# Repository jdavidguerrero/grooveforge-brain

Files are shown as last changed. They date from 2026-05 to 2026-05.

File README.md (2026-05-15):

# GrooveForge Brain

> *"Una pieza de hardware. Cinco niveles de superpoderes. Tú decidís hasta dónde llegar."*

Boutique hybrid AI synthesizer — Teensy 4.1 + ESP32-S3 + discrete 2N3904 ladder filter.

**Retail: $599 USD · BOM: ~$110 · Margin: 82%**

---

## The 5 Levels (North Star)

```
NIVEL 0 — STANDALONE   → 6 synth engines + analog ladder filter + 12 signature FX
NIVEL 1 — + MIDI KB    → Scale Lock, Chord Recognition, Beat Follower (TinyML)
NIVEL 2 — + SLAVES     → E-Drum, Marimba, Air-Bamboo ecosystem (v1.x)
NIVEL 3 — + WIFI       → Patch search NL, progression suggester (cloud AI)
NIVEL 4 — + DAW        → GroovePilot VST3 mix-aware co-pilot
```

---

## Architecture

| Component | Chip | Role |
|---|---|---|
| Audio Brain | Teensy 4.1 (Cortex-M7 @ 600MHz) | Synth engines, FX, TinyML, MIDI |
| Network + UI | ESP32-S3 + GC9A01 1.28" display | WiFi, BLE, cloud sync, OTA |
| Audio Codec | SGTL5000 | 24-bit/48kHz ADC + DAC |
| Analog Filter | Discrete 2N3904 ladder (Moog 1970) | THE analog character |

Audio path: `Teensy → I2S → SGTL5000 → 2N3904 ladder → SGTL5000 ADC → USB Audio`

---

## Monorepo Structure

```
apps/
├── firmware-teensy/   C++ — Teensy 4.1 (PlatformIO)
├── firmware-esp32/    C++ — ESP32-S3 (PlatformIO)
├── bridge-protocol/   C headers — shared protocol
├── hardware/          KiCad PCB schematics
├── design/            Industrial design (3D + Figma)
├── training/          Python — TinyML model training
└── docs/              OpenSpec documentation (SSoT)
tools/
├── matching-jig/      Arduino — transistor Vbe matching jig
└── filter-cal/        Calibration scripts
```

---

## Quick Start

```bash
# Build Teensy firmware
cd apps/firmware-teensy && pio run -e teensy41 -t upload

# Build ESP32 firmware
cd apps/firmware-esp32 && pio run -e esp32s3 -t upload

# Run tests (native, no hardware needed)
pnpm test:native

# ML training
cd apps/training && uv sync && uv run pytest
```

---

## Documentation

All specs live in [`apps/docs/`](apps/docs/README.md):

| Doc | Content |
|---|---|
| [00-master-strategy.md](apps/docs/00-master-strategy.md) | Vision, pricing, North Star |
| [01-architecture.md](apps/docs/01-architecture.md) | Hardware + software spec |
| [02-bridge-protocol.md](apps/docs/02-bridge-protocol.md) | Teensy ↔ ESP32 ↔ VST3 protocol |
| [03-filter-design.md](apps/docs/03-filter-design.md) | Discrete 2N3904 ladder filter |
| [04-ai-architecture.md](apps/docs/04-ai-architecture.md) | 3-layer AI spec |
| [05-fx-architecture.md](apps/docs/05-fx-architecture.md) | 12 signature effects |
| [06-implementation-roadmap.md](apps/docs/06-implementation-roadmap.md) | Phase & sprint plan |

---

## Status

**Phase 0 — Foundation** · May 2026 · 🟡 In Progress

| Milestone | Status |
|---|---|
| Monorepo + CLAUDE.md + agents + skills | 🟢 Done |
| Sprint 1.1 — Hello Tone (440Hz via I2S) | 🔴 Pending |
| Sprint 1.2 — Multi-OSC + ADSR | 🔴 Pending |
| Sprint 1.3 — Transistor matching jig | 🔴 Pending |
| Sprint 1.4 — Filter protoboard | 🔴 Pending |

---

*GrooveForge Brain · Juan Guerrero (GPROG) · Bogotá, Colombia · 2026*

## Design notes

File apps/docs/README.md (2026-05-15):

# 📚 GrooveForge Brain — OpenSpec Documentation Pack

> Complete spec documentation for the GrooveForge Brain boutique synthesizer.
> **Owner:** Juan Guerrero (GPROG) · Bogotá, Colombia
> **Date:** May 15, 2026

---

## 📂 Document Index

Los documentos están organizados jerárquicamente. Leélos en orden para entender el producto completo:

| # | Document | Description |
|---|---|---|
| 00 | [GFD v3.0 — Master Strategy](./00-master-strategy.md) | **Single Source of Truth** — strategy, vision, decisions |
| 01 | [OpenSpec v0.3 — Technical Spec](./01-architecture.md) | Hardware + software technical specification |
| 02 | [Bridge Protocol v0.1](./02-bridge-protocol.md) | Communication protocol Teensy ↔ ESP32 ↔ VST3 |
| 03 | [Filter Design Spec v0.1](./03-filter-design.md) | Discrete 2N3904 ladder filter spec |
| 04 | [AI Architecture v0.1](./04-ai-architecture.md) | 3-layer AI architecture (TinyML + Cloud + DAW) |
| 05 | [FX Architecture v0.1](./05-fx-architecture.md) | 12 signature effects specification |
| 06 | [Implementation Roadmap v0.1](./06-implementation-roadmap.md) | 8-phase implementation plan |
| 07 | [Claude Code Bootstrap Prompt](./07-claude-code-bootstrap-prompt.md) | Initial prompt to setup the monorepo |

---

## 🎯 Quick Reference

### Product

- **Name:** GrooveForge Brain
- **Tagline:** *"Una pieza de hardware. Cinco niveles de superpoderes. Tú decidís hasta dónde llegar."*
- **Retail price:** $599 USD
- **BOM cost (qty 100):** ~$110 USD
- **Margin:** 82% @ qty 100

### Architecture

- **Audio brain:** Teensy 4.1 (Cortex-M7 @ 600MHz, bare-metal, Teensy Audio Library)
- **Network/UI co-processor:** ESP32-S3 with GC9A01 display integrated (Waveshare module)
- **Audio codec:** SGTL5000
- **Analog filter:** Discrete 2N3904 transistor ladder (Moog Minimoog 1970 design)
- **Toolchain:** PlatformIO

### The 5 Levels (North Star)

```
NIVEL 0 — STANDALONE (out of the box)
NIVEL 1 — + TECLADO MIDI (USB-A host)
NIVEL 2 — + SLAVES via pogo (futuro v1.x)
NIVEL 3 — + WIFI (ESP32-S3 cloud)
NIVEL 4 — + DAW (GroovePilot VST3)
```

### Roadmap (15 months)

| Phase | Period | Outcome |
|---|---|---|
| Phase 0 — Foundation | May 2026 | Monorepo + tooling |
| Phase 1 — Audio Core | Jun 2026 | First engine + analog filter |
| Phase 2 — Multi-engine + FX | Jul-Aug 2026 | 3 engines + 6-8 FX |
| Phase 3 — UI + Display | Sep-Oct 2026 | Full UI working |
| Phase 4 — MIDI + TinyML | Nov-Dec 2026 | Level 1 unlocked |
| Phase 5 — WiFi + Cloud | Jan 2027 | Level 3 unlocked |
| Phase 6 — DAW Bridge | Feb-Mar 2027 | Level 4 unlocked |
| Phase 7 — PCB + Manufacturing | Apr-May 2027 | Prototypes done |
| Phase 8 — Shipping | Jun 2027+ | Batch 1 shipped |

---

## 🚀 How to Use This Documentation

### For new contributors

1. Start with **00-master-strategy.md** to understand the product vision
2. Read **01-architecture.md** for the technical contract
3. Pick your area of interest:
   - Audio/DSP → 05-fx-architecture + 03-filter-design
   - AI/ML → 04-ai-architecture
   - Communication → 02-bridge-protocol
   - Implementation order → 06-implementation-roadmap

### For Claude Code setup

Use **07-claude-code-bootstrap-prompt.md** as the initial prompt when bootstrapping the monorepo. It will set up CLAUDE.md, agents, skills, and the full project structure.

### For sprint planning

Each sprint in **06-implementation-roadmap.md** has:
- Theory section to document
- Implementation tasks
- Demo evidence to capture

Follow the educational-first philosophy: theory doc → code → demo → learnings.

---

## 🛡️ Document Authority

If there's a conflict between documents:

1. **00 GFD** wins on strategy/business decisions
2. **01 OpenSpec** wins on technical contracts
3. **03 Filter / 02 Bridge / 05 FX / 04 AI** are authoritative on their respective subsystems
4. **06 Roadmap** is a living document — adjust as needed but don't violate constraints from 01

---

## 📝 Living Documents

All these documents are versioned. As decisions evolve, increment the version (v0.1 → v0.2) and update the change log inside the doc. Never silently modify — always note what changed.

---

## 🎵 The North Star

> Standalone, the GrooveForge Brain is a complete boutique synthesizer.
> Connect a MIDI keyboard → it becomes intelligent.
> Connect slaves → it becomes an ecosystem.
> Connect WiFi → it accesses cloud AI.
> Connect to your DAW → it becomes a co-pilot.
>
> One piece of hardware. Five levels of superpowers. You decide how far to go.

---

*GrooveForge Brain · OpenSpec Documentation · Juan Guerrero (GPROG) · 2026*

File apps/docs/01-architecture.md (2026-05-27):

# 📐 GrooveForge Brain — OpenSpec v0.3

> **Canonical technical specification** for GrooveForge Brain.
> **Methodology:** OpenSpec — spec-first, source of truth for all implementation.
> **Parent:** GFD v3.0 — Master Strategy & Spec (SSoT)
> **Status:** v0.3 final — May 15, 2026
> **Author:** Juan Guerrero (GPROG)

---

## 0. Document Purpose

Esta OpenSpec define **qué es el GrooveForge Brain** a nivel técnico, no comercial. Todo el firmware, hardware design, software architecture y testing se deriva de este documento. Si hay conflicto entre este doc y código/diseño, este doc gana.

El GFD v3.0 (parent) tiene la estrategia de producto. Este doc tiene el contrato técnico.

---

## 1. Product Overview

**Name:** GrooveForge Brain
**Tagline:** *"Una pieza de hardware. Cinco niveles de superpoderes. Tú decidís hasta dónde llegar."*

### 🌟 Arquitectura modular de superpoderes incrementales (NORTH STAR)

```
NIVEL 0 — STANDALONE (out of the box, $599)
  6 emuladores + ladder filter discreto + 12 FX = synth boutique completo

NIVEL 1 — + TECLADO MIDI (USB-A host)
  Scale Lock + Chord Recognition + Auto-Harmonization + Beat Follower (TinyML)

NIVEL 2 — + SLAVES via pogo (futuro v1.x)
  E-Drum + Marimba + Air-Bamboo = ecosistema modular inteligente

NIVEL 3 — + WIFI (cloud)
  Patch search NL + progression suggester + style transfer (cloud)

NIVEL 4 — + DAW (GroovePilot VST3)
  Mix-aware + frequency conflict + layer suggestions + smart macros
```

Cada nivel es opcional. El producto base ya es completo — las capas son expansión, no requisito.

### Pricing

- Standard retail: **$599 USD**
- Pre-order primeros 200: **$549 USD**
- PTDJA student price: **$549 USD**
- Bundle con GroovePilot Pro 12mo: **$649 USD**
- BOM total qty 100: ~$110 USD
- Margen unitario @ $599 / $110 = **82%**
- Margen qty 500-1000: BOM ~$87, margen sube a **85%**

### Toolchain: PlatformIO (no Arduino IDE)

- Mismo workflow para Teensy 4.1 + ESP32-S3
- Dependency management via platformio.ini
- CI/CD friendly + VS Code integration
- Repos separados: brain-teensy/ y brain-esp32/

### Differentiators

- Único synth boutique con AI integrado por capas (no add-on)
- Discrete transistor ladder real (Moog 1970 design) a precio asequible
- Seis arquitecturas clásicas en un instrumento
- 12 signature FX diseñados para live performance
- Arquitectura modular pogo pin extensible
- Estética boutique craft (guadua + aluminum)
- Audio latency <1ms (Teensy bare-metal, sin OS jitter)
- Toolchain unificado: PlatformIO

---

## 2. System Architecture v3.0

```
┌──────────────────────────────────────────────────────────────────┐
│                    GrooveForge Brain v3.0                         │
├──────────────────────────────────────────────────────────────────┤
│                                                                    │
│  ┌────────────────┐  AUDIO BRAIN                                  │
│  │   Teensy 4.1   │  - Cortex-M7 @ 600MHz + FPU + SIMD            │
│  │                │  - Teensy Audio Library (synth engines C++)    │
│  │                │  - I2S nativo al SGTL5000 (MCLK perfecto)      │
│  │                │  - USB-C composite: Audio + MIDI + CDC         │
│  │                │  - USB-A host: teclado MIDI externo            │
│  └────────┬───────┘                                                │
│           │ I2S                                                    │
│           ▼                                                        │
│  ┌────────────────┐  AUDIO CODEC                                  │
│  │   SGTL5000     │  - 24-bit/48kHz                                │
│  │                │  - ADC + DAC en un chip                        │
│  └────────┬───────┘                                                │
│           │ Analog signal                                          │
│           ▼                                                        │
│  ┌────────────────┐  ANALOG LADDER FILTER                         │
│  │  2N3904 Ladder │  - 4-pole discrete transistor ladder           │
│  │  + TL072 x2    │  - Moog Minimoog 1970 design                   │
│  │  + CD4066      │  - SW bypass via GUI (CD4066, pin 25)           │
│  │                │  - 8 matched 2N3904 pairs                      │
│  └────────┬───────┘                                                │
│           ▼                                                        │
│  ┌────────────────┐  AUDIO OUTPUTS                                │
│  │  TRS L/R 1/4"  │  Line out balanced                            │
│  │  + Headphones  │  3.5mm TRS                                    │
│  └────────────────┘                                                │
│                                                                    │
│  ┌────────────────┐                                                │
│  │ Encoders ALPS  │  GPIO directo al Teensy                       │
│  │ Kailh switches │  4 botones (B1-B4) + 3 encoders ALPS EC11      │
│  │ WS2812B LEDs   │  16 LEDs: 12 ring ENC NAV + 4 keycap underglow │
│  │ Volume pot     │  ADC analog                                   │
│  └────────────────┘                                                │
│                                                                    │
│             ↕ UART 921600 (Bridge Protocol)                       │
│                                                                    │
│  ┌────────────────┐  NETWORK + UI CO-PROCESSOR                    │
│  │ ESP32-S3 con   │  - Módulo Waveshare ESP32-S3-Touch-LCD-1.28   │
│  │ GC9A01 1.28"   │  - Display GC9A01 240×240 integrado            │
│  │ integrado      │  - WiFi 802.11 b/g/n                          │
│  │                │  - Bluetooth 5.0 LE                           │
│  │                │  - OTA updates                                │
│  │                │  - Cloud sync presets/profiles                │
│  │                │  - Web server local config                    │
│  └────────────────┘                                                │
│                                                                    │
│  ┌────────────────┐  MODULAR EXPANSION                            │
│  │ Pogo connector │  6-pin magnetic lateral                       │
│  │                │  GrooveForge Protocol v0.1 (I2C 400kHz)        │
│  │                │  Slaves: E-Drum, Marimba, Air-Bamboo (futuro) │
│  └────────────────┘                                                │
│                                                                    │
│  ┌────────────────┐  POWER                                        │
│  │  USB-C 5V in   │  - LiPo 3000mAh + IP5306                       │
│  │  + LiPo backup │  - LC filter audio rail (10µH + 100µF)         │
│  │                │  - Analog/digital ground star separation       │
│  └────────────────┘                                                │
└──────────────────────────────────────────────────────────────────┘
```

### 2.1 Audio Signal Path — Modo Synth vs Modo FX Processor

El GrooveForge Brain opera en **dos modos exclusivos**, alternados con doble-push
del encoder NAV (ver §3.4). Cada modo tiene un camino de señal distinto. El filtro
analógico 2N3904 vive en un **loop externo al SGTL5000**: el DAC alimenta la entrada
del filtro y el retorno del filtro entra al `LINE_IN`.

**Modo Synth** — el Teensy genera audio de síntesis; pasa por el filtro analógico:

```
Teensy engine ─I2S─▶ SGTL5000 DAC ─▶ LINE_OUT ─▶ [filtro 2N3904 ladder]
                                                         │
                          SGTL5000 LINE_IN ◀─ 74HC4053 ◀─┘
                                 │
                  ┌──────────────┴──────────────┐
                  ▼                             ▼
            ADC ─▶ Teensy                 jacks de salida
            (captura USB Audio,           (ruteo interno SGTL5000)
             análisis ML)
```

El filtro analógico está disponible para **todos los engines** (`03-filter-design.md §6.1`), cada uno con cutoff/resonance defaults calibrados para su carácter sonoro. En modo Synth, todos los engines pasan por el hardware de filtro; el CD4066 (GPIO 25) permite bypass por software. Los modelos ML (Beat Follower, Chord Recognizer, Key Detector) modulan el CV del filtro para comportamiento contextual (Sprint 5B.4).

**Modo FX Processor** (estilo Roland RMX-1000) — audio externo entra por el jack
`FX IN`; el Teensy aplica los 12 FX digitales; el filtro analógico queda fuera:

```
Jack FX IN 1/4" TRS ─▶ 74HC4053 ─▶ SGTL5000 LINE_IN ─▶ ADC ─▶ Teensy FX chain
                                                                     │
              jacks de salida ◀─ SGTL5000 ◀─ LINE_OUT ◀─ DAC ◀───────┘
```

**Switch de ruteo 74HC4053 (GPIO 27):** triple SPDT que selecciona la fuente del
`LINE_IN` del SGTL5000 — retorno del filtro (Synth) o jack `FX IN` (FX Processor).
Canal A = `LINE_IN_L`, canal B = `LINE_IN_R`, canal C spare. `GPIO 27` LOW = Synth,
HIGH = FX. Análisis completo: `apps/docs/theory/audio-routing-dual-mode.md`.

**Salida:** en ambos modos los jacks de salida se alimentan desde el SGTL5000 — el
ruteo interno por I2C selecciona la fuente según el modo. No requiere switch externo.

### Key architecture decisions

| Componente | v0.2 (anterior) | v0.3 (FINAL) | Razón |
|---|---|---|---|
| Audio brain | Pi Zero 2W (Linux) | **Teensy 4.1 (bare-metal)** | MCLK nativo, latencia <1ms, no Linux complexity |
| Display + WiFi | RP2040 + GC9A01 + ESP32 | **ESP32-S3 + GC9A01 integrado** | Un solo módulo, mejor integración |
| DSP framework | Pure Data Vanilla | **Teensy Audio Library C++** | Mejor performance, fit perfecto para 6 engines fijos |
| OS | Buildroot Linux | **Sin OS (bare-metal)** | Boot <2s, deterministic |
| AI inference | Local en Pi | **Vive en GroovePilot VST3** | AI no necesita estar en Brain |
| Filtro | 2N3904 ladder discreto | **2N3904 ladder discreto** | ✅ Mantiene authentic Moog sound |
| Codec | SGTL5000 | **SGTL5000** | ✅ Mismo, ahora con MCLK perfecto |

---

## 3. Hardware Specification

### 3.1 Bill of Materials (qty 100)

| Componente | Costo | Notas técnicas |
|---|---|---|
| **Teensy 4.1** | $32.00 | Cortex-M7 @ 600MHz, 1MB RAM, FPU, native I2S |
| **ESP32-S3 con GC9A01 1.28" integrado** | $22.00 | Waveshare ESP32-S3-Touch-LCD-1.28 o equivalente |
| SGTL5000 IC standalone | $4.00 | Chip bare en PCB producción + caps + clock |
| Oscilador 12.288 MHz DIP-4 3.3V | $2.00 | Opcional — Teensy provee MCLK nativo |
| ALPS EC11 encoders x3 | $6.30 | ENC L + ENC R + ENC NAV — todos con push integrado |
| Knobs aluminum CNC x2 + 1 central | $1.80 | ENC L/R: knobs estándar; ENC NAV: knob más prominente |
| Kailh Choc V2 Brown switches x4 | $1.20 | B1-B4 (dual set keycaps: negro instalado + transparente en sobre) |
| Keycaps PBT rectangular x4 negro | $1.20 | Instalados de fábrica — sin serigrafía (display da contexto) |
| Keycaps PBT rectangular x4 transparente | $0.80 | En sobre (dual set) |
| Keycap circular custom PETG/PBT x1 | $0.50 | ENC NAV — diseño Juan, icono ● grabado láser |
| WS2812B-2020 SMD x16 | $1.20 | 12 ring ENC NAV + 4 keycap underglow — cadena única, 1 pin Teensy |
| Volume pot 10kΩ log + knob | $1.00 | Panel mount + aluminum knob |
| USB-C + USB-A connectors | $0.80 | USB-C device, USB-A host |
| Audio jacks 1/4" TRS x2 (output L/R) | $3.60 | Switched ground |
| Audio jacks 1/4" TRS x2 (FX IN L/R) | $3.60 | Entrada Modo FX Processor — estéreo |
| Audio jack 3.5mm x1 (headphones) | $0.60 | Headphones |
| **74HC4053 triple SPDT analog switch** | **$0.35** | Ruteo audio Synth/FX — GPIO 27 |
| LiPo 3000mAh + IP5306 + LC filter | $9.00 | Battery operation + audio rail filter |
| **2N3904 NPN x12 (matched pairs)** | **$0.60** | 8 ladder + 4 spare/exp converter |
| **TL072 dual opamp x2** | **$0.80** | Input/output buffers + CV converter |
| **CD4066 quad analog switch** | **$0.30** | Software bypass control |
| ~~Toggle switch TPDT panel-mount~~ | ~~$0.50~~ | ~~Eliminado — bypass 100% software vía CD4066~~ |
| **Capacitors 1nF polystyrene x4 + passives** | **$1.30** | Filter timing caps + trimmers + resistors |
| ~~Resonance pot 10kΩ log~~ | ~~$0.80~~ | ~~Eliminado — resonance controlada por ENC R (digital)~~ |
| **Filter PCB sub-block 30x40mm** | **$0.50** | 2-layer |
| Pogo connector 6-pin magnetic | $1.50 | Würth o equivalente |
| PCB principal 4-layer 180x100mm | $6.00 | Audio + digital + power planes |
| Enclosure PETG print | $5.00 | Color-stable PETG |
| Aluminum top panel CNC | $6.00 | 2mm anodizado, Bogotá |
| Guadua panel finished | $2.50 | Local sourcing + sealing |
| Passives + cables + screws + misc | $4.50 | Resistores + caps + standoffs |
| **Subtotal componentes** | **~$113** | Incluye 74HC4053 + jack FX IN 1/4" (Modo FX Processor) |
| Ensamblaje + QC + filter cal | $10.00 | Filter cal 5-7 min/unidad |
| **TOTAL per unit (qty 100)** | **~$123** | |

> **Volumen 500-1000u:** BOM baja a ~$90
> **Volumen 1000+:** BOM baja a ~$78

### 3.2 Power Architecture

```
USB-C 5V input ──┬──▶ IP5306 (charge)
                 │       │
                 │       ▼
                 │   LiPo 3.7V 3000mAh
                 │       │
                 │       ▼
                 │   IP5306 (boost 5V)
                 │       │
                 ▼       ▼
              ┌──────────────┐
              │  Power Rail   │
              │     5V        │
              └──────┬───────┘
                     │
           ┌─────────┼─────────┬─────────┐
           ▼         ▼         ▼         ▼
        Teensy 4.1  ESP32-S3  LCD/LEDs  USB-A host
        (5V→3.3V    (5V→3.3V             (5V passthrough)
        internal)   internal)

        ┌──────────────────────┐
        │   LC Filter audio    │
        │   10µH + 100µF       │
        │   MANDATORY          │
        └──────────┬───────────┘
                   ▼
              ┌──────────┐
              │ SGTL5000 │
              │ + 2N3904 │ ladder filter
              │ + TL072  │
              └──────────┘

        Analog GND ━━━ star ground point ━━━ Digital GND
```

**Critical rules:**
- LC filter (10µH + 100µF) entre digital 5V y audio rail
- Star ground: analog GND y digital GND conectan en UN punto físico cerca del SGTL5000
- Teensy y ESP32-S3 corren de digital 5V (regulación interna a 3.3V)
- SGTL5000 + filter discreto corren de audio 5V filtered
- Battery debe soportar pico ~500mA (Teensy + ESP32 + LEDs + WiFi TX simultáneo)

### 3.3 Pin Mapping

**Teensy 4.1 GPIO usage:**

| Pin | Function | Conexión |
|---|---|---|
| 23 | MCLK out | SGTL5000 master clock (nativo desde Teensy I2S1_MCLK) |
| 7 | I2S1_TX_DATA0 (OUT1A) | SGTL5000 DAC input |
| 8 | I2S1_RX_DATA0 (IN1) | SGTL5000 ADC output |
| 20 | I2S1_LRCLK | SGTL5000 LRCLK |
| 21 | I2S1_BCLK | SGTL5000 BCLK |
| 18 | I2C1 SDA | SGTL5000 control |
| 19 | I2C1 SCL | SGTL5000 control |
| 0 | UART RX | ← ESP32-S3 TX |
| 1 | UART TX | → ESP32-S3 RX |
| 2-5 | GPIO | 4 Kailh Choc V2 switches B1-B4 (pulled-up) |
| 10-11 | GPIO | ENC L: A / B (rotary phases) |
| 12 | GPIO | ENC L: SW (push — filter bypass toggle) |
| 13 | GPIO | ENC R: A |
| 14 | GPIO | ENC R: B |
| 15 | GPIO | ENC R: SW (push — resonance reset a 0) |
| 16 | GPIO | ENC NAV: A |
| 17 | GPIO | ENC NAV: B |
| 26 | GPIO | ENC NAV: SW (push — confirm / AI·Action / double-push = mode switch) |
| 25 | GPIO | Filter bypass control (CD4066 enable — ENC L push via firmware) |
| 27 | GPIO | 74HC4053 mode select — ruteo audio Synth/FX (LOW=Synth, HIGH=FX) |
| 28 | WS2812B DIN | 16 LEDs cadena única: 12 ring ENC NAV + 4 keycap underglow |
| A0 (14) | ADC | Volume pot read |
| 36 | GPIO | Pogo INT in (slave interrupt) |
| 37/38 | I2C2 SDA/SCL | Pogo bus master (slaves) |
| 39 | GPIO | USB host mode select |

> **Nota I2S (Teensy 4.x):** los pines de datos I2S son 7 (`SAI1 OUT1A`, TX → DAC)
> y 8 (`SAI1 IN1`, RX ← ADC) — los del Audio Shield Rev D2. La Rev C / Teensy 3.x
> usaba 22/13; con este mapping los pines 13 y 22 quedan libres.

**ESP32-S3 (Waveshare ESP32-S3-Touch-LCD-1.28):**

| Pin | Function | Conexión |
|---|---|---|
| GPIO 17 | UART TX (Serial1) | → Teensy RX (pin 0) |
| GPIO 16 | UART RX (Serial1) | ← Teensy TX (pin 1) |
| GPIO 43 | UART0 TX (Serial debug) | USB-UART bridge interno — NO usar para bridge |
| GPIO 44 | UART0 RX (Serial debug) | USB-UART bridge interno — NO usar para bridge |
| GPIO 7/8/9/10/11/12 | SPI display | GC9A01 (internal connection) |
| GPIO 13 | Touch I2C SDA | Touch controller (si touch version) |
| GPIO 14 | Touch I2C SCL | Touch controller |
| GPIO 18 | Display backlight PWM | GC9A01 backlight |
| (Internal) | WiFi + BT | 802.11 b/g/n + BT 5.0 LE |

### 3.4 UI Controls Spec — Panel v5 Final

> **SSoT:** Notion "Hardware UI Spec — CERRADO (Panel v5 Final)" · Mayo 17, 2026

**Filosofía:** minimalista boutique — 3 encoders + 4 botones + 1 vol pot. Más cercano al OP-1 que al Elektron.

#### Inventario de controles

| ID | Tipo | Turn | Push |
|---|---|---|---|
| ENC L | ALPS EC11 | Synth: Cutoff / FX: Dry-Wet | Filter bypass toggle |
| ENC R | ALPS EC11 | Synth: Resonance / FX: Depth/param principal | Resonance reset a 0 |
| ENC NAV | ALPS EC11 | Navegar menú / páginas / FX | 1× confirm/AI·Action · 2× rápido = modo SYNTH↔FX |
| B1-B4 | Kailh Choc V2 Brown | — | Synth: OSC/ENV/LFO/PRESET · FX: INSERT/SEND/MASTER/slot |
| VOL | Pot 10kΩ log | Volumen salida (siempre, no cambia con modo) | — |

#### Modo SYNTH

```
ENC L    → Cutoff del filtro analógico discreto 2N3904
ENC R    → Resonance
ENC NAV  → Navegar páginas del synth (OSC / ENV / LFO/MOD / ENGINE / PRESET)
ENC L push  → Filter bypass CD4066 ON/OFF (pin 25)
ENC R push  → Resonance reset a 0
ENC NAV push → Confirm / AI·Action (escala al nivel activo: 0=menú, 1=Scale Lock, 3=cloud, 4=DAW)
B1=OSC · B2=ENV · B3=LFO/MOD · B4=PRESET/ENGINE
```

#### Modo FX (RMX-1000 inspired)

```
ENC L    → Dry/Wet del FX activo
ENC R    → Parámetro principal del FX activo (definido por cada FX)
ENC NAV  → Scroll entre los 12 FX disponibles
ENC NAV push → Activar/desactivar FX seleccionado
B1=INSERT · B2=SEND · B3=MASTER · B4=FX slot favorito
```

**Cambio de modo:** doble push ENC NAV (≤ 2 s)

#### LED ring ENC NAV (12× WS2812B-2020 SMD)

| Estado | Animación | Color |
|---|---|---|
| Synth mode | Pulso suave | Teal `#1D9E75` |
| FX mode | Pulso suave | Purple `#534AB7` |
| Cambio de modo | Sweep 360° | Teal → Purple |
| IA procesando | Giro rápido | Teal brillante |
| Sugerencia lista | 3 pulsos + fijo | Teal |
| DAW conectado | Fijo | Purple |
| Error / sin conexión | Pulso lento | Rojo |
| Scale Lock activo | Fijo | Verde |

#### ENC R mapping por FX (parámetro principal en FX mode)

| FX | ENC L (Dry/Wet) | ENC R (Depth/param) |
|---|---|---|
| Cymatic Resonator | Mix | Resonance (Q) |
| Granular Cloud | Mix | Size (grain duration) |
| Ghost Echo | Mix | Feedback |
| Spectral Smear | Mix | Smear time |
| **Tape Saturate** | **Mix** | **Drive** |
| Bit Sculpt | Mix | Bits |
| Modal Reverb | Mix | Decay |
| Phase Chorus | Mix | Depth |
| Pitch Mosaic | Mix | Interval 1 |
| Spring + Plate | Mix | Decay |
| Glitch Stutter | Mix | Pattern division |
| Sub Genesis | Mix | Sub level |

### 3.5 Discrete 2N3904 Ladder Filter Design

**Topology:** 4-pole low-pass transistor ladder (Moog Minimoog 1970 reference)

Ver doc separado: **🎚️ Filter Design Spec v0.1** para detalles completos.

**Specifications:**
- Cutoff range: 20Hz - 20kHz (5+ decades)
- Resonance: 0 (flat) to self-oscillation
- V/oct tracking: ±10 cents over 5 octaves (post-calibration)
- Bypass: CD4066 software bypass controlado por GUI (Bridge Protocol → Teensy pin 25)
- Input impedance: 100kΩ
- Output level: matched a SGTL5000 ADC input range (~1Vrms line level)
- THD @ 1kHz, 0dBu: <0.5% (low resonance), <2% (high resonance, intentional)
- Self-oscillation threshold: 80% resonance pot ±5%

**Engine routing per engine:**

| Engine | Filter default | Sound | User override |
|---|---|---|---|
| Moog Model D | ON | Auténtico Moog | Yes |
| Juno-106 | ON | Juno + Moog warmth | Yes |
| Prophet-5 | ON | Prophet + Moog warmth | Yes |
| OB-6 | ON | OB-6 + Moog warmth | Yes |
| DX7 | **OFF** | Clean FM | Yes (toggle ON for "warmed FM") |
| ARP 2600 | ON | ARP + Moog warmth | Yes |

### 3.6 Top Panel PCB Architecture

> **Decisión:** 2026-05-27. Documentado por primera vez aquí.

#### Problema

Los encoders (ENC1, ENC2, ENC NAV) y los botones (B1-B4) están montados sobre el top
panel de aluminio, que tiene **BODY_H_F=42mm de altura**. La PCB principal (Teensy) está
en el fondo del PETG body. Conectar componentes del top panel directamente a la main PCB
requeriría cables cortos en ángulo o una PCB rígida que no cabe en el espacio.

#### Decisión: 2-PCB approach

| PCB | Nombre | Dimensión estimada | Contenido | Conexión |
|-----|---|---|---|---|
| Main PCB | `groovebrain-main` | 168×88mm | Teensy 4.1, SGTL5000, power, jacks, USB | — |
| Top Panel PCB | `groovebrain-panel` | ~130×25mm | ENC1, ENC2, ENC NAV, B1-B4, WS2812B ring | JST ribbon → main PCB |

**Top Panel PCB** es una PCB delgada (~25mm de alto) que se monta bajo el aluminio:
- Footprints EC11 para los 3 encoders (ENC NAV tiene 4 pads extra para WS2812B data + 5V)
- Footprints Kailh Choc V2 para los 4 botones (retroiluminados — 2 pads extra por switch)
- Header JST-SH 1.0mm (o similar) de N pines hacia la main PCB
- 4 agujeros M2.5 para tornillos que fijan la PCB bajo el panel de aluminio

**ENC NAV vs ENC1/ENC2 en la misma PCB:**
- ENC NAV footprint: 3 pines encoder + 2 pines LED ring (data WS2812B + GND)
- ENC1/ENC2 footprint: solo 3 pines encoder — el pad de ring simplemente no se popula
- Una sola PCB sirve para las 3 posiciones de encoder

#### Layout del panel v0.5 (SSoT)

```
Y_panel (0=trasero, 100=frontal)
  100 ──────────────────────────────────────────────── frente del instrumento
        [VOL]                               (X=22, Y=14)
   22   ──────── [ENCNAV]  ────────────────            (X=90, Y=22)
        ───── LED ring ────                            (X=90, Y=22, Ø32mm)

   44   [ENC1]  [B2]       DISPLAY   [B4]  [ENC2]     Y=44: botones inferiores
        X=22    X=52        X=90      X=128  X=158
   55   [ENC1]                               [ENC2]    Y=55: encoders laterales
   60           DISPLAY                                Y=60: display center
   66   [ENC1]  [B1]       DISPLAY   [B3]  [ENC2]     Y=66: botones superiores

  ...
    0 ──────── panel trasero
```

**Asignación de botones:**

| ID | Posición | X_panel | Y_panel | Modo SYNTH | Modo FX |
|----|---|---|---|---|---|
| B1 | col izq, superior | 52mm | 66mm | OSC | INSERT |
| B2 | col izq, inferior | 52mm | 44mm | ENV | SEND |
| B3 | col der, superior | 128mm | 66mm | LFO/MOD | MASTER |
| B4 | col der, inferior | 128mm | 44mm | PRESET/ENGINE | FX slot fav |

#### Módulo display (Waveshare ESP32-S3-Touch-LCD-1.28) — dimensiones verificadas por datasheet

| Parámetro | Valor | Fuente |
|---|---|---|
| Vidrio OD (LENS OD) | Ø38.51mm | Waveshare datasheet |
| Viewing area activa | Ø35.67mm | Waveshare datasheet |
| PCB circular | Ø41mm | Waveshare datasheet |
| Stack TP+LCD height | 3.58mm | Waveshare datasheet |

**Concepto de instalación (corrección v0.5):** El módulo va **debajo** del panel de aluminio:
- El cutout Ø36mm en el aluminio es una **ventana** — ni el vidrio (38.51mm) ni el PCB (41mm) pasan por él
- El vidrio del módulo se presiona contra la **cara inferior** del aluminio, mirando hacia arriba
- El labio del vidrio (38.51mm OD) impide que el módulo caiga por el cutout (36mm < 38.51mm)
- Desde arriba: el usuario ve el display circular recesado 2mm (grosor del aluminio) — efecto estético limpio
- El **display bracket (Part 05)** retiene el módulo desde abajo, presionándolo contra el aluminio:
  - Cavity circular ≥ Ø41mm para el PCB
  - Altura = BRACKET_H = 15mm (desde PCB principal hasta cara inferior del top panel)

Los pines UART (GPIO43/44) del ESP32-S3 se cablan directamente a la main PCB (Teensy)
via cable que desciende por el interior del bracket y el PETG body.
El Top Panel PCB **no lleva** conector para la pantalla.

#### Prototipo v1 vs PCB v1.0

| Fase | Implementación |
|---|---|
| **Prototipo v1** (actual) | Cables directos de cada encoder/botón a la main PCB. Sin Top Panel PCB. Complejidad de cableado: ~18 señales. |
| **PCB v1.0** | Top Panel PCB fabricada. JST ribbon de 18-22 pines. Cableado limpio. |

---

## 4. Software Architecture

### 4.1 Teensy 4.1 (Audio Brain)

**Framework:** PlatformIO + Arduino framework + Teensyduino + Teensy Audio Library

**Synth engines (v1.0 ship con 3, expandible):**

| Engine | Status | Implementation |
|---|---|---|
| Moog Model D | Ship v1.0 | AudioSynthWaveform x3 + AudioMixer4 + AudioEffectEnvelope + filter routing |
| Juno-106 | Ship v1.0 | AudioSynthWaveform + sub osc + AudioEffectChorus + filter routing |
| Prophet-5 | Ship v1.0 | AudioSynthWaveform x2 + cross-mod + filter routing |
| OB-6 | v1.1 (Q1 2027) free update | AudioSynthWaveform x2 + AudioSynthWaveformDc + filter |
| DX7 | v1.2 (Q2 2027) free update | AudioSynthWaveformPWM x6 (FM operators) + filter bypass |
| ARP 2600 | v1.3 (Q3 2027) free update | AudioSynthWaveform + AudioEffectRingMod + filter |

**Polyphony targets:**
- Moog Model D: 6 voces simultáneas
- Juno-106: 8 voces simultáneas
- Prophet-5: 5 voces simultáneas
- CPU usage @ 6 voces simultáneas: ~30% Teensy 4.1
- Headroom para FX adicionales: ~70%

### 4.2 ESP32-S3 (Network + UI Co-processor)

**Framework:** PlatformIO + Arduino (ESP32 board package) + LVGL

**Tasks:**
- WiFi management (connect, reconnect, OTA check)
- Bluetooth LE (MIDI BLE optional, file transfer)
- HTTP client to grooveforge.com cloud API
- Local web server para configuration (port 80, mDNS as `groovebrain.local`)
- Display driver GC9A01 (rendering UI based on state from Teensy)
- UART communication con Teensy @ 921600 baud (Bridge Protocol)

### 4.3 Bridge Protocol v0.1

Protocolo binario sobre UART (Teensy ↔ ESP32) y USB-CDC (Teensy ↔ VST3 host).

```
[CMD][LEN][SEQ][PAYLOAD][CRC8]
```

Ver doc separado: **🔌 Bridge Protocol v0.1 — Spec**

**Communication paths:**

```
VST3 plugin ←─ USB-CDC ─→ Teensy 4.1 ←─ UART ─→ ESP32-S3 ←─ WiFi ─→ GroovePilot cloud
```

Teensy es el master del Bridge Protocol. ESP32 actúa como proxy network layer.

### 4.4 OTA Updates

- ESP32-S3 maneja WiFi connectivity
- Check de updates contra https://updates.grooveforge.com
- ESP32 descarga firmware delta + checksum
- ESP32 puede flashear Teensy via UART + reset GPIO (Teensy bootloader UART)
- ESP32 flashea su propio firmware (OTA partition)
- Rollback automático si boot falla 3 veces consecutivas

---

## 5. Acceptance Criteria

### 5.1 Hardware acceptance (per unit, prod line)

- [ ] Boot completo a synth selector en <2 segundos
- [ ] Audio out detectable en 1/4" L/R con test tone (-12dBFS sin distortion)
- [ ] USB-C reconocido como composite device (Audio + MIDI + CDC) en macOS/Win/Linux
- [ ] USB-A host detecta teclado MIDI clase-compliant
- [ ] WiFi conecta a network conocido en <5 segundos
- [ ] Battery dura ≥2.5h en modo standalone con volumen 75%
- [ ] LiPo charge time <3h desde 0% a 100%
- [ ] LC filter mide >40dB atenuación noise digital en audio rail @ 100MHz
- [ ] Display GC9A01 muestra splash en <500ms post-boot
- [ ] 6 Kailh switches responden con WS2812B feedback inmediato
- [ ] 2 encoders track ±1 detent precision
- [ ] Action button + LED ring funcional
- [ ] Pogo connector multimetro: continuidad 6 pines, no shorts
- [ ] **Filter: cutoff sweep audible 20Hz-20kHz**
- [ ] **Filter: self-oscillates con resonance al 80% pot**
- [ ] **Filter: software bypass CD4066 sin clicks audibles al switch (GUI → pin 25)**
- [ ] **Filter: V/oct tracking ±20 cents over 5 octaves (post-calibration)**

### 5.2 Software acceptance (per release)

- [ ] Boot time Teensy + ESP32 < 2 segundos
- [ ] Audio latency: USB MIDI input → audio out <5ms p95
- [ ] Engine polyphony: Moog 6 voces, Juno 8 voces, Prophet 5 voces sin xruns
- [ ] CPU usage Teensy ≤60% en uso normal
- [ ] Bridge Protocol latency: command → ack <50ms p95
- [ ] OTA update completo (download + flash + reboot) <5 min
- [ ] OTA rollback funciona si boot falla 3 veces
- [ ] Pogo slave hot-plug detected en <5 segundos
- [ ] WiFi reconnect automático tras disconnect

### 5.3 Audio quality acceptance

- [ ] THD+N audio path total <0.1% @ 1kHz, -12dBFS (filter bypass)
- [ ] SNR audio path >90dB A-weighted
- [ ] Frequency response: ±0.5dB de 20Hz-20kHz (filter bypass)
- [ ] Channel crosstalk L/R <-80dB @ 1kHz
- [ ] Noise floor con todo conectado silenciado: <-95dBFS
- [ ] Filter resonance peak: ≥+20dB sobre nominal at self-oscillation
- [ ] Filter V/oct tracking: ±20 cents over 5 octaves (post-calibration)

---

## 6. Build Instructions (Dev)

### 6.1 Bootstrap dev environment

```bash
# Instalar VS Code + PlatformIO extension
# https://platformio.org/install/ide?install=vscode

# Clone repos
git clone git@github.com:gprog/grooveforge-brain.git
cd grooveforge-brain
```

### 6.2 First audio test (Teensy + Audio Shield)

```cpp
#include <Audio.h>
#include <Wire.h>
#include <SPI.h>

AudioSynthWaveform    sine;
AudioOutputI2S        audioOut;
AudioControlSGTL5000  codec;

AudioConnection c1(sine, 0, audioOut, 0);
AudioConnection c2(sine, 0, audioOut, 1);

void setup() {
    AudioMemory(8);
    codec.enable();
    codec.volume(0.5);
    sine.begin(WAVEFORM_SINE);
    sine.frequency(440);
    sine.amplitude(0.8);
}

void loop() {}
```

`platformio.ini`:
```ini
[env:teensy41]
platform = teensy
board = teensy41
framework = arduino
lib_deps =
    PaulStoffregen/Audio
    PaulStoffregen/Encoder
    PaulStoffregen/Bounce2
monitor_speed = 115200
build_flags =
    -DUSB_MIDI_AUDIO_SERIAL
```

Flash al Teensy 4.1. Conectar headphones al jack del Audio Shield. Tono 440Hz inmediato.

### 6.3 ESP32-S3 display test

```cpp
#include <TFT_eSPI.h>
TFT_eSPI tft = TFT_eSPI();

void setup() {
    tft.init();
    tft.setRotation(0);
    tft.fillScreen(TFT_BLACK);
    tft.setTextColor(TFT_GREEN);
    tft.setTextSize(2);
    tft.setCursor(40, 100);
    tft.print("GROOVEFORGE");
    tft.setCursor(70, 130);
    tft.print("BRAIN v3.0");
}

void loop() {}
```

---

## 7. Roadmap & Milestones (overview)

Detalles en doc separado: **📖 Implementation Roadmap v0.1**

| Milestone | Target | Status |
|---|---|---|
| Teensy 4.1 + Audio Shield primer tono via Audio Library | Semana 1 | 🔴 Pending |
| Filter discreto 2N3904 protoboard + matching jig Arduino | Semana 2-3 | 🔴 Pending |
| Primer engine Moog Model D en Teensy Audio Library | Semana 4 | 🔴 Pending |
| A/B test: filter digital vs filter discreto analog | Semana 5 | 🔴 Pending |
| ESP32-S3 display + UART communication con Teensy | Semana 6 | 🔴 Pending |
| Engine #2 (Juno-106) + Engine #3 (Prophet-5) | Mes 3-4 | 🔴 Pending |
| PCB v0.1 schematic completo en KiCad | Mes 5 | 🔴 Pending |
| PCB v0.1 fabricated + prototype hand-soldered | Mes 6 | 🔴 Pending |
| End-to-end prototype completo | Mes 7 | 🔴 Pending |
| Pre-order page abierta | Mes 8 | 🔴 Pending |
| Alpha 10 units enviadas a beta testers | Mes 9 | 🔴 Pending |
| Manufactura batch 1 JLCPCB SMT | Mes 11 | 🔴 Pending |
| Shipping batch 1 | Mes 12 | 🔴 Pending |
| v1.1 OB-6 engine free update | Mes 14 | 🔴 Pending |

---

## 8. Risks & Mitigations

| Riesgo | Probabilidad | Impacto | Mitigación |
|---|---|---|---|
| Teensy 4.1 supply crisis | Baja | Alto | PJRC supply stable. Alternative: STM32H7 con custom audio framework. |
| ESP32-S3 supply crisis | Baja | Medio | Alternativa: RP2040 + display GC9A01 separado |
| Teensy Audio Library limitations | Baja | Medio | Alternativa: bare-metal con CMSIS-DSP. PJRC mantiene library activamente. |
| Filter discreto matching más complejo de lo esperado | Media | Bajo | Jig procedure documentado. 10-15% reject rate aceptable. |
| Audio quality SGTL5000 insuficiente | Baja | Medio | Upgrade path: AKM AK4493 + ADC separado en v2.0 |
| FCC/CE certification block exports | Alta | Medio | Sell desde Colombia con "educational use" disclaimer |
| Burnout Juan por scope | Media | Alto | Gates duros de pausa cada 30 días |

---

## 9. Document History

| Version | Date | Changes |
|---|---|---|
| v0.1 | Mayo 2026 | Initial draft — Pi Zero 2W + RP2040 + LM13700 dual-SKU |
| v0.2 | Mayo 2026 | Single SKU + discrete 2N3904 ladder filter (Pi Zero 2W kept) |
| **v0.3** | **Mayo 15, 2026** | **PIVOT FINAL: Teensy 4.1 + ESP32-S3 + discrete 2N3904 ladder. Pi Zero 2W eliminado. Teensy Audio Library para engines. Retail $599.** |

---

*End of GrooveForge Brain — OpenSpec v0.3 FINAL*
*Canonical technical spec · GrooveForge Brain v3.0*
*Juan Guerrero (GPROG) · Bogotá, Colombia*

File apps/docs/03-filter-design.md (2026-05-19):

# 🎚️ GrooveForge Brain — Filter Design Spec v0.1

> **Discrete 2N3904 transistor ladder filter specification.**
> **Parent:** GFD v3.0 — Master Strategy & Spec
> **Sibling:** OpenSpec v0.3
> **Status:** v0.1 — Mayo 15, 2026
> **Reference design:** Moog Minimoog 1970 (Bob Moog's original transistor ladder)

---

## 0. Filosofía del diseño

El filter analógico es **el corazón sonoro del GrooveForge Brain**. Es lo que justifica el posicionamiento "Moog quality por $599" — no es un emulación digital, es el mismo circuito que usó Bob Moog en 1970.

Cualquier productor que conoce el sonido Moog reconoce inmediatamente la diferencia entre un filter digital (incluso el mejor IIR/FIR) y un filter discreto con transistores reales. Ese reconocimiento es nuestro diferenciador.

---

## 1. Topology

### 1.1 Architecture overview

```
Audio in ──[buffer TL072]──▶ Stage 1 (Q1/Q2 differential pair)
                                    │
                                    ▼ + cap 1nF polystyrene
                              Stage 2 (Q3/Q4)
                                    │
                                    ▼ + cap 1nF polystyrene
                              Stage 3 (Q5/Q6)
                                    │
                                    ▼ + cap 1nF polystyrene
                              Stage 4 (Q7/Q8)
                                    │
                                    ▼
                            [Output buffer TL072]
                                    │
                                    ├──▶ Resonance feedback to Stage 1
                                    │
                                    ▼
                            [CD4066 software bypass]
                                    │
                                    ▼
                            [TPDT hardware bypass toggle]
                                    │
                                    ▼
                              Audio out (to SGTL5000 ADC)

  Cutoff CV ───▶ [TL072 exp converter] ───▶ Stage emitter currents (Q1-Q8)
  Resonance pot ────────────────────────▶ Feedback amount (output → input)
  V/oct trim ──────────────────────────▶ Exp converter scale
  Cutoff range trim ───────────────────▶ Exp converter offset
  Resonance trim ──────────────────────▶ Max feedback gain
  Bypass level trim ───────────────────▶ Bypass path unity-gain matching
  Teensy GPIO 25 ──▶ [CD4066 enable] ──▶ Software bypass control
```

### 1.2 Por qué transistor ladder?

- **4-pole low-pass (24dB/oct):** la steepness signature del Moog sound
- **Voltage-controlled:** permite modulation rápida via CV (LFO, envelope)
- **Self-oscillating resonance:** característica de Moog que digital filters emulan pobremente
- **Analog warmth:** distorsión harmonic suave bajo alta resonance
- **No aliasing:** no hay sample rate limitations

### 1.3 Por qué 2N3904 (no especializado)?

- **Disponibilidad:** 2N3904 es el transistor más común del mundo, supply infinito
- **Costo:** $0.05/unidad en cantidad
- **Matching:** procesando 100-150 transistores podemos obtener 8 pairs con ΔVbe<2mV
- **Performance:** suficiente noise/distortion specs para audio quality boutique
- **Reproducibility:** cualquier maker puede fabricar este filter sin componentes raros

Alternatives consideradas y descartadas:
- **CA3046 / CA3086 transistor array:** mejor matching de fábrica, pero EOL (discontinuado)
- **THAT300P:** matched pairs garantizados, pero $5/pair = no escala
- **MAT12 / SSM2210:** ideal pero $15+ y disponibilidad incierta

---

## 2. Specifications

### 2.1 Audio specifications

| Spec | Target | Notes |
|---|---|---|
| Cutoff range | 20Hz - 20kHz | 5+ decades |
| Resonance | 0 (flat) to self-oscillation | Self-osc threshold 80% pot |
| V/oct tracking | ±10 cents over 5 octaves | Post-calibration |
| Input impedance | 100kΩ | Standard line-level |
| Output level | ~1Vrms | Matched a SGTL5000 ADC input |
| THD @ 1kHz, 0dBu | <0.5% (low res), <2% (high res) | Intentional character |
| Roll-off | 24dB/oct | 4-pole architecture |

### 2.2 Bypass behavior

| Bypass type | Latency | Audio path |
|---|---|---|
| Software (CD4066) | <1ms | DAC → CD4066 → ADC (bypassing filter) |
| Hardware (TPDT) | 0ms (true bypass) | DAC → ADC directo (cable connection) |

Hardware TPDT siempre toma precedencia (master override).

---

## 3. Bill of Materials (per unit)

### 3.1 Active components

| Component | Qty | Purpose | Cost |
|---|---|---|---|
| 2N3904 NPN transistor (matched) | 8 | Ladder differential pairs (Q1-Q8) | $0.40 |
| 2N3904 NPN transistor (spare/converter) | 4 | Exp converter CV input | $0.20 |
| TL072 dual opamp | 2 | Input/output buffers + CV converter | $0.80 |
| CD4066 quad analog switch | 1 | Software bypass control | $0.30 |

### 3.2 Passive components

| Component | Qty | Purpose | Cost |
|---|---|---|---|
| Capacitor 1nF polystyrene | 4 | Timing caps between stages | $0.60 |
| Resistor 1% metal film (various) | 30 | Bias network + signal path | $0.30 |
| Trimmer 10kΩ multi-turn | 4 | Calibration (cutoff, V/oct, res, bypass) | $1.00 |
| ~~Pot 10kΩ logarítmico panel~~ | ~~1~~ | ~~Resonance control user~~ — **eliminado: resonance controlada por ENC R (digital)** | ~~$0.80~~ |

### 3.3 Control & UI

| Component | Qty | Purpose | Cost |
|---|---|---|---|
| Toggle switch TPDT panel | 1 | Hardware bypass master | $0.50 |

### 3.4 PCB

| Component | Qty | Purpose | Cost |
|---|---|---|---|
| Filter PCB sub-block 30x40mm | 1 | 2-layer dedicated filter PCB | $0.50 |

**Total filter BOM: ~$5.40 per unit**

---

## 4. Transistor Matching Procedure

### 4.1 Theory

Vbe (voltage base-emitter) at constant collector current is the key parameter that determines how a transistor responds in a differential pair configuration. If Q1 and Q2 have different Vbe at the same current, the pair will have offset and distortion that translates to filter non-linearity.

**Target:** ΔVbe < 2mV at 100µA collector current, 25°C.

### 4.2 Matching jig (Arduino-based)

```
                  +5V
                   │
                  [33kΩ]
                   │
                   ├──── Vbase
                  [Q test]  (in DIP socket / ZIF)
                   │
                  ─── (collector to Vcc through 47kΩ to set 100µA)
                   │
                  Veb (to Arduino ADC)
                   │
                  GND
```

Arduino sketch reads Vbe via ADC, displays in mV, logs to serial.

### 4.3 Procedure

1. Insert transistor #1 into socket
2. Read Vbe (e.g. 612.4 mV)
3. Press button → store value with index
4. Insert transistor #2 → read → store
5. Repeat for batch of 100 transistors (~30 min)
6. Software sorts and groups into pairs with ΔVbe < 2mV
7. Output: 8-10 matched pairs labeled (e.g. "Pair A: T034 + T067 = 612.4/612.8 mV")
8. Reject rate: 10-15% of batch

### 4.4 Tools needed

- Arduino UNO/Nano
- DIP-8 socket o ZIF socket for TO-92
- 2× pulsador momentáneo
- 2× LED + resistores 330Ω
- LCD 16x2 (opcional, mejor UX que solo Serial)
- Breadboard grande
- 100-150 2N3904 transistores

---

## 5. Calibration Procedure

Each filter (after assembly) needs 5-step calibration to meet spec.

### 5.1 Cutoff range (R_offset trim)

**Goal:** sweep 20Hz to 20kHz with CV from 0V to +5V.

1. Apply 0V CV, sine 220Hz signal input
2. Adjust R_offset trim until cutoff is at 20Hz (signal heavily attenuated)
3. Apply +5V CV, verify cutoff at ~20kHz (signal mostly unattenuated)
4. Iterate as needed

### 5.2 V/oct tracking (R_voct trim)

**Goal:** ±10 cents tracking over 5 octaves.

1. Apply CV at A1 reference (110Hz)
2. Set cutoff just above 110Hz, measure phase shift
3. Apply CV at A6 reference (1760Hz)
4. Verify cutoff at corresponding frequency
5. Adjust R_voct until error within 10 cents per octave
6. Iterate

### 5.3 Resonance (R_res trim)

**Goal:** self-oscillation at 80% resonance pot.

1. Disconnect input signal
2. Turn resonance pot to 100%
3. Adjust R_res until filter starts self-oscillating
4. Reduce pot to 80% — should be just at threshold
5. Verify oscillation amplitude is reasonable (not clipping)

### 5.4 Bypass level (R_bypass trim)

**Goal:** unity gain between filter active and bypass (no level jump on switch).

1. Apply 1Vrms test signal at 1kHz
2. Filter active, no resonance: measure output
3. Activate bypass: measure output
4. Adjust R_bypass until levels match within 0.5dB
5. Verify across frequency sweep (no spectral imbalance)

### 5.5 Pass/fail verification

Final QA:
- Sweep 20Hz-20kHz, no clicks/discontinuities
- Self-oscillation clean (no clipping at 80% pot)
- Bypass transition silent (no audible click)
- THD measured at 1kHz, 0dBu, low res: <0.5%

**Time per unit:** 5-7 minutes with calibration jig.

---

## 6. Engine Integration

### 6.1 Filter routing per engine

El filtro analógico 2N3904 está disponible para **todos los engines**. Es el diferenciador
central del producto — convierte cualquier engine digital en un instrumento con carácter
analógico real. Cada engine tiene un punto de partida (cutoff/resonance default) calibrado
para su identidad sonora; el usuario puede ajustarlo con ENC L/R y persiste en preset.

| Engine | Cutoff default | Resonance default | Rationale |
|---|---|---|---|
| **Moog Model D** | 800 Hz | 35% | Su identidad — warm y oscuro; filtro digital bypaseado (§6.3) |
| Juno-106 | 4 kHz | 15% | Juno es brillante — coloreado suave para calidez analógica |
| Prophet-5 | 3 kHz | 20% | Hereda algo del carácter Curtis CEM; complementa el digital |
| OB-6 | 5 kHz | 10% | OB-6 es abierto — mínima coloración, solo toque analógico |
| ARP 2600 | 2 kHz | 25% | ARP era oscuro — el ladder refuerza ese carácter |
| DX7 | 12 kHz | 0% | FM limpio — casi sin filtrar, solo calor analógico del pass-through |

**Modulación inteligente via ML (Sprint 5B.4):** los modelos Beat Follower, Chord Recognizer
y Key Detector alimentan el CV del filtro analógico:
- Beat Follower BPM → LFO sincronizado al beat → cutoff modulado rítmicamente
- Chord Recognizer (menor/mayor/7th…) → bias de cutoff (menor = más oscuro, −20%)
- Key Detector modo musical → perfil de resonancia (Dorian = suave, Frigio = agresivo)

Esto convierte el filtro de un control estático en un procesador contextual que se adapta
a lo que se está tocando — comportamiento no replicable por software a ningún precio.

**Envelope follower (Sprint 5B.3):** el Teensy lee el RMS de la señal post-filtro (ADC) y
lo usa para modular el cutoff automáticamente. Comportamiento auto-wah disponible en todos
los engines sin configuración adicional.

Teensy controla CD4066 via GPIO 25. LOW = filtro analógico activo, HIGH = bypass.
El estado por engine se persiste en preset.

### 6.2 CV control

Filter cutoff is controlled by CV from Teensy DAC (PWM filtered + opamp buffer):

```
Teensy PWM @ 200kHz ──[LP filter 10kHz]──[TL072 buffer]──▶ Filter CV in
        (0-3.3V)              ↓
                          (0-5V scaled via opamp gain)
```

Resonance is user-controlled via **ENC R** (digital, pin 14/15 Teensy). ENC R turn →
amount de feedback del filtro (0 = sin resonancia, máx = auto-oscilación). ENC R push →
resonance reset a 0. No hay pot físico de resonancia — el único pot en el panel es el
volumen (`01-architecture.md §3.4`). La señal de control sale por PWM/DAC del Teensy al
circuito de feedback del filtro analógico (pendiente de definir en sprint de filter CV).

### 6.3 Interacción filtro analógico ↔ filtro digital en Moog Model D

El filtro analógico 2N3904 aplica **únicamente al Moog Model D** (§6.1). El Moog Model D
tiene también un filtro ladder digital interno (parte del engine en Teensy Audio Library).
Cuando el filtro analógico está activo, el digital se bypasea:

**Problema — dos ladders en serie:**

```
Moog digital (4-pole, 24dB/oct) → Analógico 2N3904 (4-pole, 24dB/oct)
                               = 8 polos equivalente (48dB/oct)
```

El corte de 48dB/oct es tan agresivo que destruye el carácter del engine —
prácticamente silencia todo por encima del cutoff. No es el sonido Moog.

**Solución — bypass digital cuando analógico activo:**

| Estado CD4066 (GPIO 25) | Filtro digital Moog | Filtro analógico 2N3904 |
|---|---|---|
| LOW — analógico activo | **BYPASS** | Activo — el 2N3904 ES el filtro |
| HIGH — bypass analógico | Activo | Bypaseado |

El 2N3904 sustituye, no complementa, al filtro digital del Moog Model D.

**Implementación en firmware (engine_manager.cpp — sprint pendiente):**

```cpp
// Llamar al cambiar engine y al cambiar estado del bypass analógico (GPIO 25)
void sync_moog_digital_filter() {
    // Solo aplica a MoogModelD — otros engines no tienen filtro analógico activo
    if (current_engine != ENGINE_MOOG_MODEL_D) return;

    bool analog_active = (digitalRead(PIN_FILTER_BYPASS) == LOW); // GPIO 25 LOW = activo
    moog_engine.setDigitalFilterEnabled(!analog_active);
    // analog ON  → digital OFF (el 2N3904 toma el rol del filtro)
    // analog OFF → digital ON  (bypass analógico = filtro digital como fallback)
}
```

---

## 7. PCB Layout Guidelines

### 7.1 Filter PCB sub-block

- 2-layer PCB, 30×40mm
- Top layer: signal traces (audio path)
- Bottom layer: ground plane (analog GND)
- Connection to main PCB via 8-pin header (audio in, audio out, CV, +5V analog, -5V analog, GND, bypass control, TPDT state)

### 7.2 Critical layout rules

- **Star ground:** all analog GND traces converge at ONE physical point near SGTL5000
- **Digital/analog separation:** filter PCB ground plane connects to analog GND only
- **Power filtering:** LC filter (10µH + 100µF) between digital 5V and filter +5V
- **Trace length:** signal path minimized (shorter = less noise pickup)
- **Decoupling:** 100nF ceramic + 10µF electrolytic at each opamp Vcc/Vee pin
- **Trimmer access:** mount trimmers on top side with calibration access through enclosure top

---

## 8. Risks & Mitigations

| Risk | Probability | Impact | Mitigation |
|---|---|---|---|
| 2N3904 matching reject rate >20% | Medium | Low | Increase batch from 150 to 200 transistors |
| Calibration time per unit >10 min | Medium | Medium | Automate via Arduino jig + scripts |
| Filter noise floor too high | Low | High | Star ground discipline + power supply LC filter |
| Temperature drift in cutoff | Medium | Low | 2N3904 has reasonable thermal coupling in lab conditions |
| Trimmers drift over time | Low | Low | Use Bourns 3296 multi-turn (high quality) |
| Self-oscillation amplitude too high | Low | Medium | Limit via R_res trim + soft-clip at output buffer |

---

## 9. Future enhancements (v2.0+)

- **24V analog supply:** higher headroom, lower noise (current 5V is compromise for boutique simplicity)
- **Voltage-controlled resonance:** additional CV input for resonance modulation
- **Per-stage stereo:** dual-mono filter for true stereo processing
- **Filter morphing:** continuous morph between LP/BP/HP/Notch via additional mixing
- **Saturation stages:** controlled distortion between ladder stages for tube-like character

---

## 10. References

- **Moog Music patent US3475623** (1969-1971): "Electronic Synthesizer" — Bob Moog's original ladder filter patent (expired 1996)
- **Sound on Sound** "The Moog Ladder Filter" technical article series
- **Will Pirkle**, "Designing Software Synthesizer Plug-Ins in C++" (digital reference for comparison)
- **Hutchins, Bernie**, "Musical Engineer's Handbook" — analog synth design references
- **CircuitSalad** open-source Moog ladder filter design (community-validated reference)

---

## 11. Documentos relacionados

- GFD v3.0 — Master Strategy (parent)
- OpenSpec v0.3 — Technical Spec
- FX Architecture v0.1 — Effects que interactúan con el filter
- Implementation Roadmap — Sprint 1.3 (matching) + Sprint 1.4 (filter protoboard)

---

*End of Filter Design Spec v0.1*
*GrooveForge Brain · Discrete 2N3904 Ladder Filter · Juan Guerrero (GPROG)*

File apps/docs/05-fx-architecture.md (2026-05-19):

# 🎛️ GrooveForge Brain — FX Architecture v0.1 (12 Signature Effects)

> **Canonical spec de la arquitectura de efectos del Brain.**
> **Parent:** GFD v3.0 — Master Strategy & Spec
> **Status:** v0.1 — Mayo 15, 2026
> **Stack:** Teensy 4.1 + Teensy Audio Library + custom DSP

---

## 0. Filosofía

Los efectos del GrooveForge Brain son **diferenciadores reales del producto**. No son los clásicos genéricos ("un reverb más, un delay más"). Cada efecto está diseñado para tener una identidad única que un DJ o productor reconozca y use en performance real.

Esta colección es **probada en vivo por Juan (GPROG) en shows reales** antes del shipping de v1.0. Si un efecto no aporta a un live act, se reemplaza.

## 0.1 Posicionamiento

Un boutique synth a $599 con 12 efectos signature ejecutándose en hardware dedicado (Teensy 4.1 bare-metal, latencia <1ms) es un argumento de venta **único en el mercado**:

- Behringer Pro-1 ($549): synth analog sin FX integrados
- Korg Minilogue XD ($649): solo delay + reverb básicos
- Moog Mavis ($349): sin FX digitales
- Organelle M ($699): FX via Pure Data (latencia variable)
- **GrooveForge Brain ($599): 12 signature FX en hardware dedicado**

## 0.2 Arquitectura FX (3 Layers)

La cadena de FX es **agnóstica a la fuente** — procesa de forma idéntica el audio
generado por un engine de síntesis (Modo Synth) o el audio externo del jack `FX IN`
(Modo FX Processor — ver `01-architecture.md §2.1`). El mismo código DSP corre en
ambos modos; solo cambia de dónde llega la señal al grafo de audio del Teensy.

```
Fuente:  Modo Synth        → Engine output (Moog/Juno/Prophet/etc)
         Modo FX Processor → Audio externo (jack FX IN → SGTL5000 ADC)
        ↓
[INSERT LAYER] — efectos in-line, mono-stereo
        ↓
[SEND LAYER] — aux sends paralelos (parallel mix)
        ↓
[MASTER LAYER] — bus master FX antes de salida
        ↓
SGTL5000 DAC → 1/4" TRS L/R out
```

---

## 1. Los 12 Signature Effects

### 1.1 🌊 CYMATIC RESONATOR (Insert Layer)

**Concepto:** Resonancia armónica basada en patrones cimáticos físicos. Cuatro filtros resonantes paralelos tuneados a las frecuencias de modos vibracionales naturales (modos 1:2:3:5, ratios pseudo-armónicos).

**Sound:** Brillo metalico/cristalino. Como meter el audio a través de un cristal vibrando.

**Use case live:** Build-ups, transiciones drone-to-drop, ambient pads.

**Stack técnico:**
- 4× AudioFilterBiquad (BP resonante, Q=20-60)
- AudioMixer4 (paralelo)
- LFO modulando ratios entre modos
- CPU: ~8%

**Parámetros user:**
- Density (cantidad modos activos 1-4)
- Tune (ratio entre modos)
- Resonance (Q de cada filtro)
- Mix (dry/wet)

---

### 1.2 ☁️ GRANULAR CLOUD (Insert Layer)

**Concepto:** Granulizador con "inteligencia" — analiza el incoming signal y ajusta densidad/pitch/duración de granos según contenido espectral.

**Sound:** De textura sutil shimmer a clouds completamente abstractas.

**Use case live:** Ambient transitions, breakdown atmospheres, vocal chops.

**Stack técnico:**
- AudioEffectGranular (Teensy Audio Library built-in)
- Sample buffer 32KB
- Control inteligente: amplitude envelope → density mapping
- CPU: ~12%

**Parámetros user:**
- Size (grain duration 5-500ms)
- Density (1-50 granos/sec)
- Pitch spread (random pitch variation)
- Position (deterministic vs random)
- Mix

---

### 1.3 👻 GHOST ECHO (Send Layer)

**Concepto:** Delay con AI — aprende el ritmo del usuario (Markov chain orden 2-3) y genera ecos coherentes con el groove en lugar de repeticiones literales.

**Sound:** Ecos que "saben" cuándo entrar. Más musical que un delay clásico.

**Use case live:** Live solos, vocal effects, dub-style call & response.

**Stack técnico:**
- AudioEffectDelay (Teensy built-in, hasta 1.4s)
- 64KB delay buffer
- Markov chain en código (~50KB models bundled)
- TinyML pattern detection trigger
- CPU: ~6%

**Parámetros user:**
- Time (delay base, sincronizado a BPM)
- Feedback (0-95%)
- Ghost amount (0% = classic delay, 100% = full Markov)
- Tape character (saturation + low-pass tail)

---

### 1.4 🌀 SPECTRAL SMEAR (Insert Layer)

**Concepto:** FFT-based frequency morphing. Toma el espectro del audio, lo difumina temporalmente, y lo recompone — "smears" las frecuencias en el tiempo.

**Sound:** Audio que se vuelve neblina espectral. Vocales se convierten en pads, pads se convierten en texturas.

**Use case live:** Drop transitions, vocal pad-ification, ambient washes.

**Stack técnico:**
- AudioAnalyzeFFT1024 (Teensy built-in)
- AudioSynthWaveform multi-osc bank (resíntesis)
- Frequency bin averaging buffer
- CPU: ~15%

**Parámetros user:**
- Smear time (50ms - 2s)
- Resolution (FFT band count 8-64)
- Spectral tilt (low vs high emphasis)
- Freeze (capture spectrum momentáneo)

---

### 1.5 📼 TAPE SATURATE (Master Layer)

**Concepto:** Saturación de cinta modelada con wow/flutter caótico. No es solo overdrive — incluye la modulación natural del transporte de cinta (LFO con drift).

**Sound:** Calidez vintage que envuelve al filter discreto. Color analog auténtico.

**Use case live:** Master bus saturation, vintage character on every patch.

**Stack técnico:**
- AudioEffectWaveshaper (custom curve: tape compression)
- AudioFilterStateVariable (HP/LP rolloff post-saturation)
- LFO drift modulando pitch ±2-15 cents
- CPU: ~5%

**Parámetros user:**
- Drive (0-12dB pre-saturation)
- Wow (LFO depth slow ~0.5Hz)
- Flutter (LFO depth fast ~6Hz)
- Age (rolloff hi-freq + noise floor)

---

### 1.6 ✂️ BIT SCULPT (Insert Layer)

**Concepto:** Bitcrusher inteligente que preserva la percepción de pitch incluso a bit-depths muy bajos. Algoritmo custom dithers strategically.

**Sound:** Lo-fi crujiente pero musical. Como Aphex Twin meets Daft Punk.

**Use case live:** Drops, glitch transitions, breaks digitales.

**Stack técnico:**
- AudioEffectBitcrusher (Teensy built-in) base
- Custom dither algorithm
- Sample rate reduction independiente
- CPU: ~4%

**Parámetros user:**
- Bits (16 → 1 bit)
- Sample rate (48kHz → 1kHz reduction)
- Sculpt (dither character)
- Mix (parallel processing)

---

### 1.7 🔔 MODAL REVERB (Send Layer)

**Concepto:** Reverb basada en modos resonantes de objetos físicos reales — campanas, guadua (bambú colombiano), placas de cristal, madera. Cada "modelo" es un set de filtros resonantes con tiempos de decay calibrados a mediciones reales.

**Sound:** Reverbs con identidad — "reverb de bambú colombiano" no existe en ningún otro producto.

**Use case live:** Signature sound, branding sonoro del Brain.

**Stack técnico:**
- 6-8× AudioFilterBiquad (modes paralelos)
- AudioMixer (densidad)
- Decay envelopes per-mode
- Modelos: Campana, Guadua, Cristal, Madera (futuro: cuero, metal)
- CPU: ~12%

**Parámetros user:**
- Material (campana/guadua/cristal/madera)
- Size (small/medium/large)
- Decay (200ms - 8s)
- Diffusion (modes count active)
- Mix

**Marketing hook único:** "Reverb de guadua colombiana — único en el mundo"

**Implementado en Sprint 2.7** — materiales: campana, guadua, cristal, madera.
CPU medido: 1.2%. Memoria: 5/11 bloques AudioMemory.
Doc: `apps/docs/sprints/12-modal-reverb.md`

---

### 1.8 🌗 PHASE CHORUS (Insert Layer)

**Concepto:** Chorus modelado como BOSS CE-2 vintage pero con LFO drift caótico (no perfectamente sinusoidal). Captura la imperfección del bucket-brigade delay analog.

**Sound:** Movimiento de chorus que respira, no robotic. "Vivo".

**Use case live:** Pads, leads, anything that needs analog "feel".

**Stack técnico:**
- AudioEffectChorus (Teensy built-in)
- AudioSynthWaveformPWM (LFO con drift caótico)
- Saturation pre/post chorus
- CPU: ~5%

**Parámetros user:**
- Rate (0.1-10Hz)
- Depth (0-100%)
- Drift (LFO chaos amount)
- Voices (1-4 chorus voices stacked)

---

### 1.9 🎭 PITCH MOSAIC (Insert Layer) [v1.0 simplified / v1.1 enhanced]

**Concepto:** Pitch shifter polifónico que genera 3 voces armonizadas en escalas seleccionadas. Combina con Layer 1 TinyML scale detection.

**Sound:** Una voz se convierte en chord completo. Polyphonic pitch magic.

**Use case live:** Vocal harmonization, mono synth → polyphonic, instant pads.

**Stack técnico (v1.0 simplified):**
- AudioEffectPitchShift x2 (Teensy built-in, granular based)
- AudioMixer4
- TinyML key detection (Layer 1)
- CPU: ~18% (v1.0), ~25% (v1.1)
- Limitación v1.0: pitch shift quality bueno pero no perfecto

**Parámetros user:**
- Interval 1 (semitones, -24 a +24)
- Interval 2 (semitones)
- Scale lock (chromatic vs scale-aware via TinyML)
- Mix

**v1.1 enhanced (free update Q1 2027):** algoritmo phase-vocoder custom para mejor calidad.

---

### 1.10 🌸 SPRING + PLATE (Master Layer)

**Concepto:** Dual reverb modeled — spring tank vintage (Hammond/Fender style) + plate reverb classic. Routing flexible: serial, parallel, o crossfade entre ambos.

**Sound:** El reverb vintage que todos quieren. Spring para drama, plate para silk.

**Use case live:** Master bus reverb, lead lines, vocal-style sounds.

**Stack técnico:**
- AudioEffectFreeverb x2 (Teensy built-in)
- Custom tuning per algoritmo
- Crossfade matrix
- CPU: ~10%

**Parámetros user:**
- Algorithm (spring / plate / blend)
- Decay (0.5-10s)
- Damping (HF rolloff)
- Pre-delay (0-100ms)
- Mix

---

### 1.11 🎰 GLITCH STUTTER (Insert Layer)

**Concepto:** Buffer stutter con AI pattern detection. No es solo "repetir buffer aleatoriamente" — TinyML detecta beats y crea stutters musicalmente coherentes.

**Sound:** Glitches que suenan intencionales. Hardware-style buffer manipulation.

**Use case live:** Drops, breaks, transitions agresivas, "DJ-style" effects.

**Stack técnico:**
- AudioEffectDelay (32KB buffer)
- Tap automation engine
- TinyML beat detection (Layer 1)
- Stutter patterns: 1/4, 1/8, 1/16, 1/32, random
- CPU: ~7%

**Parámetros user:**
- Pattern (1/4 - 1/32 division)
- Probability (0-100% chance per beat)
- Pitch (stutter pitch shift ±12 semitones)
- Mix

---

### 1.12 ⚡ SUB GENESIS (Master Layer)

**Concepto:** Sub-octave generator con análisis de pitch del input + saturación analógica modelada. Genera una octava sub coherente y la satura.

**Sound:** Bass weight masivo sin EQ surgery. El "thump" que falta.

**Use case live:** Live bass enhancement, sub-bass synthesis, dub style.

**Stack técnico:**
- AudioFilterStateVariable (LP @ 200Hz para pitch tracking)
- Pitch tracking algorithm
- AudioSynthWaveform (sub-octave generator)
- AudioEffectWaveshaper (saturation)
- CPU: ~4%

**Parámetros user:**
- Sub level (0-12dB)
- Octaves (1 down, 2 down)
- Drive (sub saturation)
- Cutoff (LP filter del sub)
- Mix

---

## 2. CPU Budget Analysis

| Layer | Efectos simultáneos típicos | CPU |
|---|---|---|
| Insert (1 activo) | Granular Cloud | ~12% |
| Send (2 activos) | Ghost Echo + Modal Reverb | ~18% |
| Master (2 activos) | Tape Saturate + Spring/Plate | ~15% |
| **Total worst case** | 5 FX + engine + filter analog control | **~45% Teensy 4.1** |

**Headroom restante:** ~55% para engine polyphony + TinyML inference + UI processing.

**Conclusión:** Todos los 12 efectos son viables. El usuario puede combinar hasta 5 FX simultáneamente sin xruns.

## 3. Mapeo de Efectos por Modo

### Modo Standalone
- 1 Insert + 1 Send + 1 Master simultáneo (preset-based selection)
- Encoders 1+2 controlan parámetros del FX activo
- BTN5 toggle FX on/off (legacy del GFD v1.0)

### Modo Live Act (Live Performance Mode)
- Hasta 5 FX simultáneos (1 Insert + 2 Send + 2 Master)
- Mapping a botones para hands-on control
- FX chains guardables como performances

### Modo Surface (con GroovePilot VST3)
- VST3 puede automatizar parámetros FX via Bridge Protocol
- AI cloud sugiere combinaciones de FX según contexto
- Mix-aware: el Brain recibe instrucciones del DAW

## 4. Roadmap

### v1.0 ship (Q3 2027)
- [x] Tape Saturate — Sprint 2.3 ✅ CPU 3%
- [x] Phase Chorus — Sprint 2.4 ✅ CPU 1.1%
- [x] Bit Sculpt — Sprint 2.5 ✅ CPU 0.6%
- [x] Sub Genesis — Sprint 2.6 ✅ CPU 0.8%
- [x] Modal Reverb (campana + guadua + cristal + madera) — Sprint 2.7 ✅ CPU 1.2%
- [ ] Cymatic Resonator — Sprint 2.8
- [ ] Granular Cloud — Sprint 2.9
- [ ] Spring + Plate — Sprint 2.10
- [ ] Ghost Echo (v1.0 sin Markov, v2.0 con TinyML) — Sprint 2.11

### v1.1 free update (Q1 2027)
- [ ] Spectral Smear
- [ ] Glitch Stutter (requiere TinyML beat detection — Sprint 4.5+)
- [ ] Pitch Mosaic simplified (requiere TinyML key detection — Sprint 4.3+)

### v1.2 free update (Q2 2027)
- [ ] Pitch Mosaic enhanced (phase-vocoder custom)
- [ ] Ghost Echo v2.0 — Markov chain rhythm prediction (requiere TinyML beat detection — Sprint 4.5+)
- [ ] FX chains community sharing (cloud Layer 2)

## 5. Live Testing Protocol (Juan/GPROG)

Cada efecto debe ser probado en al menos 2 contextos antes de pasar el QA:

1. **Studio test** — A/B contra efectos comerciales similares (DJ environment)
2. **Live show test** — Probado en gig real con audiencia, evaluar feel
3. **Future live act test** — Cuando esté listo para live act como GPROG

Feedback loop:
- ¿Suena diferenciado vs el equivalente comercial?
- ¿Aporta a la performance o es solo academic?
- ¿La latencia es imperceptible en context live?
- ¿Los parámetros son intuitivos en pánico de show?

Si cualquier efecto no pasa este filtro, se rediseña o reemplaza antes del v1.0 ship.

## 6. Marketing Hooks por Efecto

| Efecto | Hook de marketing |
|---|---|
| Cymatic Resonator | "Cristal vibrando dentro de tu mix" |
| Granular Cloud | "Donde las texturas viven" |
| Ghost Echo | "El delay que sabe a dónde va" |
| Spectral Smear | "Frecuencias que se difuminan en el tiempo" |
| Tape Saturate | "Calidez de cinta de los 70s" |
| Bit Sculpt | "Lo-fi inteligente, no random" |
| **Modal Reverb (guadua)** | **"Reverb de guadua colombiana — único en el mundo"** |
| Phase Chorus | "Chorus que respira como el CE-2" |
| Pitch Mosaic | "Una voz, tres armonías, escala automática" |
| Spring + Plate | "El reverb vintage que querés" |
| Glitch Stutter | "Glitches que suenan intencionales" |
| Sub Genesis | "Sub-bass weight, sin EQ surgery" |

## 7. Documentos relacionados

- GFD v3.0 — Master Strategy (parent)
- OpenSpec v0.3 — Technical Spec
- AI Architecture v0.1 — TinyML que power Ghost Echo + Glitch Stutter + Pitch Mosaic
- Filter Design Spec v0.1 — Discrete 2N3904 ladder filter (complementa todos los FX)

---

*End of FX Architecture v0.1*
*GrooveForge Brain · 12 Signature Effects · Juan Guerrero (GPROG)*

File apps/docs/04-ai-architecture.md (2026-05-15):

# 🧠 GrooveForge Brain — AI Architecture v0.1 (3-Layer Spec)

> **Canonical spec de la arquitectura AI del Brain.**
> **Parent:** GFD v3.0 — Master Strategy & Spec
> **Sibling:** OpenSpec v0.3
> **Status:** v0.1 — Mayo 15, 2026

---

## 0. Resumen ejecutivo

El GrooveForge Brain implementa una **arquitectura de superpoderes incrementales**: el instrumento standalone ya es completo a $599, y cada capa adicional (teclado MIDI, slaves, WiFi, DAW) le agrega capacidades de AI. El AI no es un feature monolítico — es una serie de "poderes" que se desbloquean según el ecosistema conectado.

Esta es la promesa de marketing Y la arquitectura técnica simultáneamente.

## 0.1 La arquitectura modular: superpoderes incrementales

```
NIVEL 0 — STANDALONE (out of the box)
├── 6 emuladores clásicos (Moog/Juno/Prophet/OB-6/DX7/ARP)
├── Discrete 2N3904 ladder filter analog
├── Procesador de efectos (12 signature FX)
└── Encoders + buttons + display
   → Synth boutique completo a $599

NIVEL 1 — + TECLADO MIDI (USB-A host)
├── + Scale Lock (TinyML)
├── + Chord Recognition (TinyML)
├── + Auto-Harmonization (TinyML)
├── + Beat Follower (TinyML)
└── + Genre Fingerprint (TinyML)
   → Synth inteligente que entiende lo que tocás

NIVEL 2 — + SLAVES via pogo (futuro v1.x)
├── + E-Drum: percusión inteligente con velocity ML
├── + Marimba electrónica: mallets aware
├── + Air-Bamboo: gesture controller con IMU
└── + Brain conoce contexto de todos
   → Ecosistema instrumental modular inteligente

NIVEL 3 — + WIFI (ESP32-S3 cloud)
├── + Patch search natural language
├── + Progression suggester
├── + Style transfer
└── + Community patches
   → AI cloud-augmented

NIVEL 4 — + DAW (GroovePilot VST3 via USB-C)
├── + Mix-aware sound
├── + Frequency conflict detection
├── + Layer suggestions
└── + Smart macros bidireccionales
   → AI co-pilot completo para producción musical
```

Cada nivel es **independiente y opcional**. El usuario compra el Brain como Nivel 0 (synth boutique completo) y le da "poderes" agregando hardware o conectándolo al ecosistema GroovePilot.

## 0.2 Marketing narrative

> **Standalone:** un synth boutique con seis arquitecturas clásicas y un filtro analógico discreto real, por $599.
>
> **Conectá un teclado MIDI** → el Brain detecta lo que tocás y se vuelve un asistente musical inteligente en tiempo real.
>
> **Conectá los slaves GrooveForge** (E-Drum, Marimba, Air-Bamboo) → toda la familia de instrumentos comparte un cerebro inteligente.
>
> **Conectálo al WiFi** → acceso a la inteligencia de GroovePilot cloud: búsqueda de presets por descripción, sugerencias de progresiones, style transfer.
>
> **Conectálo al DAW** → GroovePilot VST3 lo convierte en el co-pilot definitivo para tu producción musical.
>
> Una pieza de hardware. Cinco niveles de superpoderes. Tú decidís hasta dónde llegar.

## 0.3 Mapeo de capacidades AI a capas técnicas

Los "poderes" se distribuyen entre **tres capas técnicas** de AI, cada una con propósito, latencia y stack distintos:

```
LAYER 3 (DAW Bridge) — GroovePilot VST3 en Ableton
    ↑↓ USB-C composite (Audio + MIDI + CDC)
LAYER 2 (Cloud AI) — GroovePilot cloud API
    ↑↓ WiFi 802.11 b/g/n (ESP32-S3)
LAYER 1 (TinyML on-device) — Teensy 4.1 + TFLite Micro
```

---

## 1. LAYER 1 — TinyML on-device (Teensy 4.1)

### 1.1 Stack técnico

- **Runtime:** TensorFlow Lite Micro 2.14+
- **Acelerador:** CMSIS-NN (ARM optimized DSP)
- **MCU:** Teensy 4.1 (Cortex-M7 @ 600MHz, 1MB RAM, 8MB flash)
- **Lenguaje:** C++ con PlatformIO
- **Modelos:** TFLite quantized int8 o int16

### 1.2 Capacidad disponible

De los 1MB de RAM del Teensy 4.1:
- ~400KB para Teensy Audio Library + engines
- ~200KB para state + UI buffer
- ~200KB para TinyML tensor arena
- ~200KB margen seguridad

De los 8MB de flash:
- ~2MB para firmware base + Audio Library
- ~1MB para presets factory + genre profiles
- ~500KB para modelos TFLite bundled
- ~4.5MB margen / futuro growth

### 1.3 Features Layer 1 (instantáneas, sin internet)

| Feature | Tamaño modelo | Inference | UX |
|---|---|---|---|
| **Scale Lock** | 12KB | 4ms | Detecta key, snap notas a escala elegida |
| **Chord Recognition** | 45KB | 8ms | Mano izq → nombre acorde en display |
| **Auto-Harmonization** | 80KB | 12ms | Genera segunda voz armónica en tiempo real |
| **Beat Follower** | 30KB | 6ms | Tempo detection desde lo que tocás |
| **Genre Fingerprint** | 100KB | 18ms | Sugiere genre profile matching tu estilo |
| **Velocity Curve Learn** | 8KB | 3ms | Adapta curva velocity a tu fuerza de toque |
| **TOTAL** | **~275KB** | | Cabe en 8MB flash sin problema |

### 1.4 Cuándo se ejecuta cada modelo

- **Scale Lock:** trigger por usuario (button "Lock Scale")
- **Chord Recognition:** continuamente cuando hay 3+ notas simultáneas
- **Auto-Harmonization:** trigger por usuario (button "Harmonize")
- **Beat Follower:** continuamente background, actualiza tempo cada 4 bars
- **Genre Fingerprint:** cada 30 segundos en background
- **Velocity Curve Learn:** primer minuto de uso, calibra al usuario

### 1.5 Pipeline de entrenamiento

1. Datasets públicos: Lakh MIDI Dataset, Million Song Subset, Maestro
2. Training en Google Colab / local con TensorFlow
3. Quantization int8 con TFLite converter
4. Validation: latencia + accuracy + memory footprint
5. Bundle en firmware como C arrays via xxd

---

## 2. LAYER 2 — Cloud AI (via ESP32-S3 WiFi)

### 2.1 Stack técnico

- **Cliente:** ESP32-S3 con HTTPS + WebSocket
- **API:** GroovePilot cloud REST + WebSocket (compartido con VST3)
- **Auth:** API key bundle device + signed challenge
- **Backend:** Python FastAPI + Anthropic Claude API (o models propios)
- **Latencia:** async, 200-1000ms aceptable

### 2.2 Features Layer 2

| Feature | Endpoint | Trigger | Output |
|---|---|---|---|
| **Patch Search NL** | POST /search/patches | Encoder + text input | 5 presets matching descripción |
| **Progression Suggester** | POST /suggest/progression | Tap action button | 4-8 bar chord progression |
| **Style Transfer** | POST /transfer/style | Encoder + select style | Modified preset/MIDI sequence |
| **Community Patches** | GET /community/trending | Background sync | New patches por género |
| **Genre Profile Update** | GET /profiles/{id} | Background daily | Updated genre profile JSON |
| **OTA Firmware** | GET /firmware/check | Background weekly | Update available notification |

### 2.3 Privacy & data

- **Audio NUNCA sale del Brain.** Solo metadata: tempo, key, chord progression, genre tags
- User puede toggle Cloud Features ON/OFF
- Anonymous usage stats opcional (opt-in)
- Patches que el usuario comparte: explicit consent

### 2.4 Offline degradation

Sin WiFi:
- Layer 1 sigue 100% funcional
- Layer 2 features muestran "Offline" en display
- Cached patches y profiles siguen disponibles
- Cuando vuelve WiFi: sync automático

---

## 3. LAYER 3 — DAW Bridge (GroovePilot VST3)

### 3.1 Stack técnico

- **Conexión:** USB-C composite device (Audio + MIDI + CDC Serial)
- **Protocolo:** Bridge Protocol v0.1 sobre USB-CDC
- **VST3 host:** Ableton Live 11+ (otros DAWs en v2.0)
- **Bridge process:** GroovePilot VST3 plugin (JUCE C++)

### 3.2 Features Layer 3

| Feature | Direction | UX |
|---|---|---|
| **Mix-Aware Sound** | DAW → Brain | Brain ajusta filter/level según mix completo |
| **Frequency Conflict** | DAW → Brain | Display rojo cuando hay choque frecuencia |
| **Layer Suggestions** | DAW → Brain | "Add sub bass" → action button carga preset |
| **Smart Macros** | DAW ↔ Brain | Encoders rebindean según contexto DAW |
| **DAW Sync** | DAW → Brain | Tempo, key, bars, beats sincronizados |
| **Send Audio to GP** | Brain → DAW | USB Audio out del Brain analizable por GP |
| **Receive Suggestions** | DAW → Brain | Mix score, suggestions ranking |

### 3.3 Modos de operación

- **Standalone:** No DAW. Solo Layer 1 + 2 activos.
- **Surface mode:** Brain conectado, synth engines silenciados, controles → macros AI.
- **Hybrid mode:** Brain conectado, synth engines + AI macros simultáneos.

---

## 4. Flow completo: MIDI keyboard como input

```
[Teclado MIDI externo (USB)]
        ↓ USB-A host
[Teensy 4.1] ──────────────┐
        ↓                  │
   ┌────┴────┐              │
   ↓       ↓              ↓
[Synth] [Layer 1   ]    [USB-C out]
[engines][TinyML AI]    [MIDI + Audio]
   ↓       ↓              ↓
[Audio  [Display]      [GroovePilot VST3]
 out]   [chord, key,    ↓
         scale, beat,  [Layer 3 AI]
         suggestions]   ↓
   ↓                  [DAW: mix-aware,
[1/4" jacks            suggestions, etc.]
 L/R out]

         [ESP32-S3 WiFi]← trigger por usuario
            ↓
         [Layer 2 cloud AI]
            ↓
         [Patches, progressions, style]
```

---

## 5. Justificación del precio $599

### 5.1 Comparativa de mercado

| Producto | Precio | Filter analóg | AI | Polifonía | Comunicación |
|---|---|---|---|---|---|
| Moog Mavis | $349 | ✅ ladder | ❌ | Mono | CV |
| Korg NTS-1 | $99 | ❌ digital | ❌ | Mono | MIDI USB |
| Arturia MicroFreak | $349 | ✅ SP | ❌ | 4 voces | MIDI USB |
| Behringer Pro-1 | $549 | ✅ Curtis | ❌ | Mono | MIDI USB |
| Korg Minilogue XD | $649 | ✅ | ❌ | 4 voces | MIDI USB |
| Organelle M | $699 | ❌ digital | ❌ | Variable | USB+WiFi |
| Modal Argon8 | $799 | ❌ digital | ❌ | 8 voces | MIDI USB |
| **GrooveForge Brain** | **$599** | **✅ 2N3904 ladder** | **✅ 3-layer** | **6-8 voces** | **USB-C + WiFi + BT + USB-A host** |
| Push 3 Standalone | $999 | ❌ | ❌ | 8 voces | Standalone Linux |

### 5.2 Único en el mercado

Ningún competidor combina:
- AI nativo integrado (no add-on)
- Discrete transistor ladder authentic (Moog 1970)
- 6 arquitecturas clásicas en un instrumento
- TinyML on-device para features instantáneas sin internet
- Connectivity completa (USB-C + WiFi + BT + USB-A host)
- Build quality boutique (guadua + aluminum)

### 5.3 El AI es el diferenciador del precio

Sin AI, el Brain sería un boutique synth más en el mercado de $549. Con AI 3-layer:
- Layer 1 (TinyML): features instantáneas que ningún synth tiene
- Layer 2 (Cloud): expansibilidad continua via WiFi
- Layer 3 (DAW): integración profunda con producción musical

Esto justifica los $50-100 USD adicionales sobre competidores boutique sin AI.

---

## 6. Roadmap AI

### v1.0 ship features
- [ ] Layer 1: Scale Lock + Chord Recognition + Beat Follower
- [ ] Layer 2: Patch Search NL + Genre Profile Update
- [ ] Layer 3: Mix-Aware Sound + Basic Macros

### v1.1 (Q1 2027) free update
- [ ] Layer 1: Auto-Harmonization
- [ ] Layer 2: Progression Suggester
- [ ] Layer 3: Frequency Conflict Detection

### v1.2 (Q2 2027) free update
- [ ] Layer 1: Genre Fingerprint + Velocity Curve Learn
- [ ] Layer 2: Style Transfer + Community Patches
- [ ] Layer 3: Layer Suggestions + Smart Macros

### v2.0 (2028+) possibilities
- [ ] Layer 1: small Generative model on-device
- [ ] Layer 2: voice control ("hey brain, make this warmer")
- [ ] Layer 3: Multi-DAW support (Logic, FL Studio, Bitwig)

---

## 7. Riesgos

| Riesgo | Mitigación |
|---|---|
| TFLite Micro performance insuficiente | CMSIS-NN aceleración + quantización agresiva |
| Modelos no caben en 8MB flash | Streaming desde SD card opcional |
| Cloud API costos altos por user | Free tier limitado + paid GP Pro acceso ilimitado |
| Privacy concerns con cloud | Audio NUNCA sale del Brain, solo metadata |
| Latencia WiFi excesiva | Async UX + Layer 1 fallback siempre disponible |

---

## 8. Métricas a trackear

- TinyML inference time (target <20ms p99)
- TinyML memory footprint (target <400KB total)
- Cloud API latency (target <800ms p95)
- Feature usage analytics (anonymous, opt-in)
- Accuracy métricas por modelo (target >85%)

---

## 9. Documentos relacionados

- GFD v3.0 — Master Strategy & Spec (parent)
- OpenSpec v0.3 — Technical Spec
- Bridge Protocol v0.1 — Communication Spec
- Filter Design Spec v0.1 — Analog Filter Spec
- FX Architecture v0.1 — 12 Signature Effects

---

*End of AI Architecture v0.1*
*GrooveForge Brain · 3-Layer AI Spec · Juan Guerrero (GPROG)*

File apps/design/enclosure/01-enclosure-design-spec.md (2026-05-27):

# GrooveForge Brain — Enclosure Design Spec v0.3

> **Autor:** Juan Guerrero (GPROG) / Industrial Design Agent
> **Versión:** 0.4 — USB consolidado (2× USB-C), elimina USB-A y USB-C Power separado
> **Fecha:** 2026-05-26
> **Status del documento:** vivo — secciones marcadas DEFINIDO / PROPUESTO / PENDIENTE
> **Derivado de:** `apps/docs/01-architecture.md` v0.3 + `apps/docs/00-master-strategy.md` §8.2

---

## 0. Por qué este documento existe

El enclosure no es packaging. Es el primer punto de contacto del usuario con el instrumento y define si el Brain se percibe como un producto boutique de $599 o como un hobby kit caro.

Este spec precede cualquier archivo CAD. Todo lo que no esté especificado aquí no se modela.

### Decisiones de versión que impactan todo el diseño

| Decisión | v0.1/v0.2 spec | v0.3 — DEFINITIVO |
|---|---|---|
| Batería | LiPo 3000mAh integrada | **Sin batería — USB-C only** (Batería = versión Pro futura) |
| ESP32-S3 | Módulo plano sobre PCB | **Módulo elevado sobre display** (cero footprint PCB adicional) |
| ENC NAV position | A la derecha del display | **Debajo del display** |
| Botones | 4× Kailh Choc V2 fila inferior | **4× Kailh Choc V2 retroiluminados, fila superior** |
| Filter bypass switch | En panel | **Eliminado** |
| Volumen | Pot 16mm | **Alps RK097N (9mm body) — mantenido** |

**Por qué mantener el VOL:** en performance en vivo el volumen se ajusta por músculo, sin mirar. Un encoder requiere contexto de menú. El RK097N ocupa 9mm de body — el costo en footprint es mínimo vs el beneficio ergonómico.

**Por qué diferir la batería:** la celda LiPo (65×45×8mm) consumía el 33% del área PCB disponible. Sin ella, el device de 180×100mm se vuelve factible con Teensy 4.1 dev board. La versión Pro (con batería) puede usar el mismo enclosure con la celda bajo la PCB en un compartimento dedicado — sin rediseñar el exterior.

---

## 1. Dimensiones Generales v0.3

**Status: PROPUESTO — target para prototipo v0.2 y producción v1.0**

### Device dimensions

```
PETG body central:  180mm × 100mm × 42mm frontal / 30mm trasero
Guadua cheeks:      +12mm cada lado (izq y der)
Total instrumento:  204mm × 100mm × 42mm frontal / 30mm trasero
```

El perfil más flat (42mm vs 52mm de v0.2) es posible porque sin LiPo el componente más alto es el Teensy 4.1 + conector (aprox 8mm sobre PCB) más el standoff (5mm) más la PCB (1.6mm) = ~15mm. Con paredes PETG de 3mm, la altura mínima es ~21mm. El target de 42mm frontal da 21mm de margen — suficiente para el routing interno y la inclinación ergonómica.

### Comparación con referencias

| Instrumento | Ancho | Prof. | Alto | Peso |
|---|---|---|---|---|
| OP-1 original | 230mm | 101mm | 28mm | 1kg |
| OP-1 Field | 228mm | 104mm | 37mm | 1.1kg |
| **GrooveForge Brain v0.3** | **204mm** | **100mm** | **42mm** | **~400g est.** |
| OP-Z | 228mm | 57mm | 10mm | 280g |

El Brain v0.3 tiene el mismo orden de magnitud del OP-1: portátil, sobre escritorio, cabe en mochila.

### Anatomía del enclosure

```
VISTA FRONTAL

│← 12mm →│←————— 180mm (PETG body) ——————→│← 12mm →│
         ┌──────────────────────────────────┐
         │   TOP PANEL ALUMINIO 2mm         │
┌────────┤  [B1][B2][B3][B4]               ├────────┐
│        │  ENC1  [DISPLAY] ENC2            │        │
│ GUADUA │       [ENC NAV]                 │ GUADUA │
│ LEFT   │       [VOL]                     │ RIGHT  │
│ INPUTS │  PETG body (anthracite)         │OUTPUTS │
└────────┴──────────────────────────────────┴────────┘
│← —————————————— 204mm total ——————————————————————→│

Altura frontal: 42mm
Altura trasera: 30mm  (tilt ~7° — más suave que v0.2)
```

### Relación PCB → enclosure

| Dimensión | Internal (PETG body 180mm, paredes 3mm×2) | PCB target |
|---|---|---|
| Ancho (X) | 174mm usable | 168mm PCB (3mm clearance c/lado) |
| Profundidad (Y) | 94mm usable | 88mm PCB (3mm clearance c/lado) |

Con 168×88mm de PCB, la distribución de componentes es cómoda incluso con Teensy 4.1 dev board (61×18mm).

---

## 2. Estrategia de Materiales v0.3

**Status: DEFINIDO**

### Presupuesto (inmutable del BOM)

| Material | Budget BOM | Uso |
|---|---|---|
| PETG cuerpo | $5.00 | Shell central + base |
| Aluminio CNC top panel | $6.00 | Panel superior 2mm anodizado |
| Guadua laminada | $2.50 | Paneles cheek laterales (2×) |
| **Total enclosure** | **$13.50** | Tope no negociable |

### Superficie por material

#### PETG — Cuerpo central 180×100mm

Shell estructural. Paredes laterales = backing de los cheeks de guadua (con rebaje de 12mm para encastre). Panel trasero = solo pogo connector. Base = flat, con patas de goma antideslizante en 4 esquinas.

Color: near-black anthracite, textura FDM visible en laterales y trasero.

#### Aluminio — Top panel 180×100mm

Cubre el cuerpo PETG central. Todos los controles pasan por este panel. Anodizado anthracite clase 2, laser engraving para labels. **No se extiende sobre los cheeks de guadua** — la junta aluminio/guadua en los 4 bordes del panel es un detalle de diseño explícito.

#### Guadua — Cheeks laterales 12mm × 100mm × altura

Guadua angustifolia laminada. Sellado epoxy obligatorio (humedad Bogotá 70-80% HR). Acabado satinado. Cutouts de puertos realizados post-ensamblaje, guiados por los cutouts del PETG para alineación perfecta.

Ver detalles de fabricación en §9.

---

## 3. Layout del Panel Frontal (Top) v0.3

**Status: PROPUESTO — basado en referencia visual aprobada**

### Sistema de coordenadas

Origen (0,0) = esquina inferior izquierda del top panel, visto desde arriba.
X crece hacia la derecha. Y crece hacia atrás (alejándose del usuario).
Top panel: 180mm × 100mm, esquinas R3mm.

### Filosofía de layout v0.3

```
ZONA SUPERIOR — fila de botones retroiluminados
ZONA MEDIA    — ENC1 / DISPLAY+ESP32 elevado / ENC2
ZONA INFERIOR — ENC NAV (con LED ring) centrado bajo el display
ZONA ACCENT   — VOL pot discreto, esquina inferior
```

La lógica de lectura es vertical: el ojo baja desde los botones de contexto (qué modo estoy), pasa por el display (qué está pasando), llega al encoder de acción (ENC NAV — ASK AI / navegar). Los encoders de parámetro (ENC1 izq, ENC2 der) son acción lateral — la mano llega sin mirar.

### Tabla de posiciones (centro del componente)

| Componente | X (mm) | Y (mm) | Notas |
|---|---|---|---|
| B1 — ENGINE | 30 | 82 | Kailh Choc V2 retroiluminado |
| B2 — FX | 58 | 82 | Kailh Choc V2 retroiluminado |
| B3 — AI / SCALE | 122 | 82 | Kailh Choc V2 retroiluminado |
| B4 — PRESET | 150 | 82 | Kailh Choc V2 retroiluminado |
| ENC1 — CUTOFF (eje) | 22 | 55 | ALPS EC11, knob Ø18mm |
| Display GC9A01 (centro) | 90 | 57 | Ø35mm cutout, módulo ESP32 elevado |
| ENC2 — RESONANCE (eje) | 158 | 55 | ALPS EC11, knob Ø18mm |
| ENC NAV — ACTION (eje) | 90 | 30 | ALPS EC11 con 16-LED ring, knob Ø22mm |
| VOL pot (eje) | 22 | 14 | Alpha RV09 (9mm), knob Ø12mm discreto |

**Nota ENC NAV:** centrado bajo el display. El LED ring (Ø38mm exterior) necesita 19mm de radio libre desde el centro del encoder. Distancia ENC NAV — borde display: 57 - 30 = 27mm entre centros. Con display Ø35mm (radio 17.5mm) y ring radio externo 19mm, el gap borde display → borde ring exterior es 27 - 17.5 - 19 = -9.5mm. **Interferencia — corregir:** mover ENC NAV a Y=22 y display a Y=60, o reducir el ring a Ø32mm exterior. Ver D-08 en §14.

**Nota botones B1/B2 vs B3/B4:** los botones están partidos en dos grupos de 2, con el display entre medias — igual que la imagen de referencia. El gap visual entre B2 y B3 (X=58 a X=122, gap de 64mm) coincide con el ancho del display+encoders. Esto es intencional: los botones de contexto (ENGINE, FX) van a la izquierda del display; los botones de acción (AI, PRESET) a la derecha.

### Sketch ASCII dimensional (vista top)

```
180mm
|←————————————————————————————————————————→|

┌──────────────────────────────────────────┐
│  [B1]  [B2]              [B3]  [B4]     │  Y=82
│                                          │
│  ◎         .────.              ◎        │  Y=57/55
│  ENC1     ( GC9A )            ENC2      │
│ CUTOFF     `────'           RESONANCE   │
│           [ESP32↑]                      │
│              ○○                         │
│           ◎○    ○                       │  Y=30
│           ○  ENCNAV  ○  ← LED ring     │
│              ○○                         │
│  ◎                                      │  Y=14
│  VOL                                    │
└──────────────────────────────────────────┘
  ↑                          ↑
  X=22                       X=158
```

### Verificación de clearances críticos

**ENC1 ↔ borde panel izquierdo:** X=22 - knob_radius(9) = 13mm desde el borde. Con borde redondeado R3mm del aluminio, el knob queda 10mm del borde visual — ajustado pero funcional.

**B1 (X=30) ↔ ENC1 (X=22) vertical:** botones en Y=82, ENC1 en Y=55 → separación vertical 27mm. Con keycap Kailh de 11×11mm y knob ENC1 de Ø18mm, el clearance es >10mm. OK.

**ENC NAV ↔ VOL:** ENC NAV en (90,30), VOL en (22,14). Distancia = √(68²+16²) = 70mm. Sin interferencia.

**B1-B2 gap vs B3-B4 gap:** B2 en X=58, B3 en X=122 → gap de 64mm entre grupos. Display de 35mm + 2×(ENC shaft X=90-58=32mm de margen). Los knobs de ENC1/ENC2 no interfieren con los keycaps de los botones porque están en diferente fila (Y=55 vs Y=82).

---

## 4. Panel Lateral Izquierdo (Guadua Cheek LEFT — AUDIO IN)

**Status: PROPUESTO v0.3 — sin cambios vs v0.2**

Side panel izquierdo = entradas de audio. Sin MIDI DIN en BOM actual.

### Vista del cheek LEFT (exterior → interior)

```
←———————————————— 100mm (profundidad) ————————————————→
     FONDO (Y=0)                     FRENTE (Y=100)

┌──────────────────────────────────────────────────────┐ ─
│            ○                ○              ○         │ │
│       [1/4" TRS]      [1/4" TRS]      [3.5mm]       │ │ 42mm
│         IN L            IN R          HEAD IN        │ │
└──────────────────────────────────────────────────────┘ ─
              ↑                ↑              ↑
             Y=30             Y=55           Y=78
```

| Puerto | Y desde fondo | Z centro | Componente |
|---|---|---|---|
| 1/4" TRS IN L | 30mm | 21mm | Jack Neutrik NYS229 o equiv. |
| 1/4" TRS IN R | 55mm | 21mm | Jack Neutrik NYS229 o equiv. |
| 3.5mm AUX/Headphone IN | 78mm | 21mm | Jack 3.5mm stereo PCB-mount |

---

## 5. Panel Lateral Derecho (Guadua Cheek RIGHT — AUDIO OUT + USB)

**Status: DEFINIDO v0.4 — 4 puertos, todo USB-C, D-10 resuelto**

Side panel derecho = salidas de audio + conexiones digitales.

### Decisión USB v0.4 (origen: revisión de arquitectura)

| Decision | v0.3 | v0.4 DEFINITIVO | Razon |
|---|---|---|---|
| USB Power | USB-C Power separado | **Consolidado en USB-C Teensy** | Teensy USB provee 5V cuando conectado; power bank funciona igual |
| USB Teensy | Puerto propio USB-C | **USB-C unico (Power + Audio + MIDI)** | Un solo cable al PC para todo |
| USB Host | USB-A female | **USB-C Host** | Estetica todo USB-C; adaptador USB-C→USB-A para teclados legacy |
| Total puertos | 5 | **4** | Elimina D-10, clearances holgados, BOM mas barato |

**Implementacion en prototipo v0.2 (Teensy dev board):**
El Teensy 4.1 dev board tiene micro-USB nativo. Se usa un **pigtail interno micro-USB→USB-C**
(cable corto < 15cm, panel-mount USB-C female) para exponer el puerto como USB-C en el panel.
Solución estandar en mundo DIY synth (Mutable Instruments, Befaco).

**Implementacion en v1.0 (PCB custom):**
iMXRT1062 bare con USB-C nativo — no requiere adaptador. Mismo conector panel, mismo cutout.

### Vista del cheek RIGHT (exterior → interior)

```
←———————————————— 100mm (profundidad) ————————————————→
     FONDO (Y=0)                     FRENTE (Y=100)

┌──────────────────────────────────────────────────────┐ ─
│    ⬛                ○           ○             ⬛     │ │
│ [USB-C           [1/4" TRS]  [1/4" TRS]   [USB-C    │ │ 42mm
│  Power+Data]       OUT L       OUT R       HOST]     │ │
└──────────────────────────────────────────────────────┘ ─
      ↑                  ↑           ↑             ↑
     Z=15               Z=38        Z=60          Z=82
```

| Puerto | Z desde fondo | Y centro | Componente | Notas |
|---|---|---|---|---|
| USB-C (Power + Audio/MIDI) | 15mm | 21mm | USB-C female panel-mount | Pigtail interno micro-USB→USB-C en v0.2 |
| 1/4" TRS OUT L | 38mm | 21mm | Jack Neutrik NYS229 o equiv. | |
| 1/4" TRS OUT R | 60mm | 21mm | Jack Neutrik NYS229 o equiv. | |
| USB-C Host | 82mm | 21mm | USB-C female panel-mount | Teensy USB Host pins; adaptador para teclados USB-A |

**Clearances verificados (4 puertos):**
- USB-C (Z=15, span Z=9.75→20.25) → TRS L (Z=38, span 32.75→43.25): gap 12.5mm OK
- TRS L → TRS R (Z=60, span 54.75→65.25): gap 11.5mm OK
- TRS R → USB-C Host (Z=82, span 76.75→87.25): gap 11.5mm OK
- USB-C Host → borde frontal (Z=100): clearance **12.75mm** — D-10 RESUELTO

---

## 6. Panel Trasero (PETG)

**Status: PROPUESTO v0.3**

Simplificado: solo pogo connector de expansión modular. Sin otros puertos.

| Componente | X centro | Z centro | Notas |
|---|---|---|---|
| Pogo 6-pin expansion | 90mm (centro) | 15mm | Würth WR-WST o equiv. |

---

## 7. Componentes del Panel — Especificaciones

**Status: DEFINIDO / PROPUESTO por componente**

### Encoders — ALPS EC11

Los tres encoders usan el mismo footprint ALPS EC11. El knob diferencia su función visualmente.

| Encoder | Knob Ø | Knob estilo | Función |
|---|---|---|---|
| ENC1 (CUTOFF) | 18mm | Knurled, bajo perfil | Cutoff / param navigation |
| ENC2 (RESONANCE) | 18mm | Knurled, bajo perfil | Resonance / value |
| ENC NAV (ACTION) | 22mm | Liso, perfil alto | Navigate / ASK AI / confirm |

El ENC NAV más grande y alto lo hace físicamente distinguible sin mirar — el músico lo encuentra por tacto.

### LED Ring — ENC NAV

16× WS2812B-2020 (2×2mm) montados en una PCB anular. La PCB del ring se monta concéntrica al encoder con espacio para el eje. Las dimensiones del ring deben resolverse contra el clearance del display (ver D-08).

### Botones — Kailh Choc V2 Brown (retroiluminados)

| Spec | Valor |
|---|---|
| Tipo | Tactile low-profile, PCB mount |
| Travel | 3.0mm |
| Actuation | 45gf |
| LED | RGB SMD en posición de backlight (Choc V2 compatible) |
| Keycap | PBT translúcido, 1U (18.6×17.6mm), serigrafía laser |
| Pitch en panel | 28mm centro a centro (B1↔B2 y B3↔B4) |
| Color LED | Teal (#00C9B1) para modo normal, blanco para AI |

### Volumen — Alps RK097N

Ver §8 para specs completos del RK097N.

Knob: Ø12mm, altura 10mm, estilo "chicken head" discreto o cylindrical. El VOL queda en la esquina inferior izquierda del panel — accesible con el pulgar de la mano izquierda sin requerir atención visual.

---

## 8. Potenciómetro de Volumen — Alpha RV09 (recomendado BOM)

**Status: PROPUESTO — mismo footprint 9mm, D-shaft disponible, $0.25/unit**

El control de volumen no requiere calidad de parámetro de síntesis — es un nivel de salida que el usuario toca una vez al inicio del set. Un pot de gama media es suficiente. El **Alpha RV09** es el estándar del mundo Eurorack DIY (Mutable Instruments, Befaco, cientos de módulos open-source) y tiene el mismo footprint 9mm que el RK097N a un tercio del precio.

### Specs Alpha RV09

| Parámetro | Valor | Notas |
|---|---|---|
| Body footprint | 9×9mm | Igual que RK097N |
| Altura desde PCB (body) | ~13mm | |
| Shaft diámetro | 6mm | **D-shaft disponible** — pedir variante "D" al ordenar |
| Shaft largo | 15mm (estándar) | |
| Rotación total | 300° | |
| Cutout panel | **Ø7mm** | 6mm shaft + 0.5mm clearance/lado |
| Taper | A (audio/log) y B (lineal) | Usar **A** para volumen |
| Pin layout | 3 pines en fila, pitch 5mm | Compatible con footprint RK097N |
| Vida útil | ~10,000 ciclos | Suficiente para uso de instrumento |
| Precio unitario | **~$0.20–0.40 USD** | LCSC, AliExpress |

### Jerarquía de opciones (de más a menos económico)

| Parte | Precio/unit | D-shaft | Calidad | Cuándo usar |
|---|---|---|---|---|
| Generic 9mm (WH9011/B9) | **$0.08–0.15** | Algunas vars. | Básica | Producción alto volumen, qty >500 |
| **Alpha RV09** ← recomendado | **$0.20–0.40** | Sí | Buena | Prototipo y producción v1.0 |
| Bourns PTV09A | $0.35–0.55 | Sí | Muy buena | Si el RV09 no está disponible |
| Alps RK097N | $0.80–1.50 | No | Premium | Descartado — overkill para volumen |

### Dónde conseguir en Colombia

- **LCSC** (lcsc.com): envío DHL a Bogotá, 5-7 días hábiles, mínimo de pedido ~$20 USD
- **AliExpress** sellers: más barato, 15-30 días, riesgo de calidad variable — aceptable para prototipo
- **Mercado Libre Colombia**: buscar "potenciometro 9mm audio B10K" — calidad varía, pedir muestra antes de qty

Al ordenar especificar: **Alpha RV09 Series, shaft D tipo, taper A (audio), 10kΩ** (el valor exacto de resistencia lo define el hardware engineer según el circuito de nivel de salida del SGTL5000).

---

## 9. Especificaciones de Cutouts

**Status: PROPUESTO v0.3**

### Top Panel (aluminio CNC 2mm)

| Componente | Forma | Dimensión nominal | Tolerancia | Notas |
|---|---|---|---|---|
| Display GC9A01 | Circular | Ø35.0mm | ±0.1mm | Bezel oculta el gap |
| ENC1 / ENC2 shaft | Circular | Ø6.5mm | ±0.05mm | D-shaft Ø6mm |
| ENC NAV shaft | Circular | Ø6.5mm | ±0.05mm | |
| LED ring (ventana visual) | Anular | ext Ø38mm, int Ø28mm | ±0.1mm | Ajustar según resolución D-08 |
| B1 / B2 / B3 / B4 | Cuadrado | 14.0×14.0mm | ±0.1mm | Keycap Choc V2 pasa por aquí |
| VOL shaft (Alpha RV09) | Circular | Ø7.0mm | ±0.05mm | Shaft 6mm D-type + 0.5mm clearance |

### Panel Lateral Izquierdo (PETG + Guadua alineados)

| Componente | Forma | Dimensión PETG | Dimensión Guadua |
|---|---|---|---|
| 1/4" TRS IN L | Circular | Ø10.5mm ±0.3 | Ø10.5mm ±0.5 |
| 1/4" TRS IN R | Circular | Ø10.5mm ±0.3 | Ø10.5mm ±0.5 |
| 3.5mm AUX IN | Circular | Ø7.0mm ±0.3 | Ø7.0mm ±0.5 |

### Panel Lateral Derecho (PETG + Guadua alineados) — v0.4

| Componente | Forma | Dim. PETG | Dim. Guadua | Z desde fondo |
|---|---|---|---|---|
| USB-C (Power + Audio/MIDI) | Rectangular | 10.5×5.0mm ±0.3 | 11.0×5.5mm ±0.5 | 15mm |
| 1/4" TRS OUT L | Circular | Ø10.5mm ±0.3 | Ø11.0mm ±0.5 | 38mm |
| 1/4" TRS OUT R | Circular | Ø10.5mm ±0.3 | Ø11.0mm ±0.5 | 60mm |
| USB-C Host | Rectangular | 10.5×5.0mm ±0.3 | 11.0×5.5mm ±0.5 | 82mm |

**Nota implementacion:** El PETG body tiene los cutouts en la pared interna. El pigtail
micro-USB→USB-C del Teensy se enruta al cutout de 15mm. El cable USB Host del Teensy
(5V, D+, D-, GND) se enruta al cutout de 82mm. Ambos cutouts son identicos (misma forma, misma herramienta).

---

## 10. Estrategia de Ensamblaje v0.3

**Status: PROPUESTO**

### Orden de ensamblaje

```
1.  Imprimir PETG body (180×100mm, perfil 30→42mm)
2.  Instalar heat inserts M3: 6× PCB standoff + 4× aluminio + 4× cheeks (2 por lado)
3.  Montar PCB principal con standoffs M3×5
4.  Instalar ESP32-S3 module sobre bracket display (elevado)
5.  Preparar cheeks guadua: laminar → cortar → lijar → sellar (48h secado)
6.  Hacer cutouts en PETG walls laterales (jacks + USB)
7.  Encajar cheeks en rebaje PETG + Araldite + tornillos M3 ocultos
8.  Hacer cutouts en guadua (guiados por PETG, taladro pasante)
9.  Lijar bordes cutouts guadua (lija P400 enrollada)
10. Montar jacks y conectores en paneles laterales
11. Atornillar top panel aluminio (4× M3 countersunk en esquinas)
12. Instalar knobs y keycaps
13. Pegar patas antideslizantes en base (4× silicona Ø10mm)
```

### Fijaciones — resumen

| Tipo | Componentes | Cant. | Comentario |
|---|---|---|---|
| Heat inserts M3 latón | PCB + aluminio + cheeks | 14 total | 6+4+2+2 |
| Tornillos M3×8 SS countersunk | PCB a PETG | 6 | Desde arriba |
| Tornillos M3×6 SS countersunk | Aluminio a PETG | 4 | Visibles, estéticos |
| Tornillos M3×16 SS | Cheeks a PETG (ocultos) | 4 | 2 por cheek |
| Araldite estructural | Cheeks a PETG | — | Adhesivo primario |
| Patas silicona Ø10mm | Base | 4 | Antideslizante + eleva base 3mm |

---
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

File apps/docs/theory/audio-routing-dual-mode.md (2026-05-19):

# Audio Routing Dual-Mode — Theory & Design Recommendation

> **GrooveForge Brain — Theory Document**
> **Author:** Hardware Engineer (Claude, based on SGTL5000 Rev 6.0 datasheet + project specs)
> **Date:** Mayo 2026
> **Status:** Draft — para revision del founder antes de actualizar specs canónicos
> **Refs:** SGTL5000 datasheet Rev 6.0 (Freescale/NXP), `01-architecture.md` v0.3, `03-filter-design.md` v0.1

---

## Resumen ejecutivo

**Recomendación: Opción 1 — switch analógico externo TS3A5017 (o equivalente DPDT/dual-SPDT) controlado por GPIO 27 del Teensy.**
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

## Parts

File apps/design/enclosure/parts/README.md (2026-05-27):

# GrooveForge Brain — Enclosure Parts Specs

> **Autor:** Industrial Design Agent
> **Version:** 0.1
> **Status:** ACTIVO
> **Fecha:** 2026-05-26
> **Derivado de:** `apps/design/enclosure/01-enclosure-design-spec.md` v0.3

Este directorio contiene los specs modulares de fabricacion del enclosure GrooveForge Brain.
Cada archivo es autocontenido: un modelador CAD puede leer solo su archivo y modelar esa pieza
sin necesitar el spec maestro para cada detalle.

El spec maestro (`01-enclosure-design-spec.md`) es la fuente de autoridad. Estos archivos
lo *derivan* y *citan*, no lo reemplazan. Si hay conflicto, gana el spec maestro.

---

## Indice de archivos

| Archivo | Pieza | Material | Status |
|---|---|---|---|
| `00-master-parameters.md` | User parameters Fusion 360 (SSoT) | — | PROPUESTO |
| `01-petg-body.md` | Cuerpo PETG impreso (shell + standoffs + rebajes) | PETG dark anthracite | PROPUESTO |
| `02-top-panel-aluminum.md` | Panel superior aluminio CNC con todos los cutouts | Al 6061-T6 anodizado | PROPUESTO |
| `03-cheek-left-guadua.md` | Cheek izquierdo guadua (audio IN) | Guadua angustifolia laminada | PROPUESTO |
| `04-cheek-right-guadua.md` | Cheek derecho guadua (audio OUT + USB) | Guadua angustifolia laminada | PROPUESTO |
| `05-display-bracket.md` | Bracket elevacion ESP32-S3 + display GC9A01 | PETG dark anthracite | PROPUESTO |
| `99-assembly.md` | Ensamblaje completo, fijaciones, orden de montaje | — | PROPUESTO |

---

## Grafico de dependencias entre piezas

Las piezas no son independientes: algunas deben estar definidas (o modeladas) antes que otras.

```
00-master-parameters
        |
        +--------+--------+--------+--------+
        |        |        |        |        |
   01-petg   02-top    03-cheek  04-cheek  05-bracket
    body     panel      left      right
        |        |        |        |
        +--------+--------+--------+
                          |
                    99-assembly
```

### Dependencias detalladas

| Pieza | Requiere definida primero | Motivo |
|---|---|---|
| `00-master-parameters` | Ninguna | Es el SSoT |
| `01-petg-body` | `00-master-parameters` | Usa BODY_W, BODY_D, BODY_H_F, BODY_H_R, WALL_T, etc. |
| `02-top-panel-aluminum` | `00-master-parameters`, `01-petg-body` | Los 4 puntos de montaje van sobre los heat inserts del PETG |
| `03-cheek-left-guadua` | `01-petg-body` | El perfil de altura sigue el loft del PETG; el rebaje de encastre define la anchura interna |
| `04-cheek-right-guadua` | `01-petg-body` | Idem izquierdo |
| `05-display-bracket` | `01-petg-body`, `02-top-panel-aluminum` | Se monta sobre el top panel; el bracket no puede interferir con la cara inferior del aluminio |
| `99-assembly` | Todas las anteriores | Ensamble completo |

---

## Status de modelado por pieza

| Pieza | Spec escrito | CAD en Fusion | Impreso/fabricado | Fit validado |
|---|:---:|:---:|:---:|:---:|
| `00-master-parameters` | SI | PENDIENTE | — | — |
| `01-petg-body` | SI | PENDIENTE | PENDIENTE | PENDIENTE |
| `02-top-panel-aluminum` | SI | PENDIENTE | PENDIENTE | PENDIENTE |
| `03-cheek-left-guadua` | SI | PENDIENTE | PENDIENTE | PENDIENTE |
| `04-cheek-right-guadua` | SI | PENDIENTE | PENDIENTE | PENDIENTE |
| `05-display-bracket` | SI | PENDIENTE | PENDIENTE | PENDIENTE |
| `99-assembly` | SI | PENDIENTE | PENDIENTE | PENDIENTE |

---

## Orden recomendado de modelado en Fusion 360

El orden va de menor a mayor riesgo de retrabajo:

### Prioridad 1 — PETG body (01)
El PETG body es la pieza madre del ensamblaje. Todo lo demas se referencia a ella.
Modelarla primero y validar su perfil de loft (42mm frontal, 30mm trasero) con una
impresion rapida en PLA (ver §13 del master spec, Fase 1-2).

### Prioridad 2 — Top panel aluminio (02)
El panel no puede mandarse al CNC de Bogota sin estar el PETG body impreso: los 4 puntos
de montaje M3 deben verificarse fisicamente antes de pagar el CNC. Imprimir el panel en PLA
primero (Fase 1 del plan de impresion en §13 del master spec).

### Prioridad 3 — Cheeks guadua izquierdo y derecho (03, 04)
El perfil de altura de los cheeks depende del loft del PETG. Modelar juntos. Los cutouts
de jacks y USB se hacen post-ensamblaje (guiados por el PETG), por lo que el riesgo
de error en el modelo 3D es bajo — el riesgo real es en la manufactura fisica.

### Prioridad 4 — Display bracket (05)
La altura del bracket (BRACKET_H = 15mm) se verifica solo despues de tener el PETG impreso
y el top panel. Cualquier ajuste de altura del bracket no afecta las otras piezas.

### Prioridad 5 — Assembly (99)
El assembly en Fusion sirve para detectar interferencias antes de fabricar. Construirlo
despues de tener los cuerpos sólidos individuales.

---

## Como usar este directorio con Fusion MCP

### 1. Cargar parametros
Ejecutar el script Python de `00-master-parameters.md` §Script Python via `fusion_mcp_execute`.
Verificar que todos los parametros aparezcan en `Modify > Change Parameters`.

### 2. Modelar por pieza
Cada archivo `01` a `05` tiene una seccion "§8 Workflow Fusion 360" con los pasos
ejecutables en orden. Usar `fusion_mcp_execute` para cada operacion.

### 3. Verificar en assembly
Ensamblar en `99-assembly.md`. Usar `fusion_mcp_read` para leer el estado del modelo
y detectar interferencias con `Inspect > Interference`.

### 4. Exportar
Cada pieza tiene una seccion "§7 Export targets" con el path exacto en `apps/design/3d-models/`
y los settings de export. Usar `fusion_mcp_execute` para automatizar el export.

---

## Convencion de naming de archivos exportados

```
apps/design/3d-models/
├── 01-petg-body.f3d          # Fusion archive — historial editable
├── 01-petg-body.step         # Para slicers y verificacion
├── 01-petg-body.stl          # Para impresion directa
├── 02-top-panel.f3d
├── 02-top-panel.step         # Para CNC (Bogota)
├── 02-top-panel.dxf          # Para CNC 2D si el proveedor lo requiere
├── 03-cheek-left.f3d
├── 03-cheek-left.step
├── 04-cheek-right.f3d
├── 04-cheek-right.step
├── 05-display-bracket.f3d
├── 05-display-bracket.step
├── 05-display-bracket.stl
└── 99-assembly.f3d           # Ensamblaje completo con joints
```

Formato de version en nombre de archivo cuando hay revisiones: `01-petg-body_v02.step`.
El archivo sin sufijo de version es siempre la version mas reciente aprobada.

---

## Contacto y proveedores (Bogota)

| Servicio | Proveedor candidato | Tiempo estimado | Costo referencia |
|---|---|---|---|
| CNC aluminio top panel | CNC local Bogota (por confirmar) | 5-7 dias habiles | $6.00/ud @ qty 100 |
| Impresion PETG | Impresora propia o servicio local | 18-22h por unidad | $5.00/ud |
| Guadua laminada | Proveedor local guadua angustifolia | Por lote | $2.50/ud (2 cheeks) |

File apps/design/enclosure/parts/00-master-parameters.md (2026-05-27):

# GrooveForge Brain — Master Parameters (Fusion 360)

> **Autor:** Industrial Design Agent
> **Version:** 0.1
> **Status:** PROPUESTO
> **Derivado de:** `apps/design/enclosure/01-enclosure-design-spec.md` v0.3, §12
> **Fecha:** 2026-05-26
>
> SSoT de todos los user parameters de Fusion 360 para el ensamblaje GrooveForge Brain.
> Cambiar un valor aqui se propaga a todas las piezas que lo referencian.
> NO editar valores aqui sin actualizar tambien las piezas dependientes (columna "Piezas").

---

## Convencion de coordenadas (Fusion 360 Y-UP)

| Eje | Direccion | Referencia zero |
|-----|---|---|
| X | Derecha (vista frontal del instrumento) | Centro del body = X=0; borde izquierdo PETG = X=-90mm |
| Y | Arriba (vertical) | Base del instrumento = Y=0 |
| Z | Hacia el usuario (profundidad, frente = Z positivo) | Panel trasero PETG = Z=0; panel frontal = Z=+100mm |

El top panel esta en el plano XZ a altura Y = BODY_H = 38mm (caja rectangular — v0.6).
Las coordenadas de componentes en §3 del master spec usan el sistema de coordenadas del top panel:
X desde borde izquierdo panel (0 a 180mm), Y_panel desde borde trasero panel (0 a 100mm).
En Fusion se traduce a X_fusion = X_panel - 90, Z_fusion = Y_panel / 10 (cm).
BODY_H_F, BODY_H_R y TILT_ANGLE eliminados en v0.6 — ver §1.

---

## 1. Dimensiones Globales del Cuerpo

> **v0.6 — Caja rectangular para stack modular con Pogo pins**
> Razon: el Brain se apila fisicamente sobre slaves/mixer via Pogo pins en la cara trasera.
> La inclinacion original (H_F=42, H_R=30, 7deg) impedia que el brain asentara plano sobre otros
> modulos. Solucion: caja rectangular unificada H=38mm. La ergonomia se resuelve con un stand
> externo opcional (inclinable 10-15deg, imprimible en PETG) — no forma parte del enclosure.
> Decision tomada: 2026-05-27.

| Parametro | Valor | Unidad | Descripcion | Piezas | Fuente |
|---|---|---|---|---|---|
| `BODY_W` | 180.0 | mm | Ancho del PETG body central | 01, 02 | §1 master spec |
| `BODY_D` | 100.0 | mm | Profundidad del PETG body (frente a trasero) | 01, 02, 03, 04 | §1 master spec |
| `BODY_H` | 38.0 | mm | Altura del PETG body (caja rectangular — mismo valor frente y trasero) | 01, 02, 03, 04 | v0.6 stack modular |
| `TOTAL_W` | 204.0 | mm | Ancho total instrumento con cheeks | 99 | §1 master spec |

> **ELIMINADOS en v0.6:** `BODY_H_F` (42mm), `BODY_H_R` (30mm), `TILT_ANGLE` (7deg).
> Usar `BODY_H = 38mm` en todas las piezas. Calculo: base 3mm + standoff PCB 5mm +
> componentes max 25mm + clearance 2mm + sin tapa (aluminio cierra arriba) = 35mm min → 38mm.

> **Stack Pogo:** el conector Pogo (6-pin Wurth WR-WST) permanece en la cara TRASERA (Z=0).
> El stack es una cadena horizontal Brain → [Slave] → [Mixer] con caras traseras comunicadas.
> Las unidades pueden apilarse verticalmente (Brain encima de un slave) porque top/bottom son planos.

---

## 2. Espesores y Clearances

| Parametro | Valor | Unidad | Descripcion | Piezas | Fuente |
|---|---|---|---|---|---|
| `WALL_T` | 3.0 | mm | Espesor pared PETG (todos los lados) | 01 | §12 master spec |
| `PANEL_T` | 2.0 | mm | Espesor top panel aluminio | 02 | §12 master spec |
| `CHEEK_T` | 12.0 | mm | Espesor cheeks guadua (cada lado) | 03, 04 | §12 master spec |
| `PCB_W` | 168.0 | mm | Ancho PCB main (BODY_W - 2*WALL_T - 2*PCB_CLEAR) | 01 | §1 master spec |
| `PCB_D` | 88.0 | mm | Profundidad PCB main | 01 | §1 master spec |
| `PCB_CLEAR` | 3.0 | mm | Clearance entre PCB y pared interna PETG | 01 | §1 master spec |
| `CORNER_R` | 3.0 | mm | Radio de esquinas top panel aluminio | 02 | §12 master spec |
| `CHEEK_REBAJE_D` | 6.0 | mm | Profundidad del rebaje PETG para encastre de cheek | 01, 03, 04 | §10 master spec |

---

## 3. Standoffs y Fijaciones

| Parametro | Valor | Unidad | Descripcion | Piezas | Fuente |
|---|---|---|---|---|---|
| `STANDOFF_H` | 5.0 | mm | Altura standoffs PCB sobre fondo PETG | 01 | §12 master spec |
| `STANDOFF_OD` | 6.0 | mm | Diametro exterior columna standoff PETG | 01 | Fabricacion estandar M3 |
| `INSERT_M3_OD` | 4.2 | mm | Diametro agujero para heat insert M3 (latarticulation D4.2) | 01, 03, 04 | Estandar Voron/heatset |
| `INSERT_M3_H` | 6.0 | mm | Altura heat insert M3 | 01 | Estandar |
| `SCREW_PANEL_CSINK` | 3.2 | mm | Diametro agujero countersink M3 en aluminio | 02 | Estandar M3 CS |
| `PANEL_MTG_X1` | 10.0 | mm | X desde borde panel: posicion tornillo esquina izq | 02 | Calculo clearance |
| `PANEL_MTG_X2` | 170.0 | mm | X desde borde panel: posicion tornillo esquina der | 02 | Calculo clearance |
| `PANEL_MTG_Y1` | 8.0 | mm | Y_panel desde borde trasero: tornillo trasero | 02 | Calculo clearance |
| `PANEL_MTG_Y2` | 92.0 | mm | Y_panel desde borde frontal: tornillo frontal | 02 | Calculo clearance |
| `PATA_D` | 10.0 | mm | Diametro patas silicona base | 01 | §10 master spec |
| `PATA_H` | 3.0 | mm | Altura patas silicona (eleva base) | 01 | §10 master spec |

---

## 4. Cutouts — Top Panel (encoders)

| Parametro | Valor | Unidad | Descripcion | Piezas | Fuente |
|---|---|---|---|---|---|
| `ENC_HOLE` | 6.5 | mm | Diametro cutout shaft encoder EC11 (D-shaft 6mm + 0.5mm) | 02 | §9 master spec |
| `ENC_HOLE_TOL` | 0.05 | mm | Tolerancia cutout shaft encoder (CNC) | 02 | §9 master spec |

### Posiciones encoders (coordenadas panel: X desde borde izq, Y_panel desde borde trasero)

| Parametro | Valor | Unidad | Descripcion | Piezas | Fuente |
|---|---|---|---|---|---|
| `ENC1_X` | 22.0 | mm | ENC1 CUTOFF: X desde borde izquierdo panel | 02 | §3 master spec |
| `ENC1_Y` | 55.0 | mm | ENC1 CUTOFF: Y desde borde trasero panel | 02 | §3 master spec |
| `ENC2_X` | 158.0 | mm | ENC2 RESONANCE: X desde borde izquierdo panel | 02 | §3 master spec |
| `ENC2_Y` | 55.0 | mm | ENC2 RESONANCE: Y desde borde trasero panel | 02 | §3 master spec |
| `ENCNAV_X` | 90.0 | mm | ENC NAV ACTION: X (centro panel) | 02 | §3 master spec |
| `ENCNAV_Y` | 22.0 | mm | ENC NAV ACTION: Y desde borde trasero (RESOLUCION D-08: movido de 30 a 22) | 02 | D-08 resuelto |

---

## 5. Cutouts — Top Panel (display)

> **v0.5 — Dimensiones reales del modulo Waveshare ESP32-S3-Touch-LCD-1.28 (datasheet verificado):**
> - Vidrio exterior OD: Ø38.51mm — demasiado grande para pasar por el cutout (correcto: labio de vidrio)
> - Viewing area activa: Ø35.67mm — el cutout debe ser mayor que esto para no obstruir
> - PCB circular: Ø41mm — el bracket debe contenerlo desde abajo
> - Instalacion: modulo va DEBAJO del panel aluminio; vidrio presionado contra cara inferior del panel;
>   el cutout Ø36mm es una ventana — el labio de vidrio (38.51 - 36 = 2.51mm total) impide que caiga.

| Parametro | Valor | Unidad | Descripcion | Piezas | Fuente |
|---|---|---|---|---|---|
| `GLASS_OD` | 38.51 | mm | Diametro exterior vidrio GC9A01 (LENS OD datasheet) | 02, 05 | Waveshare datasheet |
| `GLASS_VA` | 35.67 | mm | Viewing area activa del display (LENS V.A datasheet) | 02, 05 | Waveshare datasheet |
| `DISPLAY_CUT` | 36.0 | mm | Diametro cutout ventana en aluminio (>GLASS_VA=35.67mm; <GLASS_OD=38.51mm → labio 1.25mm/lado) | 02 | v0.5 datasheet |
| `DISPLAY_CUT_TOL` | 0.1 | mm | Tolerancia cutout display (CNC) | 02 | §9 master spec |
| `DISPLAY_X` | 90.0 | mm | Display: X desde borde izquierdo panel | 02 | §3 master spec |
| `DISPLAY_Y` | 60.0 | mm | Display: Y desde borde trasero panel (RESOLUCION D-08: movido de 57 a 60) | 02 | D-08 resuelto |

---

## 6. Cutouts — Top Panel (LED ring ENC NAV)

| Parametro | Valor | Unidad | Descripcion | Piezas | Fuente |
|---|---|---|---|---|---|
| `RING_EXT_D` | 32.0 | mm | Diametro exterior ventana LED ring (RESOLUCION D-08: reducido de 38 a 32mm) | 02 | D-08 resuelto |
| `RING_INT_D` | 24.0 | mm | Diametro interior ventana LED ring (ajustado proporcionalmente) | 02 | D-08 resuelto |
| `RING_TOL` | 0.1 | mm | Tolerancia cutout anular (CNC) | 02 | §9 master spec |

---

## 7. Cutouts — Top Panel (botones Kailh Choc V2)

> **v0.5 — Layout columnas verticales:** Los botones se agrupan en dos columnas verticales
> (una entre ENC1 y display, otra entre display y ENC2). Cada columna tiene 2 botones
> apilados en Y. Clearance minimo con cualquier elemento adyacente: 13mm.
> Layout: [ENC1] [B1/B2 columna] [DISPLAY] [B3/B4 columna] [ENC2], ENCNAV debajo.

| Parametro | Valor | Unidad | Descripcion | Piezas | Fuente |
|---|---|---|---|---|---|
| `BTN_CUT` | 14.0 | mm | Lado del cutout cuadrado botones Choc V2 | 02 | §9 master spec |
| `BTN_CUT_TOL` | 0.1 | mm | Tolerancia cutout botones (CNC) | 02 | §9 master spec |
| `BTN_PITCH_V` | 22.0 | mm | Pitch vertical centro a centro dentro de cada columna (B1↔B2, B3↔B4) | 02 | v0.5 calculo clearance |
| `B_COL_L_X` | 52.0 | mm | X columna izquierda (B1+B2): centrada entre ENC1 knob y borde display | 02 | v0.5 layout |
| `B_COL_R_X` | 128.0 | mm | X columna derecha (B3+B4): simetrica, 180 - B_COL_L_X | 02 | v0.5 layout |
| `BTN_Y_UPPER` | 66.0 | mm | Y_panel boton superior de cada columna (B1, B3) — mas cerca del frente | 02 | v0.5 layout |
| `BTN_Y_LOWER` | 44.0 | mm | Y_panel boton inferior de cada columna (B2, B4) — mas cerca del fondo | 02 | v0.5 layout |
| `B1_X` | 52.0 | mm | B1 ENGINE: X panel (= B_COL_L_X) | 02 | v0.5 |
| `B1_Y` | 66.0 | mm | B1 ENGINE: Y panel (= BTN_Y_UPPER) | 02 | v0.5 |
| `B2_X` | 52.0 | mm | B2 FX: X panel (= B_COL_L_X) | 02 | v0.5 |
| `B2_Y` | 44.0 | mm | B2 FX: Y panel (= BTN_Y_LOWER) | 02 | v0.5 |
| `B3_X` | 128.0 | mm | B3 AI/SCALE: X panel (= B_COL_R_X) | 02 | v0.5 |
| `B3_Y` | 66.0 | mm | B3 AI/SCALE: Y panel (= BTN_Y_UPPER) | 02 | v0.5 |
| `B4_X` | 128.0 | mm | B4 PRESET: X panel (= B_COL_R_X) | 02 | v0.5 |
| `B4_Y` | 44.0 | mm | B4 PRESET: Y panel (= BTN_Y_LOWER) | 02 | v0.5 |

---

## 8. Cutouts — Top Panel (potenciometro volumen)

| Parametro | Valor | Unidad | Descripcion | Piezas | Fuente |
|---|---|---|---|---|---|
| `VOL_HOLE` | 7.0 | mm | Diametro cutout shaft Alpha RV09 (D-shaft 6mm + 0.5mm clearance/lado) | 02 | §9 master spec |
| `VOL_HOLE_TOL` | 0.05 | mm | Tolerancia cutout VOL shaft (CNC) | 02 | §9 master spec |
| `VOL_X` | 22.0 | mm | VOL pot: X desde borde izquierdo panel | 02 | §3 master spec |
| `VOL_Y` | 14.0 | mm | VOL pot: Y desde borde trasero panel | 02 | §3 master spec |

---

## 9. Cutouts — Paneles Laterales (jacks audio)

| Parametro | Valor | Unidad | Descripcion | Piezas | Fuente |
|---|---|---|---|---|---|
| `JACK_HOLE` | 10.5 | mm | Diametro cutout jack 1/4" TRS | 03, 04 | §9 master spec |
| `JACK_HOLE_PETG_TOL` | 0.3 | mm | Tolerancia cutout jack en PETG (FDM) | 01, 03 | §9 master spec |
| `JACK_HOLE_GUAD_TOL` | 0.5 | mm | Tolerancia cutout jack en guadua (herramienta de mano) | 03, 04 | §9 master spec |
| `JACK_Z` | 21.0 | mm | Altura Z del centro de todos los jacks laterales desde base | 03, 04 | §4, §5 master spec |
| `MINI_JACK_HOLE` | 7.0 | mm | Diametro cutout jack 3.5mm | 03 | §9 master spec |

### Posiciones jacks — Cheek LEFT (Y desde fondo del instrumento, Z=fondo a frente)

| Parametro | Valor | Unidad | Descripcion | Piezas | Fuente |
|---|---|---|---|---|---|
| `L_TRS_INL_Z` | 30.0 | mm | Jack TRS IN L: Z desde panel trasero | 03 | §4 master spec |
| `L_TRS_INR_Z` | 55.0 | mm | Jack TRS IN R: Z desde panel trasero | 03 | §4 master spec |
| `L_MINIJACK_Z` | 78.0 | mm | Jack 3.5mm AUX IN: Z desde panel trasero | 03 | §4 master spec |

### Posiciones puertos — Cheek RIGHT (v0.4 — 4 puertos, todo USB-C)

> v0.4: USB-C Power + USB-C Teensy consolidados en 1 conector. USB-A reemplazado por USB-C Host.
> D-10 resuelto: clearance frontal 12.75mm (vs 0.5mm en v0.3).
> Implementacion prototipo v0.2: pigtail interno micro-USB (Teensy dev) → USB-C female panel-mount.

| Parametro | Valor | Unidad | Descripcion | Piezas | Fuente |
|---|---|---|---|---|---|
| `R_USBC_DATA_Z` | 15.0 | mm | USB-C (Power + Audio/MIDI Teensy): Z desde panel trasero | 01, 04 | §5 v0.4 |
| `R_TRS_OUTL_Z` | 38.0 | mm | Jack TRS OUT L: Z desde panel trasero | 01, 04 | §5 v0.4 |
| `R_TRS_OUTR_Z` | 60.0 | mm | Jack TRS OUT R: Z desde panel trasero | 01, 04 | §5 v0.4 |
| `R_USBC_HOST_Z` | 82.0 | mm | USB-C Host (MIDI teclado): Z desde panel trasero — D-10 RESUELTO | 01, 04 | §5 v0.4 |

---

## 10. Cutouts — Paneles Laterales (USB)

| Parametro | Valor | Unidad | Descripcion | Piezas | Fuente |
|---|---|---|---|---|---|
| `USBC_W` | 10.5 | mm | Cutout USB-C ancho (v0.4: ambos puertos right son USB-C identicos) | 01, 04 | §9 v0.4 |
| `USBC_H` | 5.0 | mm | Cutout USB-C alto | 01, 04 | §9 v0.4 |
| `USBC_PETG_TOL` | 0.3 | mm | Tolerancia cutout USB-C en PETG | 01, 04 | §9 v0.4 |

---

## 11. Cutouts — Panel Trasero (pogo connector)

| Parametro | Valor | Unidad | Descripcion | Piezas | Fuente |
|---|---|---|---|---|---|
| `POGO_X` | 90.0 | mm | Pogo 6-pin: X centro desde borde izquierdo PETG | 01 | §6 master spec |
| `POGO_Z` | 0.0 | mm | Pogo: en la cara trasera (Z=0 en convencion Fusion) | 01 | §6 master spec |
| `POGO_Y_CENTER` | 15.0 | mm | Pogo: altura Y desde base | 01 | §6 master spec |
| `POGO_SLOT_W` | 14.0 | mm | Ancho slot pogo 6-pin Wurth WR-WST | 01 | Datasheet Wurth |
| `POGO_SLOT_H` | 8.0 | mm | Alto slot pogo connector | 01 | Datasheet Wurth |

---

## 12. Display Bracket (ESP32-S3 elevado)

| Parametro | Valor | Unidad | Descripcion | Piezas | Fuente |
|---|---|---|---|---|---|
| `BRACKET_H` | 15.0 | mm | Altura del bracket desde cara inferior del top panel hasta el PCB principal (el modulo queda suspendido debajo del aluminio) | 05 | §0 decisiones v0.3 |
| `BRACKET_BASE_W` | 45.0 | mm | Ancho base bracket (cavity >= Ø41mm PCB + 2mm paredes x2 = 45mm) | 05 | Waveshare datasheet v0.5 |
| `BRACKET_BASE_D` | 45.0 | mm | Profundidad base bracket (igual a W — PCB es circular) | 05 | Waveshare datasheet v0.5 |
| `BRACKET_WALL_T` | 2.0 | mm | Espesor paredes bracket PETG | 05 | Calculo rigidez |
| `ESP32_MODULE_D_PCB` | 41.0 | mm | Diametro PCB circular del modulo ESP32-S3-Touch-LCD-1.28 (Waveshare datasheet) | 05 | Waveshare datasheet v0.5 |
| `ESP32_LCD_STACK_H` | 3.58 | mm | Altura stack TP+LCD del modulo (side view datasheet) | 05 | Waveshare datasheet |

---

## Script Python — Crear todos los parametros en Fusion 360

El siguiente script crea todos los user parameters.
Shift+S en Fusion → Scripts → New Script → pegar y Run.

```python
import adsk.core
import adsk.fusion

def run(context):
    app = adsk.core.Application.get()
    design = adsk.fusion.Design.cast(app.activeProduct)
    params = design.userParameters

    definitions = [
        # --- Dimensiones globales ---
        ("BODY_W",          "180 mm",   "Ancho PETG body central"),
        ("BODY_D",          "100 mm",   "Profundidad PETG body (frente a trasero)"),
        ("BODY_H",          "38 mm",    "Altura PETG body — rectangular v0.6 (BODY_H_F/H_R eliminados)"),
        ("TOTAL_W",         "204 mm",   "Ancho total con cheeks"),
        # --- Espesores ---
        ("WALL_T",          "3 mm",     "Espesor pared PETG"),
        ("PANEL_T",         "2 mm",     "Espesor top panel aluminio"),
        ("CHEEK_T",         "12 mm",    "Espesor cheeks guadua"),
        ("PCB_W",           "168 mm",   "Ancho PCB main"),
        ("PCB_D",           "88 mm",    "Profundidad PCB main"),
        ("PCB_CLEAR",       "3 mm",     "Clearance PCB a pared PETG"),
        ("CORNER_R",        "3 mm",     "Radio esquinas top panel"),
        ("CHEEK_REBAJE_D",  "6 mm",     "Profundidad rebaje PETG para cheek"),
        # --- Standoffs ---
        ("STANDOFF_H",      "5 mm",     "Altura standoffs PCB"),
        ("STANDOFF_OD",     "6 mm",     "Diametro exterior standoff"),
        ("INSERT_M3_OD",    "4.2 mm",   "Agujero heat insert M3"),
        ("INSERT_M3_H",     "6 mm",     "Altura heat insert M3"),
        # --- Cutouts encoders ---
        ("ENC_HOLE",        "6.5 mm",   "Cutout shaft encoder EC11"),
        ("ENC1_X",          "22 mm",    "ENC1 CUTOFF X panel"),
        ("ENC1_Y",          "55 mm",    "ENC1 CUTOFF Y panel"),
        ("ENC2_X",          "158 mm",   "ENC2 RESONANCE X panel"),
        ("ENC2_Y",          "55 mm",    "ENC2 RESONANCE Y panel"),
        ("ENCNAV_X",        "90 mm",    "ENC NAV X panel (centro)"),
        ("ENCNAV_Y",        "22 mm",    "ENC NAV Y panel (D-08 resuelto)"),
        # --- Cutouts display (v0.5 — datasheet verificado) ---
        ("GLASS_OD",        "38.51 mm", "Diametro exterior vidrio GC9A01 (LENS OD)"),
        ("GLASS_VA",        "35.67 mm", "Viewing area activa GC9A01 (LENS V.A)"),
        ("DISPLAY_CUT",     "36 mm",    "Cutout ventana display (>VA=35.67, <OD=38.51, labio 1.25mm)"),
        ("DISPLAY_X",       "90 mm",    "Display X panel"),
        ("DISPLAY_Y",       "60 mm",    "Display Y panel (D-08 resuelto)"),
        # --- Cutouts LED ring ---
        ("RING_EXT_D",      "32 mm",    "Diametro exterior ventana LED ring (D-08)"),
        ("RING_INT_D",      "24 mm",    "Diametro interior ventana LED ring"),
        # --- Cutouts botones (v0.5 — columnas verticales) ---
        ("BTN_CUT",         "14 mm",    "Cutout cuadrado botones Choc V2"),
        ("BTN_PITCH_V",     "22 mm",    "Pitch vertical dentro de columna (B1-B2, B3-B4)"),
        ("B_COL_L_X",       "52 mm",    "X columna izquierda botones"),
        ("B_COL_R_X",       "128 mm",   "X columna derecha botones"),
        ("BTN_Y_UPPER",     "66 mm",    "Y boton superior (B1, B3) — cerca del frente"),
        ("BTN_Y_LOWER",     "44 mm",    "Y boton inferior (B2, B4) — cerca del fondo"),
        ("B1_X",            "52 mm",    "B1 ENGINE X panel (v0.5)"),
        ("B1_Y",            "66 mm",    "B1 ENGINE Y panel (v0.5)"),
        ("B2_X",            "52 mm",    "B2 FX X panel (v0.5)"),
        ("B2_Y",            "44 mm",    "B2 FX Y panel (v0.5)"),
        ("B3_X",            "128 mm",   "B3 AI X panel (v0.5)"),
        ("B3_Y",            "66 mm",    "B3 AI Y panel (v0.5)"),
        ("B4_X",            "128 mm",   "B4 PRESET X panel (v0.5)"),
        ("B4_Y",            "44 mm",    "B4 PRESET Y panel (v0.5)"),
        # --- Cutout VOL ---
        ("VOL_HOLE",        "7 mm",     "Cutout shaft Alpha RV09"),
        ("VOL_X",           "22 mm",    "VOL X panel"),
        ("VOL_Y",           "14 mm",    "VOL Y panel"),
        # --- Cutouts jacks laterales ---
        ("JACK_HOLE",       "10.5 mm",  "Cutout jack 1/4 TRS"),
        ("JACK_Z",          "21 mm",    "Altura Z jacks laterales desde base"),
        ("MINI_JACK_HOLE",  "7 mm",     "Cutout jack 3.5mm"),
        ("L_TRS_INL_Z",     "30 mm",    "TRS IN L: Z desde fondo"),
        ("L_TRS_INR_Z",     "55 mm",    "TRS IN R: Z desde fondo"),
        ("L_MINIJACK_Z",    "78 mm",    "3.5mm AUX IN: Z desde fondo"),
        ("R_USBC_DATA_Z",   "15 mm",    "USB-C Power+Data Teensy: Z desde fondo (v0.4)"),
        ("R_TRS_OUTL_Z",    "38 mm",    "TRS OUT L: Z desde fondo"),
        ("R_TRS_OUTR_Z",    "60 mm",    "TRS OUT R: Z desde fondo"),
        ("R_USBC_HOST_Z",   "82 mm",    "USB-C Host MIDI: Z desde fondo (v0.4, D-10 resuelto)"),
        # --- Cutouts USB ---
        ("USBC_W",          "10.5 mm",  "Cutout USB-C ancho"),
        ("USBC_H",          "5 mm",     "Cutout USB-C alto"),
        # --- Pogo trasero ---
        ("POGO_X",          "90 mm",    "Pogo X desde borde izquierdo PETG"),
        ("POGO_Y_CENTER",   "15 mm",    "Pogo altura Y desde base"),
        ("POGO_SLOT_W",     "14 mm",    "Slot pogo ancho"),
        ("POGO_SLOT_H",     "8 mm",     "Slot pogo alto"),
        # --- Bracket ESP32 (v0.5 — PCB circular Ø41mm, modulo debajo del panel) ---
        ("BRACKET_H",           "15 mm",    "Altura bracket desde cara inf panel hasta PCB principal"),
        ("BRACKET_BASE_W",      "45 mm",    "Ancho base bracket (cavity Ø41mm + 2mm pared x2)"),
        ("BRACKET_BASE_D",      "45 mm",    "Profundidad base bracket"),
        ("BRACKET_WALL_T",      "2 mm",     "Espesor paredes bracket PETG"),
        ("ESP32_MODULE_D_PCB",  "41 mm",    "Diametro PCB circular modulo Waveshare"),
        ("ESP32_LCD_STACK_H",   "3.58 mm",  "Altura stack TP+LCD (datasheet side view)"),
    ]

    valueInput = adsk.core.ValueInput
    unitsMgr = design.unitsManager

    for name, expr, comment in definitions:
        existing = params.itemByName(name)
        if existing:
            existing.expression = expr
            existing.comment = comment
        else:
            params.add(name, valueInput.createByString(expr), "", comment)

    app.userInterface.messageBox("Parametros GrooveForge Brain cargados correctamente.")
```

---

## Reglas de actualizacion

1. Todo cambio de valor en este archivo debe propagarse a las piezas listadas en la columna "Piezas".
2. Despues de cambiar un parametro, re-ejecutar el script Python en Fusion para sincronizar.
3. Las tolerancias (columnas `_TOL`) nunca se cambian sin aprobacion del hardware engineer — afectan fit de componentes fisicos.
4. Los parametros de posicion de componentes (`ENC1_X`, `BTN_Y`, etc.) son SSoT. Si el hardware engineer necesita moverlos, el cambio se documenta aqui primero, luego se actualiza el spec maestro.
5. Los parametros marcados como "D-08 resuelto" o "D-10 resuelto" tienen sus nuevos valores ya integrados — no revertir a los valores del spec maestro v0.3.

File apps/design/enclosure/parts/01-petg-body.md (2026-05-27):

# Part 01 — PETG Body (Cuerpo Central)

> **Autor:** Industrial Design Agent
> **Version:** 0.2 — USB right side v0.4: 5 cutouts → 4 cutouts, todo USB-C
> **Status:** PROPUESTO
> **Material:** PETG dark anthracite (color-stable)
> **Fabricacion:** Impresion 3D FDM
> **Derivado de:** `apps/design/enclosure/01-enclosure-design-spec.md` v0.3, §1, §10, §12, §13
> **Archivo CAD target:**
> - `apps/design/3d-models/01-petg-body.f3d`
> - `apps/design/3d-models/01-petg-body.step`
> - `apps/design/3d-models/01-petg-body.stl`

---

## 0. Funcion de la pieza

El PETG body es el chasis estructural del instrumento. Todas las demas piezas se montan en el o
sobre el. Sus funciones:

- Soporte estructural de la PCB principal via 6 standoffs M3
- Mounting del top panel de aluminio via 4 heat inserts en la cara superior
- Rebaje lateral izquierdo y derecho (12mm x 100mm de profundidad) para encastre de cheeks guadua
- Pared trasera con slot para pogo connector de expansion modular (Wurth WR-WST 6-pin)
- Paneles laterales internos con cutouts alineados para jacks y USB (guian el taladro en guadua)
- Base con 4 cavidades para patas de silicona antideslizante
- Oculta todo el cableado interno y la electronica

El PETG body NO tiene apertura en la cara superior — el top panel de aluminio la cubre completamente.
El acceso interno es por la cara inferior (base abierta o con tapa removible — ver gap identificado).

---

## 1. Material y proceso de fabricacion

| Parametro | Valor |
|---|---|
| Material | PETG color-stable dark anthracite (Polymaker PolyLite PETG Dark Grey o equivalente) |
| Proveedor filamento Bogota | Filamento.co, Impresionet, Amazon.com.co |
| Diametro filamento | 1.75mm |
| Layer height superficies presentacion | 0.2mm |
| Layer height interior (si slicing diferencial) | 0.3mm aceptable |
| Infill | 40% gyroid (rigidez isotrópica sin peso excesivo) |
| Perimetros | 4 minimo (equivale a 3.2mm pared efectiva sobre WALL_T = 3mm nominal) |
| Nozzle temp | 240°C |
| Bed temp | 80°C |
| Velocidad exterior | 40mm/s |
| Brim | 8mm (evitar warping en pieza grande) |
| Soporte | Solo en cavidades de jacks laterales si el angulo supera 45 grados |
| Orientacion impresion | Base hacia abajo (la cara de los cutouts de jacks queda vertical — soportes minimos) |

Tolerancia efectiva FDM para agujeros: ±0.3mm (usar esta tolerancia en §4 para cutouts criticos).
Para cutouts de jacks en pared lateral (Ø10.5mm): imprimir con 10.8mm en el modelo para compensar
el undersize tipico de FDM en agujeros circulares.

Post-proceso: lijar borde de la boca superior (donde asienta el aluminio) con P400 para planitud.
No lijar las superficies que se veran en el instrumento — la textura de FDM es la textura final.

---

## 2. Parametros requeridos del master

Fuente: `00-master-parameters.md`.

| Parametro | Valor | Descripcion |
|---|---|---|
| `BODY_W` | 180mm | Ancho externo PETG body |
| `BODY_D` | 100mm | Profundidad (frente a trasero) |
| `BODY_H` | 38mm | Altura del body (caja rectangular — v0.6; BODY_H_F/H_R eliminados) |
| `WALL_T` | 3mm | Espesor de todas las paredes |
| `PCB_W` | 168mm | Ancho PCB (define posicion standoffs X) |
| `PCB_D` | 88mm | Profundidad PCB (define posicion standoffs Z) |
| `PCB_CLEAR` | 3mm | Clearance PCB a pared interna |
| `CHEEK_REBAJE_D` | 6mm | Profundidad del rebaje lateral para cheeks |
| `STANDOFF_H` | 5mm | Altura standoffs PCB |
| `STANDOFF_OD` | 6mm | Diametro exterior standoffs |
| `INSERT_M3_OD` | 4.2mm | Agujero heat insert M3 |
| `INSERT_M3_H` | 6mm | Altura heat insert M3 |
| `JACK_HOLE` | 10.5mm | Cutout jack 1/4" TRS (usar 10.8mm en modelo por tolerancia FDM) |
| `JACK_Z` | 21mm | Altura Z centro jacks desde base |
| `MINI_JACK_HOLE` | 7mm | Cutout jack 3.5mm (usar 7.3mm por FDM) |
| `USBC_W` | 10.5mm | Cutout USB-C ancho (ambos puertos right son identicos) |
| `USBC_H` | 5mm | Cutout USB-C alto |
| `POGO_X` | 90mm | Centro pogo desde borde izquierdo |
| `POGO_Y_CENTER` | 15mm | Altura Y pogo desde base |
| `POGO_SLOT_W` | 14mm | Ancho slot pogo |
| `POGO_SLOT_H` | 8mm | Alto slot pogo |
| `PATA_D` | 10mm | Diametro cavidad patas silicona |
| `PATA_H` | 2mm | Profundidad cavidad patas (ciego — 1mm de base; 3mm sería pasante con WALL_T=3mm) |
| `L_TRS_INL_Z` | 30mm | TRS IN L: Z desde fondo |
| `L_TRS_INR_Z` | 55mm | TRS IN R: Z desde fondo |
| `L_MINIJACK_Z` | 78mm | AUX IN 3.5mm: Z desde fondo |
| `R_USBC_DATA_Z` | 15mm | USB-C (Power + Audio/MIDI Teensy): Z desde fondo — pigtail micro-USB interno |
| `R_TRS_OUTL_Z` | 38mm | TRS OUT L: Z desde fondo |
| `R_TRS_OUTR_Z` | 60mm | TRS OUT R: Z desde fondo |
| `R_USBC_HOST_Z` | 82mm | USB-C Host MIDI: Z desde fondo — D-10 resuelto |

### Parametros locales

| Parametro local | Valor | Descripcion |
|---|---|---|
| `REBAJE_H` | 100% de la altura del perfil en cada Z | El rebaje para cheeks corre toda la altura |
| `STANDOFF_PCB_DIST_X` | 10mm desde borde PCB | Posicion estandar standoffs en X |
| `STANDOFF_PCB_DIST_Z` | 10mm desde borde PCB | Posicion estandar standoffs en Z |
| `PANEL_INSERT_DIST` | 10mm desde borde exterior | Posicion heat inserts para aluminio |

---

## 3. Geometria — sketches y operaciones (en orden)

### Op. 1: Perfil lateral (Side Profile)
- Plano: plano YZ de Fusion (eje Y = altura, Z = profundidad)
- Sketch "Side_Profile_YZ"
- Geometria: rectangulo (caja plana — v0.6, BODY_H=38mm uniforme)
  - Base inferior: linea Z=0 a Z=BODY_D (Y=0, horizontal)
  - Cara trasera: linea vertical Y=0 a Y=BODY_H=38mm en Z=0
  - Cara frontal: linea vertical Y=0 a Y=BODY_H=38mm en Z=BODY_D
  - Cara superior: linea horizontal de (Z=0, Y=38mm) a (Z=BODY_D, Y=38mm)

### Op. 2: Extrude del perfil (cuerpo solido)
- Seleccionar "Side_Profile_YZ"
- Extrude simetrico en X: BODY_W/2 = 90mm en cada direccion
- Resultado: solido rectangular 180×100×38mm (caja plana, top y bottom paralelos)

### Op. 3: Shell (vaciado interior)
- Shell de 3mm (WALL_T) en todas las caras EXCEPTO:
  - La cara superior (el aluminio la cubre — shell la deja abierta, es la "boca" de la caja)
  - La cara inferior (base — dejar solida con WALL_T = 3mm para rigidez)
- Resultado: caja con techo inclinado abierto, base solida, paredes de 3mm

### Op. 4: Rebaje lateral izquierdo (para cheek guadua)
- Sketch "Cheek_Rebaje_L" en cara lateral izquierda exterior (plano XY, en X = -BODY_W/2)
- Geometria: rectangulo que recorre toda la altura de la cara (ajustandose al perfil inclinado)
  x CHEEK_REBAJE_D = 6mm de profundidad en X
- Cut-extrude: 6mm hacia el interior (en X positivo)
- El rebaje corre los 100mm completos de profundidad (Z=0 a Z=BODY_D)
- Resultado: escalon de 6mm en la cara izquierda donde encaja el cheek

### Op. 5: Rebaje lateral derecho (simetrico)
- Simetrico de Op. 4 respecto al plano XY de Fusion
- Mismo CHEEK_REBAJE_D = 6mm

### Op. 6: Heat inserts para top panel (aluminio)
- 4 pedestales en la cara superior, en las esquinas
- Posiciones (coordenadas X_fusion, Z_fusion):
  - Frente izquierda: X=-80mm, Z=+92mm (Y_panel=92, es decir PANEL_MTG_Y2 desde trasero)
  - Frente derecha: X=+80mm, Z=+92mm
  - Trasera izquierda: X=-80mm, Z=+8mm (Y_panel=8, es decir PANEL_MTG_Y1 desde trasero)
  - Trasera derecha: X=+80mm, Z=+8mm
- Cada pedestal: cilindro STANDOFF_OD=6mm exterior, agujero central INSERT_M3_OD=4.2mm,
  profundidad INSERT_M3_H=6mm
- Los pedestales se extruden hacia arriba desde la cara superior (que es el techo inclinado)

### Op. 7: Heat inserts para PCB (standoffs)
- 6 standoffs en la cara del suelo interno (Y=WALL_T desde la base = 3mm)
- Distribucion: 2 filas de 3 standoffs
  - Fila frontal (Z_fusion = BODY_D - PCB_CLEAR - 10mm = 87mm): X = -74mm, 0mm, +74mm
  - Fila trasera (Z_fusion = PCB_CLEAR + 10mm = 13mm): X = -74mm, 0mm, +74mm
  - Nota: los standoffs extremos en X deben quedar dentro de las paredes PETG.
    Con PCB_W=168mm: PCB se extiende X=-84 a X=+84. Standoffs en X=±74 dan 10mm desde el borde PCB.
- Cada standoff: cilindro STANDOFF_OD=6mm, altura STANDOFF_H=5mm, agujero central INSERT_M3_OD=4.2mm, prof. INSERT_M3_H=6mm
- Extruyen desde el suelo interno hacia arriba (en Y positivo)

### Op. 8: Heat inserts para cheeks
- 2 heat inserts en pared lateral izquierda (en el fondo del rebaje de 6mm)
  - Posicion Z: Z=25mm y Z=75mm desde fondo (centros del area de cheek)
  - Posicion Y: centrados en la altura del perfil en ese Z
  - Agujero INSERT_M3_OD=4.2mm, profundidad INSERT_M3_H=6mm (horizontal en X)
- Espejo en pared lateral derecha

### Op. 9: Cutouts pared lateral izquierda (IN)
- Plano: cara lateral izquierda (despues del rebaje, es decir la superficie interior del canal)
- Cutouts (agujeros pasantes en WALL_T = 3mm de la pared lateral interna que da al interior):
  - TRS IN L: circulo Ø10.8mm (10.5 + tolerancia FDM), centro en (Z=L_TRS_INL_Z=30mm, Y=JACK_Z=21mm)
  - TRS IN R: circulo Ø10.8mm, centro en (Z=L_TRS_INR_Z=55mm, Y=JACK_Z=21mm)
  - 3.5mm AUX IN: circulo Ø7.3mm, centro en (Z=L_MINIJACK_Z=78mm, Y=JACK_Z=21mm)
- Estos cutouts se hacen en la pared INTERNA del PETG (dentro del rebaje de 6mm).
  El cheek guadua que se superpone tendra sus propios cutouts alineados.

### Op. 10: Cutouts pared lateral derecha (OUT + USB) — v0.4

4 puertos, todo USB-C, D-10 resuelto. Sketch "Cut_R_USBC_Data/TRS_OUTL/TRS_OUTR/USBC_Host"
en Plane_Right_Z90 (plano paralelo a xY en Z=+90mm). Cut-extrude -10mm hacia interior.

- USB-C Data: rect 10.8×5.3mm, centro en (Z=R_USBC_DATA_Z=15mm, Y=21mm)
  Pigtail micro-USB (Teensy dev) → USB-C female panel-mount se enruta hasta este cutout.
- TRS OUT L: circulo Ø10.8mm, centro en (Z=R_TRS_OUTL_Z=38mm, Y=21mm)
- TRS OUT R: circulo Ø10.8mm, centro en (Z=R_TRS_OUTR_Z=60mm, Y=21mm)
- USB-C Host: rect 10.8×5.3mm, centro en (Z=R_USBC_HOST_Z=82mm, Y=21mm)
  Clearance frontal: 100-82-5.25=12.75mm — D-10 RESUELTO.

Clearances entre cutouts verificados: 12.5 / 11.5 / 11.5mm — todos OK.

### Op. 11: Cutout panel trasero (pogo)
- Cara trasera (Z=0 en convencion Fusion, que es la pared trasera exterior del PETG body)
- Rectangulo 14.3×8.3mm (POGO_SLOT_W+0.3 x POGO_SLOT_H+0.3)
- Centro en: X=0 (POGO_X=90mm desde borde izquierdo = centro body), Y=POGO_Y_CENTER=15mm desde base
- Cut-extrude pasante (atraviesa WALL_T=3mm de pared trasera)

### Op. 12: Cavidades patas silicona (base)
- Cara inferior exterior (base plana)
- 4 cilindros ciegos: Ø=PATA_D=10mm, profundidad PATA_H=3mm
- Posiciones (X_fusion, Z_fusion): (+/-)80mm x (+/-)45mm (aproximadamente esquinas, 10mm del borde)
- Las patas de silicona se presionan dentro — no necesitan adhesivo si el fit es justo (Ø9.9mm en modelo para leve press-fit)

---

## 4. Cutouts y holes (tabla completa)

| Componente | Cara | Forma | Dim. nominal | Dim. modelo FDM | Tolerancia | Centro X_fusion | Centro Z_fusion | Centro Y |
|---|---|---|---|---|---|---|---|---|
| TRS IN L | Lateral izq. interna | Circular | Ø10.5mm | Ø10.8mm | ±0.3mm | X=exterior izq | Z=30mm | Y=21mm |
| TRS IN R | Lateral izq. interna | Circular | Ø10.5mm | Ø10.8mm | ±0.3mm | X=exterior izq | Z=55mm | Y=21mm |
| 3.5mm AUX IN | Lateral izq. interna | Circular | Ø7.0mm | Ø7.3mm | ±0.3mm | X=exterior izq | Z=78mm | Y=21mm |
| USB-C Data (Power+Audio) | Lateral der. interna | Rectangular | 10.5×5.0mm | 10.8×5.3mm | ±0.3mm | X=exterior der | Z=15mm | Y=21mm |
| TRS OUT L | Lateral der. interna | Circular | Ø10.5mm | Ø10.8mm | ±0.3mm | X=exterior der | Z=38mm | Y=21mm |
| TRS OUT R | Lateral der. interna | Circular | Ø10.5mm | Ø10.8mm | ±0.3mm | X=exterior der | Z=60mm | Y=21mm |
| USB-C Host MIDI | Lateral der. interna | Rectangular | 10.5×5.0mm | 10.8×5.3mm | ±0.3mm | X=exterior der | Z=82mm | Y=21mm |
| Pogo 6-pin | Trasera | Rectangular | 14.0×8.0mm | 14.3×8.3mm | ±0.3mm | X=0 | Z=0 (cara trasera) | Y=15mm |
| Pata silicona x4 | Base | Circular ciego | Ø10mm | Ø9.9mm (press-fit) | ±0.2mm | ±80mm | ±45mm | Y=base |

---

## 5. Interfaces con otras piezas

| Pieza | Tipo de interface | Tolerancia de junta |
|---|---|---|
| Top panel aluminio (02) | 4 heat inserts M3 en pedestales superiores; tornillos M3×6 countersunk desde arriba | Clearance 0.1mm entre aluminio y techo PETG (el aluminio "flota" sobre los inserts) |
| Cheek izquierdo guadua (03) | Rebaje de 6mm en X; Araldite + 2 tornillos M3×16 en heat inserts | El cheek debe tener 0.2mm de clearance en el rebaje para poder ensamblar sin fuerza excesiva |
| Cheek derecho guadua (04) | Idem simetrico | Idem |
| PCB principal | 6 standoffs M3 heat inserts + tornillos M3×8 desde la PCB hacia abajo | Standoff height STANDOFF_H=5mm define el gap entre PCB y fondo interno |
| Display bracket (05) | El bracket cuelga desde la cara inferior del top panel (v0.5: modulo debajo del panel). Sin contacto directo con el PETG body. | Indirecto — via top panel |
| Pogo connector | Slot rectangular en pared trasera; el conector es panel-mount | Clearance 0.3mm alrededor del conector |

---

## 6. Validacion post-fabricacion

| Check | Metodo | Criterio pass |
|---|---|---|
| Planitud cara superior (boca) | Regla de metal apoyada sobre el borde | Luz visible < 0.5mm |
| Ancho externo BODY_W | Calibre digital | 180mm ±0.5mm |
| Profundidad BODY_D | Calibre digital | 100mm ±0.5mm |
| Altura BODY_H | Calibre digital en cara frontal y trasera | 38mm ±0.5mm (mismo valor — caja rectangular) |
| Profundidad rebaje cheek | Calibre de profundidad | 6mm ±0.3mm (en ambos lados) |
| Cutouts jacks laterales | Insertar jack fisico Neutrik NYS229 | El jack entra sin fuerza excesiva, rosca accessible |
| Cutouts USB-C laterales | Insertar conector USB-C macho en cada uno | El conector pasa limpio, sin interferencia |
| Cutout pogo trasero | Verificar con caliper o con el conector fisico | No hay interferencia con las paredes |
| Heat inserts PCB | Atornillar M3×8 con standoffs metalicos | Rosca agarra sin wobble |
| Heat inserts aluminio | Atornillar M3×6 sin top panel | Rosca agarra sin wobble |
| Heat inserts cheeks | Atornillar M3×16 desde el cheek | Rosca agarra sin wobble |

---

## 7. Export targets

| Archivo | Formato | Path | Uso | Settings |
|---|---|---|-----|---|
| PETG body Fusion archive | .f3d | `apps/design/3d-models/01-petg-body.f3d` | Edicion | Save from Fusion |
| PETG body STEP | .step | `apps/design/3d-models/01-petg-body.step` | Verificacion en otros CAD | AP203 o AP214 |
| PETG body STL | .stl | `apps/design/3d-models/01-petg-body.stl` | Impresion 3D directa | Mesh refinement: 0.01mm tolerance, 10 deg angle |

Antes de exportar STL: verificar orientacion (base abajo = Z- en STL) y que no haya superficies no-manifold.

---

## 8. Workflow Fusion 360 (paso a paso ejecutable)

```
1.  Nuevo documento Fusion 360. Guardar como "GrooveForge_Brain_Enclosure".

2.  Ejecutar script Python de 00-master-parameters.md para cargar todos los user parameters.
    Verificar en Modify > Change Parameters que los valores son correctos.

3.  Crear componente "01_PETG_Body" en el browser (root > New Component).
    Activar el componente (doble click en el nombre).

4.  Sketch "Side_Profile_YZ" en plano YZ (plano lateral de Fusion, eje Y=arriba, Z=profundidad):
    - Linea de (0,0) a (0, BODY_H_R): cara trasera
    - Linea de (0,0) a (BODY_D, 0): base inferior
    - Linea de (BODY_D, 0) a (BODY_D, BODY_H_F): cara frontal
    - Linea de (0, BODY_H_R) a (BODY_D, BODY_H_F): techo inclinado
    - Cerrar el perfil. Finish Sketch.

5.  Extrude "Side_Profile_YZ": distancia simetrica BODY_W/2 = 90mm en ambos sentidos del eje X.
    Operacion: New Body. Resultado: solido de 180×100mm con techo inclinado.

6.  Shell: seleccionar la cara superior (techo inclinado) para remover (opening).
    Thickness = WALL_T = 3mm. Aplicar a todas las demas caras.
    ATENCION: la cara inferior (base) debe quedar con WALL_T de espesor — Fusion puede
    querer abrirla tambien. Si eso ocurre, hacer Shell sin la base y agregar la base
    como feature separada.

7.  Sketch "Cheek_Rebaje_L" en cara lateral izquierda exterior (plano que pasa por X = -BODY_W/2):
    - Rectangulo de (Z=0, Y=0) a (Z=BODY_D, Y=BODY_H max en ese punto)
    - En realidad es toda la cara lateral izquierda.
    - Cut extrude: profundidad CHEEK_REBAJE_D = 6mm hacia el interior (en X+).
    NOTA: el resultado debe ser un escalon que reduce la anchura visible del PETG en 6mm por lado.

8.  Mirror feature "Cheek_Rebaje_L" respecto al plano XY (plano de simetria del body):
    Esto crea el rebaje derecho identico.

9.  Pedestales heat inserts top panel (4 unidades):
    Sketch "Panel_Inserts" en el techo inclinado (seleccionar la cara inclinada como plano).
    Crear 4 puntos en las esquinas segun PANEL_MTG_X1/X2 y PANEL_MTG_Y1/Y2.
    Para cada punto: extrude cilindro Ø STANDOFF_OD = 6mm, hacia ABAJO (interior del body),
    altura INSERT_M3_H = 6mm. Luego taladrar agujero central Ø INSERT_M3_OD = 4.2mm, pasante.
    ATENCION: en la cara inclinada, los pedestales deben ser perpendiculares al plano inclinado,
    no verticales. En Fusion, seleccionar la cara como plano base del sketch garantiza esto.

10. Standoffs PCB (6 unidades):
    Sketch "PCB_Standoffs" en el suelo interno (cara interior de la base, Y = WALL_T desde exterior).
    Posiciones X: -74mm, 0mm, +74mm. Posiciones Z: 13mm y 87mm.
    Para cada punto: extrude cilindro Ø STANDOFF_OD = 6mm hacia arriba (Y+), altura STANDOFF_H = 5mm.
    Taladrar agujero central Ø INSERT_M3_OD = 4.2mm, profundidad INSERT_M3_H = 6mm.

11. Heat inserts cheeks (2 por lado = 4 total):
    Sketch "Cheek_Inserts_L" en la cara interior vertical izquierda (el fondo del rebaje de 6mm).
    2 puntos en Z=25mm e Z=75mm, centrados en la altura media del perfil en cada Z.
    Extrude cilindro Ø STANDOFF_OD = 6mm en X (horizontal, hacia el interior del body),
    profundidad = WALL_T suficiente para el insert. Taladrar Ø INSERT_M3_OD = 4.2mm, prof. 6mm.
    Mirror para el lado derecho.

12. Cutouts laterales izquierdos (IN):
    Sketch "Cutouts_Left" en la cara interna izquierda (superficie vertical dentro del rebaje).
    - Circulo Ø10.8mm en (Z=30mm, Y=21mm) para TRS IN L
    - Circulo Ø10.8mm en (Z=55mm, Y=21mm) para TRS IN R
    - Circulo Ø7.3mm en (Z=78mm, Y=21mm) para 3.5mm AUX
    Cut extrude pasante en X (atraviesa la pared de WALL_T=3mm + el rebaje de 6mm).

13. Cutouts laterales derechos (OUT + USB):
    Sketch "Cutouts_Right" en la cara interna derecha.
    - Rectangulo 10.8×5.3mm centrado en (Z=15mm, Y=21mm) para USB-C Power
    - Circulo Ø10.8mm en (Z=38mm, Y=21mm) para TRS OUT L
    - Circulo Ø10.8mm en (Z=60mm, Y=21mm) para TRS OUT R
    - Rectangulo 10.8×5.3mm centrado en (Z=80mm, Y=21mm) para USB-C Teensy
    - Rectangulo 15.3×8.3mm centrado en (Z=92mm, Y=21mm) para USB-A Host
    Cut extrude pasante en X.

14. Cutout pogo trasero:
    Sketch "Cutout_Pogo" en la cara exterior trasera (Z=0 exterior).
    Rectangulo 14.3×8.3mm centrado en (X=0, Y=15mm).
    Cut extrude pasante (WALL_T = 3mm).

15. Cavidades patas silicona:
    Sketch "Rubber_Feet" en la cara exterior de la base.
    4 circulos Ø9.9mm en posiciones (+/-)80mm x (+/-)45mm.
    Cut extrude ciego: profundidad PATA_H = 3mm.

16. Fillets opcionales (esteticos):
    Fillet de 2mm en aristas exteriores verticales del PETG (las 4 aristas verticales del body).
    No aplicar fillets en la boca superior (interfiere con el asiento del aluminio) ni en el rebaje de cheeks.

17. Guardar y exportar (ver §7 Export targets).
```

### Hints para evitar errores comunes en Fusion

- En el paso 6 (Shell): si Fusion falla, probar con "Shell" type "Inside". Si sigue fallando, usar el metodo alternativo: extrude del perfil interior (BODY_W - 2×WALL_T) y restar del solido exterior.
- En el paso 9 (pedestales inclinados): si el sketch en la cara inclinada da problemas, usar un offset plane paralelo a la cara inclinada y extrude hacia la cara.
- En el paso 12 y 13 (cutouts laterales): asegurarse de que el cut-extrude corta tanto la pared PETG (3mm) como el espacio del rebaje (6mm) — hacer el cut con profundidad de al menos 10mm para garantizar que sea pasante.

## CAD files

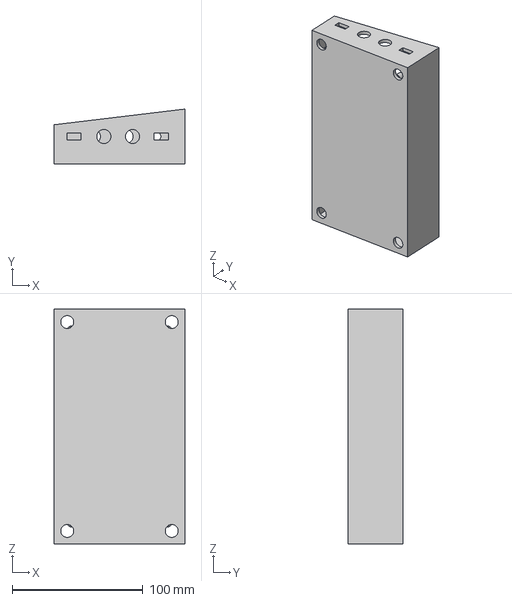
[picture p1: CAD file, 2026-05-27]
apps/design/3d-models/01-petg-body.step
100.0 x 42.0 x 180.0 mm

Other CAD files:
apps/design/3d-models/01-petg-body.f3d
apps/design/3d-models/01-petg-body.stl

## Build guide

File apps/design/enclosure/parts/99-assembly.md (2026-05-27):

# Part 99 — Assembly (Ensamblaje Completo)

> **Autor:** Industrial Design Agent
> **Version:** 0.1
> **Status:** PROPUESTO
> **Derivado de:** `apps/design/enclosure/01-enclosure-design-spec.md` v0.3, §10
> **Archivo CAD target:** `apps/design/3d-models/99-assembly.f3d`

---

## 0. Jerarquia de ensamblaje

```
99-assembly.f3d
│
├── 01_PETG_Body         <- pieza madre, referencia de todos los demas
│   ├── Heat inserts M3 (14 total: 6 PCB + 4 aluminio + 4 cheeks)
│   └── Patas silicona x4 (base)
│
├── 02_Top_Panel_Al      <- asienta sobre 01, 4 tornillos M3×6 CS
│   └── 05_Display_Bracket  <- asienta sobre 02 (pie en cutout display)
│       └── ESP32-S3 module  <- inserto en cavidad del bracket
│
├── 03_Cheek_Left        <- encaja en rebaje izquierdo de 01
│   ├── Jack TRS IN L
│   ├── Jack TRS IN R
│   └── Jack 3.5mm AUX IN
│
├── 04_Cheek_Right       <- encaja en rebaje derecho de 01
│   ├── USB-C Power (conector)
│   ├── Jack TRS OUT L
│   ├── Jack TRS OUT R
│   ├── USB-C Teensy (conector)
│   └── USB-A Host (conector)
│
└── PCB_Main             <- atornillada a standoffs de 01
    ├── Teensy 4.1
    ├── SGTL5000
    ├── Alps RV09 VOL (conecta a top panel via shaft)
    ├── EC11 ENC1/ENC2/ENCNAV (conectan a top panel via shaft)
    ├── Kailh Choc V2 x4 (conectan a top panel via keycap)
    └── LED ring ENC NAV (concentric al ENCNAV, visible por cutout anular)
```

---

## 1. Orden completo de montaje

Basado en §10 del master spec, expandido con pasos intermedios y criterios de go/no-go.

### Fase 0 — Preparacion de materiales (antes de ensamblar)

```
0.1  Imprimir PETG body (18-22h). Verificar todas las dimensiones criticas (§6 de 01-petg-body.md).
0.2  Imprimir display bracket en PETG (2-3h). Verificar fit con modulo ESP32-S3.
0.3  Cortar cheeks guadua (sierra de cinta): perfil 30→42mm × 100mm × 12mm.
0.4  Lijar cheeks: P120 → P240 → P400 en todas las caras.
0.5  Sellar cheeks con epoxico: aplicar 2 manos en todas las caras, incluyendo los cortes
     (especialmente los cortes de jacks que se haran despues). Dejar secar 48h.
0.6  Mandar a CNC el top panel de aluminio (mientras seca la guadua).
     Enviar archivo 02-top-panel.step + instrucciones del proveedor (ver §8 de 02-top-panel-aluminum.md).
0.7  Al recibir el aluminio CNC: verificar todas las dimensiones criticas (§6 de 02-top-panel-aluminum.md).
```

### Fase 1 — Instalacion de heat inserts en PETG body

```
1.1  Herramienta: soldador de temperatura regulada con punta para heat inserts (230-250°C).
1.2  Instalar 4 heat inserts M3 en pedestales del top panel (esquinas superiores del body).
     Insertar calentado lentamente hasta que queden flush con la superficie o 0.2mm bajo ella.
     Verificar: tornillo M3 debe entrar sin resistencia excesiva y sin wobble.
1.3  Instalar 6 heat inserts M3 en standoffs de PCB (suelo interno).
     Verificar: idem.
1.4  Instalar 2 heat inserts M3 en pared lateral izquierda (para cheek).
     ATENCION: los inserts en pared lateral van en orientacion horizontal — el soldador debe
     trabajar horizontalmente. Usar un soporte o hacer el body boca abajo.
1.5  Instalar 2 heat inserts M3 en pared lateral derecha.
1.6  Enfriar 30 minutos antes de continuar.
1.7  Verificar los 14 inserts: roscar y desroscar un tornillo en cada uno. Todos deben agarrar.
```

### Fase 2 — Montaje de PCB

```
2.1  Instalar componentes en la PCB si no estan instalados (encoders, botones, jacks laterales,
     potenciometro VOL — todos los componentes de panel van en la PCB antes de montarla).
2.2  Posicionar PCB sobre los 6 standoffs del PETG. Verificar que los shafts de encoders y
     el shaft del VOL alinean aproximadamente con las posiciones de cutout del top panel.
2.3  Atornillar PCB con 6 tornillos M3×8 SS. Apretar en patrón cruzado.
     Torque de apriete: aproximadamente 0.3 N·m (mano + un cuarto de vuelta con herramienta).
2.4  Conectar cables de sub-sistemas (si hay separacion en la PCB).
2.5  Conectar cable del modulo ESP32-S3 (dejar suelto — se monta despues del bracket).
```

### Fase 3 — Preparacion y montaje de cheeks guadua

```
3.1  ANTES de pegar: ensamblar los cheeks en los rebajes del PETG en seco (sin adhesivo).
     Verificar que asientan flush contra el body sin gaps visibles.
     Verificar que los heat inserts de los cheeks quedan alineados con los de las paredes del PETG.
3.2  Marcar la posicion de los cutouts de jacks usando un marcador a traves de los cutouts
     del PETG (los cutouts del PETG son la guia de taladrado).
3.3  Retirar los cheeks. Taladrar los cutouts en la guadua (usando las marcas de posicion):
     - TRS IN L, IN R, OUT L, OUT R: broca Forstner Ø11mm (o sierra copa)
     - 3.5mm AUX IN: broca comun Ø7.5mm
     - USB-C Power, USB-C Teensy: taladro multiple + lima (ver nota en 04-cheek-right-guadua.md §1)
     - USB-A Host: idem, con dimension 15.5mm × 8.5mm
3.4  Lijar el borde interior de los cutouts de guadua: lija P400 enrollada.
3.5  Aplicar Araldite estructural en el canal del rebaje del PETG (solo el fondo y los laterales
     del canal — NO en los bordes visibles donde el exceso de adhesivo mancharia el exterior).
3.6  Insertar el cheek izquierdo en el rebaje, presionando hasta asentar.
3.7  Atornillar 2 tornillos M3×16 desde el interior del PETG hacia los heat inserts del cheek.
     Apretar a mano primero, luego con llave hasta que el cheek este firme (sin sobreapriete —
     la guadua puede astillarse con exceso de torque).
3.8  Repetir 3.5-3.7 para el cheek derecho.
3.9  Dejar curar el Araldite: 24h minimo a temperatura ambiente (20-25°C Bogota).
     NO montar el top panel hasta que el adhesivo haya curado.
3.10 Instalar los jacks y conectores en los paneles laterales a traves de los cutouts
     (tuercas y arandelas en la cara exterior de la guadua).
```

### Fase 4 — Montaje del display bracket y modulo ESP32-S3

```
4.1  Pasar el cable del modulo ESP32-S3 por la ranura lateral del bracket antes de insertar
     el modulo en el bracket.
4.2  Insertar el modulo ESP32-S3 en la cavidad del bracket. Fijar con double-sided tape VHB
     en la base de la cavidad (bajo el modulo, no visible).
4.3  Conectar el cable del ESP32-S3 al conector correspondiente en la PCB.
4.4  Insertar el pie del bracket (Ø32mm) a traves del cutout del aluminio (Ø35mm).
     Centrar visualmente el display en el cutout.
     Fijar el flange del bracket a la cara superior del aluminio con double-sided tape VHB
     de alta resistencia (Ø de 35mm de area de contacto en el flange).
     ATENCION: el VHB cura por presion — aplicar presion uniforme durante 5 minutos.
     Una vez pegado, no es repositionable sin destruir el tape.
     ALTERNATIVA para prototipo: usar tape de doble cara standard (repositionable) hasta
     validar la posicion final del bracket.
```

### Fase 5 — Montaje del top panel de aluminio

```
5.1  Posicionar el top panel sobre el PETG body.
     Los 4 holes de tornillo del aluminio deben alinear con los 4 heat inserts del body.
     Los shafts de los encoders (ENC1, ENC2, ENC NAV) deben pasar por sus holes.
     El shaft del VOL debe pasar por su hole.
     Los keycaps de los 4 botones Choc V2 deben pasar por los cutouts de 14×14mm.
     Si el bracket ya esta montado: el bracket con el modulo ESP32-S3 sobresale del panel.
     RECOMENDACION: montar el bracket ANTES de colocar el top panel (ver orden de Fase 4 y 5).
     Alternativa: el pie del bracket se pasa por el cutout desde arriba del panel antes de pegar.
5.2  Verificar que el panel asienta flush sobre el PETG body en todos los bordes.
5.3  Atornillar 4 tornillos M3×6 SS countersunk en las esquinas.
     Los tornillos deben quedar flush o levemente bajo la superficie del aluminio (countersunk).
     Apretar en patron diagonal. Torque: 0.3-0.4 N·m (sin sobre-apretar en aluminio de 2mm).
5.4  Verificar que el panel no tiene gaps visibles con el PETG en ningún borde.
```

### Fase 6 — Instalacion de knobs y keycaps

```
6.1  Instalar knobs en los tres encoders:
     - ENC1 (CUTOFF): knob Ø18mm knurled, bajo perfil
     - ENC2 (RESONANCE): knob Ø18mm knurled, bajo perfil
     - ENC NAV (ACTION): knob Ø22mm liso, perfil alto
     Los knobs con D-shaft se aprietan con tornillo set (Allen 1.5mm generalmente).
     Posicion del set screw: alinear con el plano D del shaft para maximo agarre.
6.2  Instalar knob del VOL: Ø12mm "chicken head" o cylindrical.
6.3  Instalar keycaps en los 4 Kailh Choc V2.
6.4  Encender el instrumento y verificar que los LEDs de los keycaps funcionan.
6.5  Verificar el funcionamiento de los encoders (sin skip ni puntos muertos).
```

### Fase 7 — Patas silicona y cierre

```
7.1  Presionar las 4 patas de silicona Ø10mm en las cavidades de la base del PETG.
     Las patas deben quedar press-fit (Ø9.9mm de cavidad vs Ø10mm de pata).
     Si no hay presion suficiente: gotita de cianocrilato en la cavidad antes de insertar.
7.2  Test final:
     - El instrumento no se mueve sobre la mesa (patas hacen su funcion)
     - La altura frontal del instrumento con patas: BODY_H_F + PATA_H = 42+3 = 45mm
     - Todos los conectores accesibles desde afuera sin obstrucion
     - Todos los controles operables sin interferencia entre si
7.3  Documentar el numero de serie del prototipo (tira de papel bajo una de las patas
     o etiqueta interior en el compartimento).
```

---

## 2. Tabla de fijaciones consolidada

| Tipo | Cant. | Donde | Torque aprox. | Notas |
|---|---|---|---|---|
| Heat insert M3 latón | 14 | Body PETG: 6 PCB standoffs + 4 top panel pedestals + 2 cheek izq + 2 cheek der | — (calor) | 230-250°C; flush o 0.2mm bajo la superficie |
| Tornillo M3×8 SS (PCB) | 6 | PCB principal a standoffs PETG | 0.3 N·m | Patron cruzado |
| Tornillo M3×6 SS countersunk (top panel) | 4 | Top panel Al a body PETG | 0.3-0.4 N·m | Flush con superficie aluminio |
| Tornillo M3×16 SS (cheeks) | 4 | Cheeks guadua a body PETG (2 por cheek) | 0.2-0.3 N·m | No sobrecargar: astilla la guadua |
| Araldite estructural | — | Canal del rebaje PETG para cada cheek | — | 24h cura; no reposicionable |
| Double-sided tape VHB | — | Flange del bracket sobre top panel | 5 min presion | Asegurarse de centrar antes de aplicar |
| Double-sided tape VHB | — | Modulo ESP32-S3 en cavidad del bracket | — | |
| Patas silicona Ø10mm | 4 | Cavidades base PETG | — | Press-fit; gotica cianocrilato si flojo |
| Tuercas jacks TRS/3.5mm | 6 | Jacks en cheeks guadua (3 izq + 3 der en audio) | Mano | No sobrecargar |
| Tornillos set knobs | 3-4 | Knobs en shafts de encoders y VOL | Mano + 1/8 vuelta | Allen 1.5mm o 2mm segun knob |

---

## 3. Tolerancias de ensamblaje (gap entre piezas)

| Interfaz | Gap objetivo | Tolerancia | Notas |
|---|---|---|---|
| Aluminio top panel ↔ borde superior PETG | 0 mm (flush) o 0.1mm levemente elevado | ±0.2mm | Si el aluminio sobresale mas de 0.3mm, se siente al pasar el dedo |
| Cheek guadua ↔ PETG body (borde visible) | 0 mm (flush) con el rebaje de 6mm | ±0.3mm FDM | El adhesivo Araldite rellena gaps de hasta 0.5mm |
| Aluminio top panel ↔ cheek guadua (junta lateral) | 0.5-1.0 mm de gap visible | ±0.3mm | Gap intencional — feature de diseno. Si queda mayor a 1.5mm, se ve descuidado. |
| Pie del bracket ↔ cutout display aluminio | 1.5 mm por lado (clearance 3mm total) | ±0.3mm | El bracket se centra visualmente antes de fijar con VHB |
| Shaft encoder ↔ hole aluminio (Ø6.5mm vs Ø6mm shaft) | 0.25mm por lado | ±0.05mm (CNC) | El shaft debe girar libremente; si hay wobble, el CNC fue impreciso |
| Keycap Choc V2 ↔ cutout 14×14mm | 0.0-0.3mm por lado | ±0.1mm (CNC) | El keycap debe moverse verticalmente sin rozar el aluminio |

---

## 4. Issues conocidos y resoluciones

### D-08: LED ring vs display clearance

**Problema original (master spec v0.3):** Display en Y=57mm, ENC NAV en Y=30mm. Gap entre borde
inferior display y borde superior ring: 57-17.5-30-19 = -9.5mm (interferencia).

**Resolucion adoptada en los specs modulares:**
- Display movido a Y=60mm (de 57 a 60)
- ENC NAV movido a Y=22mm (de 30 a 22)
- Ring reducido a Ø32mm exterior (de Ø38mm)

**Verificacion post-resolucion:**
- Gap borde inferior display ↔ borde superior ring: 60-17.5-22-16 = 4.5mm. OK (>3mm minimo).
- El ENC NAV a Y=22mm esta a 22mm del borde trasero del panel. Con el borde del panel en Y=0
  y el rebaje del pogo trasero a 15mm de la base, no hay conflicto mecanico.
- El knob Ø22mm del ENC NAV a Y=22mm: borde trasero del knob = 22-11=11mm del borde trasero
  del panel. Clearance marginal pero funcional — la mano del usuario no necesita espacio detras del knob.

**Parametros actualizados en 00-master-parameters.md:**
- DISPLAY_Y: 60mm (era 57mm)
- ENCNAV_Y: 22mm (era 30mm)
- RING_EXT_D: 32mm (era 38mm)
- RING_INT_D: 24mm (era 28mm, ajustado proporcionalmente)

**Status: RESUELTO en los specs modulares. Pendiente validacion con modelo 3D.**

---

### D-10: USB-A Host muy cerca del borde frontal del cheek

**Problema original (master spec v0.3):** USB-A en Y=97mm (en coordenadas del cheek = Z=97mm
desde el fondo). Borde anterior del cutout: 97+7.5=104.5mm > 100mm. IMPOSIBLE.

**Primera iteracion de resolucion:** mover a Z=92mm → borde ant = 99.5mm → pared frontal = 0.5mm.
INSUFICIENTE para guadua.

**Analisis de la causa raiz:**
Los 5 puertos del cheek derecho necesitan mas espacio del disponible en 100mm si se requieren
clearances minimos de 3mm entre cutouts.

Espacio total necesario (calculado en 04-cheek-right-guadua.md §3):
- USB-C Power (10.5mm ancho, en Z=15mm): ocupa Z=9.75 a Z=20.25mm
- Gap minimo 3mm → siguiente empieza en Z=23.25mm
- TRS OUT L (Ø10.5mm, en Z=38mm): empieza en Z=32.75mm — gap=32.75-20.25=12.5mm OK
- TRS OUT R (Ø10.5mm, en Z=60mm): gap OK
- USB-C Teensy (10.5mm ancho, en Z=80mm): borde ant en Z=85.25mm
- Gap minimo 3mm → USB-A empieza en Z=88.25mm. Centro USB-A: 88.25+7.5=95.75mm.
  Borde anterior: 95.75+7.5=103.25mm. EXCEDE el largo de 100mm.

**Opciones arquitecturales:**

| Opcion | Descripcion | Pros | Contras |
|---|---|---|---|
| A | Reducir ancho USB-A de 15mm a 12mm | Cabe en Z=90mm | USB-A fisico mide ~12×5mm (tipo A): factible si el conector es fino |
| B | Mover USB-C Power al panel trasero PETG junto con el pogo | Libera 17mm en el cheek derecho | Rompe la convencion LEFT=IN, RIGHT=OUT. USB-C poder en el trasero es estandar en muchos sintetizadores. |
| C | Mover USB-C Teensy al panel trasero | Idem | El USB-C de Teensy es el de uso frecuente (flashing) — en el trasero es menos accesible |
| D | Usar cheeks de 120mm de profundidad en vez de 100mm | Todo cabe con clearances | Rompe la dimension BODY_D=100mm y cambia el total |
| E | Eliminar USB-C Power (alimentar solo por USB-C Teensy) | 5 puertos → 4 puertos, todo cabe | La dualidad power/data en el mismo conector puede complicar el circuito de power |

**Recomendacion:**
Opcion B (USB-C Power al trasero). Justificacion: en la mayoria de sintetizadores de estudio,
el power va en el panel trasero (Moog Sub25, Roland SE-02, Arturia MiniLab). El usuario conecta
el power una vez y lo deja. El frente derecho queda para los conectores de uso frecuente.

Con Opcion B, el cheek derecho tiene 4 puertos:
- TRS OUT L: Z=30mm
- TRS OUT R: Z=52mm
- USB-C Teensy: Z=68mm
- USB-A Host: Z=83mm → borde ant = 90.5mm → clearance frontal = 9.5mm. OK.

El panel trasero PETG tendria: Pogo (centro, X=90) + USB-C Power (X=30 o X=150).

**Status: PENDIENTE decision del hardware engineer (afecta circuito de power y pin mapping).**
Los specs modulares documentan la version con los 5 puertos como "provisional D-10" hasta
que el hardware engineer confirme si Opcion B es viable electricamente.

---

### Gap identificado: base del PETG body (abierta o con tapa)

El spec maestro v0.3 no especifica si la base del PETG body tiene tapa removible o es
permanentemente cerrada (solo con patas de silicona).

Con la base cerrada (solida, sin apertura), el acceso a la electronica interna es imposible
sin desatornillar el top panel. Esto es aceptable para un instrumento de produccion (como el OP-1)
pero dificil para el prototipo donde el desarrollo firmware requiere acceso frecuente al interior.

**Recomendacion para prototipo v0.2:** base abierta (base del PETG es solo el suelo con los
standoffs — sin tapa). La tension y el LiPo (en versiones futuras) quedan accesibles desde abajo.
Las patas de silicona elevan el instrumento 3mm (PATA_H) para que nada toque la mesa.

**Para produccion v1.0:** evaluar tapa de base con clips o tornillos — o mantener la base
abierta si el instrumento se usa siempre sobre mesa.

---

## 5. Procedimiento de troubleshooting si una pieza no encaja

### Top panel no asienta flush sobre PETG

1. Verificar que los 4 pedestales de heat inserts esten a la misma altura (calibre de profundidad)
2. Verificar que no hay material PETG sobrante en la zona de asiento del panel (lija P400)
3. Verificar que los knobs y shafts de encoders no esten obstruyendo (los shafts deben pasar por los holes antes de bajar el panel)
4. Verificar que los keycaps no esten bloqueando el panel (presionar los botones hacia abajo mientras se asienta el panel)

### Cheek no asienta en el rebaje PETG

1. Medir el ancho del rebaje con calibre (debe ser CHEEK_REBAJE_D=6mm ±0.3mm)
2. Medir el espesor del borde del cheek que entra en el rebaje (debe ser ≤ 6mm)
3. Si el cheek FDM del PETG tiene undersize: lijar el fondo del canal con lija envuelta en un bloque
4. Si la guadua tiene oversize: lijar la cara interior del cheek (la que entra en el canal)
5. El clearance de 0.2mm es suficiente para insertar sin fuerza excesiva — si requiere golpes, hay interferencia

### Shaft de encoder no pasa por el hole del aluminio

1. Verificar el diametro del hole (debe ser ENC_HOLE=6.5mm)
2. Verificar que el shaft EC11 es D-shaft de 6mm (algunos EC11 tienen shaft redondo de 6.35mm)
3. Si el hole es correcto (6.5mm) y el shaft D no pasa: el anodizado dejo una capa gruesa. Ampliar el hole 0.1mm con una lima de aguja circular.
4. Si el shaft redondo de 6.35mm no pasa por 6.5mm: el CNC fue impreciso. Pedir re-trabajo.

### Display bracket no queda centrado en el cutout

1. El bracket tiene 1.5mm de clearance por lado (Ø32mm vs Ø35mm) — puede desplazarse.
2. Antes de pegar el VHB: centrar el display mirando desde arriba que el gap sea uniforme en todo el perimetro.
3. Una vez centrado, aplicar presion uniforme durante 5 minutos para que el VHB agarre.
4. Si el bracket queda off-center >1mm visiblemente: el VHB no curo aun (primeras horas) — usar espatula de plastico para levantar y reposicionar.

### LED ring no es visible a traves del cutout anular

1. Verificar que el cutout anular (Ø32mm ext / Ø24mm int) fue cortado correctamente por el CNC.
2. Verificar que la PCB del ring esta a la altura correcta debajo del aluminio (la altura de los LEDs debe ser menor que PANEL_T=2mm del aluminio).
3. Verificar que los LEDs del ring estan encendidos (firmware).
4. La ventana anular de 4mm de ancho (radio ext - radio int = 16-12=4mm) es pequeña — el efecto visual es una franja de luz circular. Si el grosor del ring no es suficiente para ver los LEDs, puede necesitarse ampliar el cutout exterior (aumentar RING_EXT_D).

---

## 6. Verificacion de ensamblaje completo

| Check | Metodo | Criterio pass |
|---|---|---|
| Dimension total 204×100mm | Calibre exterior (incluyendo cheeks) | 204mm ±1mm en X, 100mm ±0.5mm en Z |
| Altura frontal con patas | Calibre desde mesa hasta top del aluminio frontal | 42+3+2=47mm ±1mm |
| Planitud del top panel | Regla de metal | Sin deflexion perceptible al aplicar fuerza de 10N en el centro |
| Torque de encoders | Girar cada encoder | Giro suave sin puntos duros; click del switch audible |
| Actuation de botones | Presionar cada boton Choc V2 | Click audible y tactil; el keycap regresa completamente |
| Iluminacion keycaps | Encender firmware | Todos los keycaps iluminados uniformemente en teal |
| LED ring ENC NAV | Encender firmware | Ring visible y uniforme a traves del cutout anular |
| Display GC9A01 | Encender firmware | Display visible y legible desde angulo de uso (frente inclinado ~7 grados) |
| Audio OUT | Conectar 1/4" TRS a amplificador | Señal sin ruido de fondo excesivo; sin crackles de conexion mecanica deficiente |
| USB-C Teensy | Conectar cable USB-C | Conexion fisica firme; el host reconoce el dispositivo |
| USB-A Host | Conectar teclado MIDI USB | El host reconoce el dispositivo MIDI |
| Pogo connector | Conectar accesorio modular (cuando disponible) | 6 pins conectan sin fuerza excesiva |
| Rigidez mecanica general | Aplicar fuerza de 20N en 4 esquinas del instrumento | Sin crujidos; sin deflexion visible en el top panel |

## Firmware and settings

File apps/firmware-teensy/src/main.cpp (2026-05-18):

/**
 * @file main.cpp
 * @brief GrooveForge Brain — Teensy 4.1 firmware entry point.
 *
 * Sprint 3.3: UI subsystem (encoders, buttons, LEDs) integrated.
 * Audio engines and FX are compiled but not instantiated here yet —
 * engine selection and audio graph wiring are Sprint 4.x scope.
 *
 * Refs: apps/docs/01-architecture.md §3.3 — pin mapping
 *       apps/docs/sprints/20-encoders-buttons.md — UI theory + wiring table
 */

#include <Arduino.h>
#include "ui/encoders.h"
#include "ui/buttons.h"
#include "ui/leds.h"
#include "ui/ui_manager.h"

// ── Pin 25: CD4066 filter bypass control (01-architecture.md §3.3) ──────────
static constexpr uint8_t PIN_FILTER_BYPASS = 25;

// ── UI subsystem instances ───────────────────────────────────────────────────
static Encoders    g_encoders;
static Buttons     g_buttons;
static Leds        g_leds;
static UIManager   g_ui;

// ── Filter bypass state ──────────────────────────────────────────────────────
static bool g_filter_bypassed = false;

// ── Application-level callbacks ─────────────────────────────────────────────

static void on_param_changed(uint8_t param_id, float delta) {
    // TODO Sprint 4.x: route to active engine
    // For now: reflect cutoff/resonance changes on serial for debugging.
    if (param_id == PARAM_CUTOFF) {
        Serial.printf("[UI] cutoff delta=%.2f\n", delta);
    } else if (param_id == PARAM_RESONANCE) {
        Serial.printf("[UI] resonance delta=%.2f\n", delta);
    }
}

static void on_button(uint8_t btn_idx) {
    switch (btn_idx) {
        case 0: Serial.println("[UI] B1 pressed"); break;
        case 1: Serial.println("[UI] B2 pressed"); break;
        case 2: Serial.println("[UI] B3 pressed"); break;
        case 3: Serial.println("[UI] B4 pressed"); break;
        case BTN_CONFIRM:
            Serial.println("[UI] ENC NAV confirm");
            break;
        case BTN_MODE_SWITCH:
            Serial.println("[UI] mode switch");
            // Toggle ring color between synth (teal) and FX (purple) modes.
            static bool fx_mode = false;
            fx_mode = !fx_mode;
            if (fx_mode) {
                g_leds.set_all(CRGB(0x53, 0x4A, 0xB7));  // #534AB7 purple
            } else {
                g_leds.set_all(CRGB(0x1D, 0x9E, 0x75));  // #1D9E75 teal
            }
            g_leds.show();
            break;
        case 6:  // BTN_FILTER_BYPASS (ENC L push → CD4066 toggle)
            g_filter_bypassed = !g_filter_bypassed;
            digitalWrite(PIN_FILTER_BYPASS, g_filter_bypassed ? HIGH : LOW);
            Serial.printf("[UI] filter bypass=%s\n", g_filter_bypassed ? "ON" : "OFF");
            break;
        case 7:  // BTN_RESONANCE_RESET (ENC R push)
            Serial.println("[UI] resonance reset to 0");
            // TODO Sprint 4.x: g_engine.setFilterResonance(0.0f);
            break;
        default:
            break;
    }
}

static void on_nav(int32_t delta) {
    Serial.printf("[UI] nav delta=%d\n", delta);
    // TODO Sprint 4.x: update active menu position and refresh display via Bridge.
}

// ── Arduino entry points ─────────────────────────────────────────────────────

void setup() {
    Serial.begin(115200);

    // CD4066 filter bypass: start with filter active (LOW = filter in circuit).
    pinMode(PIN_FILTER_BYPASS, OUTPUT);
    digitalWrite(PIN_FILTER_BYPASS, LOW);

    g_encoders.init();
    g_buttons.init();
    g_leds.init();

    g_ui.init(&g_encoders, &g_buttons, &g_leds);
    g_ui.on_param_changed(on_param_changed);
    g_ui.on_button(on_button);
    g_ui.on_nav(on_nav);

    // Boot indication: brief teal pulse on ring.
    g_leds.set_all(CRGB(0x1D, 0x9E, 0x75));
    g_leds.show();
    delay(300);
    g_leds.clear();

    Serial.println("[BOOT] GrooveForge Brain — Sprint 3.3 UI ready");
}

void loop() {
    g_ui.update();
}

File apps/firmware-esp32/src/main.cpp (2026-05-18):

/**
 * @file main.cpp
 * @brief Entry point — GrooveForge Brain ESP32-S3
 *
 * Sprint 3.4: 23 vistas de UI en modo carrusel (una cada 5s, bucle infinito).
 *
 * Secuencia de boot:
 *   setup() → lv_port_disp_init() → screen_boot_create()
 *   loop()  → lv_task_handler() + lv_tick_inc(5)
 *           → screen_boot_done()? → carousel_start()
 *
 * El boot anima una sola vez; despues el carrusel toma el control y cicla las
 * 23 vistas indefinidamente. Ver apps/docs/sprints/18-display-ui-carousel.md.
 *
 * Nota sobre el tick: lv_conf.h tiene LV_TICK_CUSTOM=0, por eso loop() llama
 * lv_tick_inc(5) manualmente (patron validado de groove_drum).
 */

#include <Arduino.h>
#include <lvgl.h>
#include "display/lv_port_disp.h"
#include "display/screens/screen_boot.h"
#include "display/carousel/carousel.h"
#include "bridge/bridge_slave.h"
#include "bridge/bridge_handlers.h"

static bool        s_carousel_started = false;
static BridgeSlave s_bridge;

void setup() {
    Serial.begin(115200);
    /* 2s para que el USB CDC enumere antes de los primeros prints. */
    delay(2000);

    Serial.println("=== GrooveForge Brain — ESP32-S3 ==="); Serial.flush();
    Serial.println("Sprint 3.4 | Display UI carousel | 23 views | LVGL 8.x");

    /* Bridge Protocol UART slave — init antes del display para que los logs
     * de bridge aparezcan en orden cronológico en el monitor serial. */
    bridge_handlers_init(s_bridge);
    s_bridge.init();

    /* LVGL + driver GC9A01 + buffers de rendering */
    lv_port_disp_init();

    /* Pantalla de boot animada (corre una sola vez) */
    screen_boot_create();
    Serial.println("Boot screen active — animating...");
}

void loop() {
    /* lv_task_handler() procesa animaciones, invalidaciones, timers y eventos.
     * lv_tick_inc(5) avanza el reloj interno de LVGL (LV_TICK_CUSTOM=0). */
    /* Bridge poll: procesa bytes UART disponibles sin bloquear el loop */
    s_bridge.poll();

    lv_task_handler();
    lv_tick_inc(5);

    /* Transicion boot → carrusel: una sola vez al terminar la animacion. */
    if (!s_carousel_started && screen_boot_done()) {
        s_carousel_started = true;
        lv_obj_clean(lv_scr_act());
        carousel_start();
        Serial.println("Boot done — carousel active");
    }

    delay(5);
}

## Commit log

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2026-05-17 Sprint 1.3 — Matching Jig: jig Vbe funcional, matching pendiente protocolo térmico
    - Jig ADC: Teensy A0 (pin 14) + resistor 20kΩ → ~134µA, resolución efectiva ~0.1mV
    - Protocolo correcto descubierto: manipular por patas, esperar 5s tras insertar
    - Sprint 1.4 (filter ladder) diferido como technical debt — TL072/CD4066 pendientes
    - Spec fixes: A0 corregido a pin 14 (era 24), TPDT eliminado del diseño (bypass 100% GUI)
    - Roadmap: Sprint 1.4 marcado DEFERRED, avance a Sprint 1.5 sin filter físico
2026-05-17 Sprint 1.5 — Moog Model D Skeleton: primer engine C++ completo
    - MoogModelD clase: 3 VCO + noise + mixer + digital filter (placeholder) + 2 envelopes + glide
    - Filter envelope en software (ATTACK/DECAY/SUSTAIN/RELEASE) modula AudioFilterStateVariable
    - Glide: interpolación lineal en Hz desde loop(), configurable 0–2000ms
    - noteOn(midi_note) / noteOff() + 6 comandos Serial para control en runtime
    - AudioMemory(20), CPU estimado <5% para 1 voz
    - TODO Sprint 1.4: reemplazar digital filter con routing via SGTL5000 ADC → ladder analógico
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2026-05-17 Sprint 2.4 — FX Phase Chorus: CE-2 inspired, LFO drift caótico, pre-sat tanh
    [phase_chorus.h]
2026-05-17 Sprint 2.4 — Done: CPU 1.1%, 7 bloques, clamp fix + learnings AudioEffectChorus
2026-05-17 Sprint 2.5 — FX Bit Sculpt: bitcrusher + dither RPDF/TPDF/noise-shaping + sample rate
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2026-05-17 Sprint 2.7 — Done: CPU 1.2%, 5/11 bloques, campana/guadua/cristal/madera verificados
    Fix bug: _modeLevel[] decaía continuamente aunque el chord estuviera sostenido.
    _applyMaterial() no reseteaba levels antes de updateMixerGains(), entonces
    los comandos t/z/e actualizaban coeficientes biquad pero las ganancias de
    los mixers quedaban en ~0 (valores ya decaídos) → sin cambio audible.
    Dos fixes:
    1. _applyMaterial(): reset _modeLevel[i] = 1.0f por modo antes de computar gains.
    2. update(): v1.0 simplificación — mantiene levels en 1.0f siempre (chord sostenido,
    input continuo). Infraestructura _modeDecayFactor[] lista para v2.0 con onset detection.
    Resultados hardware:
    - CPU: 1.2% (b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
2026-05-17 Docs + fix Cymatic BASE_FREQ y Granular API — Sprints 2.8-2.11
    Docs actualizados:
    - 06-implementation-roadmap.md: sprints 2.1-2.7 marcados done, 2.8-2.11 agregados
    - 05-fx-architecture.md: §4 Roadmap con FX completados y pendientes
    - Sprint docs 13-16: theory de Cymatic/Granular/Spring+Plate/Ghost Echo
    Fix Cymatic Resonator:
    - BASE_FREQ 440Hz→261.63Hz (C4) — alinea modos con chord C mayor del demo
    - Con tune=1.0 los modos caen en 261/523/784/1308Hz, resonando con C4+E4+G4
    - El bypass toggle ahora es claramente audible
    Fix Granular Cloud:
    - AudioEffectGranular.startPlayback() no existe en Teensy Audio Library
    - Reemplazado por beginPitchShift(grain_samples) en begin() y en setFreeze(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
2026-05-17 Sprint 2.8-2.11 — sketch combinado 17-fx-all + fix Granular API
    17-fx-all.cpp: sketch único para los 4 FX nuevos via #define ACTIVE_FX N.
    Cambiar el número (1-4) y reflashear — no tocar platformio.ini nunca más.
    Razón del #define en lugar de runtime-switch: AudioOutputI2S es singleton
    en Teensy Audio Library — dos instancias en memoria crashean el DMA.
    La selección en tiempo de compilación es la única solución limpia.
    platformio.ini: incluye los 4 FX .cpp en build_src_filter, el linker
    incluye solo las clases referenciadas por el #define activo.
2026-05-17 Fase 2 FX — Done: 9 signature FX verificados en hardware
    Sprints 2.3–2.11 completos. Métricas finales en Teensy 4.1:
    Sprint 2.3 Tape Saturate — CPU ~3% verificado
    Sprint 2.4 Phase Chorus — CPU 1.1% Mem 7 bl
    Sprint 2.5 Bit Sculpt — CPU 0.6% Mem 7 bl
    Sprint 2.6 Sub Genesis — CPU 0.8% Mem 9 bl
    Sprint 2.7 Modal Reverb — CPU 1.2% Mem 5/11 bl
    Sprint 2.8 Cymatic Res. — CPU ~2% verificado
    Sprint 2.9 Granular Cloud — CPU 0.5% Mem 5 bl
    Sprint 2.10 Spring + Plate — CPU 5.1% Mem 5 bl
    Sprint 2.11 Ghost Echo — CPU 0.2% Mem 29/30 bl
    También incluye fixes de Tape Saturate (Sprint 2.3) que faltaban comm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
2026-05-17 fix(esp32): default_envs=esp32s3 — native no compila en pio run
    pio run sin args intentaba compilar el env native con headers de
    Arduino.h/lvgl.h → error de compilación. default_envs limita pio run
    a esp32s3; native queda exclusivo para pio test -e native.
2026-05-17 fix(esp32): replace TFT_eSPI with LovyanGFX to fix StoreProhibited crash
    TFT_eSPI 2.5.x crashes on Arduino ESP32 v3.x (IDF 5.x) because
    spiStartBus() leaves spi->dev = NULL in IDF5; first SPI register
    write touches NULL+0x10 → StoreProhibited at EXCVADDR 0x00000010.
    LovyanGFX uses the IDF5 SPI API directly, avoiding the broken
    spi_t->dev path entirely. Also fixes arc animation (0→360 via
    lv_arc_set_value instead of end_angle > 360) and adds 2s USB CDC
    delay for serial output capture.
    [lv_port_disp.cpp, main.cpp]
2026-05-17 fix(esp32): revert to TFT_eSPI with USER_SETUP_LOADED — fix root crash cause
    La causa real del StoreProhibited no era incompatibilidad con IDF5 sino
    falta de USER_SETUP_LOADED=1: sin ese flag TFT_eSPI carga User_Setup.h
    con pines incorrectos → spiStartBus() recibe bus_num invalido → spi->dev=NULL
    → write a NULL+0x10. Con USER_SETUP_LOADED+GC9A01_DRIVER+USE_HSPI_PORT
    TFT_eSPI inicializa SPI2 correctamente (validado en groove_drum, mismo HW).
    También: ARDUINO_USB_CDC_ON_BOOT=0 para salida Serial por UART0 sin
    depender de enumeración USB CDC.
    [lv_port_disp.cpp]
2026-05-17 fix(esp32): SPI.begin() pre-init antes de TFT_eSPI — fix definitivo StoreProhibited
    En ESP32-S3, HSPI no tiene default pins. TFT_eSPI con USE_HSPI_PORT=1
    llama spiStartBus() y recibe spi->dev==NULL → StoreProhibited @ 0x10.
    Fix: SPI.begin(TFT_SCLK,-1,TFT_MOSI,-1) antes de tft->init() fuerza
    la asignacion de pines al bus HSPI antes de que TFT_eSPI lo toque.
    Patron extraído de groove_drum (mismo hardware Waveshare GC9A01).
    También: tft->setSwapBytes(true) para colores RGB565 correctos,
    backlight explícito vía pinMode/digitalWrite(TFT_BL, HIGH).
    [lv_port_disp.cpp]
2026-05-17 fix(esp32): quitar USE_HSPI_PORT — TFT_eSPI debe usar SPI2 (mismo bus que pre-init)
    En ESP32-S3: SPI (default Arduino) = SPI2/FSPI. Con USE_HSPI_PORT=1,
    TFT_eSPI crea SPIClass(HSPI) = SPI3, bus diferente al que pre-inicializamos.
    Resultado: pixels van al bus incorrecto → sin imagen aunque no hay crash.
    Sin USE_HSPI_PORT, TFT_eSPI usa el mismo SPI2 que SPI.begin() pre-configuró
    con SCLK=10/MOSI=11. También activamos BL en GPIO2 y GPIO40 para cubrir
    ambas variantes del hardware.
    [lv_port_disp.cpp]
2026-05-17 fix(esp32): restaurar USE_HSPI_PORT=1 — replicar config exacta de groove_drum
    Sin USE_HSPI_PORT=1 TFT_eSPI usa un bus SPI incorrecto en ESP32-S3 y crashea.
    Con USE_HSPI_PORT=1 + SPI.begin() pre-init no hay crash.
    El backlight ahora se activa en GPIO2 Y GPIO40 para cubrir ambas variantes HW.
2026-05-18 feat(sprint-3.1-3.2): Bridge Protocol UART Teensy↔ESP32 + display learnings
    Sprint 3.1 (CERRADO): documenta los learnings reales del display GC9A01 —
    TFT_RST=14 root cause, SPI.begin() pre-init, espressif32@6.9.0, huge_app.csv.
    Sprint 3.2 (CERRADO): implementa el protocolo binario UART 921600 baud entre
    Teensy (master) y ESP32-S3 (slave). Incluye:
    - apps/bridge-protocol/include/protocol.h — header compartido C/C++, CRC-8 poly 0x07
    - BridgeSlave: state machine byte-a-byte, ACK/NACK, heartbeat watchdog 3s
    - bridge_handlers: ENGINE_CHANGED, PARAM_CHANGED, VERSION, HEARTBEAT
    - 30 tests nativos (pio test -e native) — test_crc8, serialization, error_handling
    - tools/bridge-test/send_frame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
    [bridge_handlers.cpp, bridge_slave.cpp, main.cpp]
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2026-05-18 feat(sprint-4.3): Key Detection Model — 24 tonalidades, 94.1% accuracy, 19KB int8
    Modelo Dense(12→128→64→24) entrenado sobre perfiles Krumhansl-Schmuckler.
    Entrada: pitch class histogram 12 floats. Salida: 24 clases (12 mayor + 12 menor).
    Hallazgo clave: noise_level=0.02 crítico — con 0.1 la accuracy colapsaba a 15%
    porque los perfiles de C_maj y Am (r=0.65) se vuelven indistinguibles bajo ruido alto.
    - Float32 accuracy: 94.1% · Int8 accuracy: 93.6% · Delta: 0.4% (<<5% límite)
    - Tamaño int8: 19.4 KB de 500KB budget · Tensor arena: ~16 KB de 200KB budget
    - key_detector.h/.cpp: clase Teensy con TFLite Micro (ops: FullyConnected+Softmax+ReLU)
    - key_detector_model.h: C array au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
2026-05-18 feat(sprint-4.5): Beat Follower Model — BPM detection, 86.4% exacto, 99.7% ±1 clase
    Modelo híbrido: histograma de IOIs (32 bins, 50-2000ms) → Dense(32→64→32→32) → 32 BPM classes.
    IOI = Inter-Onset Interval. on_onset(millis()) acumula timestamps en buffer circular.
    Jitter gaussiano σ=15ms en dataset para simular timing humano real.
    Hallazgo: la ambigüedad double-time/half-time (120↔60 BPM) esperada teóricamente
    NO aparece en confusiones reales — el modelo la resuelve solo por distribución IOIs.
    Errores reales son todos entre BPMs adyacentes (±1 clase ≈ ±3-5 BPM).
    - Float32 accuracy exacta: 86.4% · ±1 clase: 99.7% (perceptualmente perfecto)
    - Delta float→int8: 0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
    [beat_follower.cpp]
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2026-05-18 feat(training): entrenar 3 modelos ML con datos sintéticos — modelos reales en firmware
    Key Detector: 95.0% → 94.5% int8 (+0.5%), 19.4 KB
    Chord Recognizer: 100% → 98.6% int8 (+1.4%), 23.0 KB (fix noise 0.05→0.02)
    Beat Follower: 86.5% → 86.0% int8 (+0.5%), 11.0 KB
    Total flash: 53.4 KB / 500 KB budget (89% libre)
    Fix chord_recognizer/train.py: noise_level hardcodeado en 0.05 destruía
    separabilidad entre clases que difieren en 1 semitono (C_7 vs C_maj7).
    Reducido a 0.02 + n_train 15K→30K + n_val 3K→6K + epochs 80→150.
    Accuracy subió de 19% a 100% float32.
    Los _model.h en src/ml/ están listos para pio run -e sketch22.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
2026-05-19 feat(sprint-5.3): Scale Lock — never play a wrong note, feature AI Tier S
    KeyDetector detecta tonalidad cada 500ms → ScaleLock cuantiza cada NoteOn
    al semitono más cercano en la escala activa → MoogModelD sintetiza la nota
    corregida. El usuario toca libremente y todo suena en la tonalidad correcta.
    ScaleLock (src/ml/scale_lock.h/.cpp):
    - Tabla de 7 intervalos mayor [0,2,4,5,7,9,11] y menor [0,2,3,5,7,8,10]
    - snap() bidireccional: busca ±delta hasta encontrar nota en escala
    - Histéresis de confianza: solo actualiza escala si confidence >= 0.75
    - Bypass vía CC MIDI 64 (Sustain Pedal): toggle pass-through
    - Sesgo leading-tone en empate: prefiere la nota más alta
    Sketch 24 (24-scale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
2026-05-19 docs(integration): Sprint intermedio — guía de integración hardware
    Documento de campo para conectar físicamente todos los componentes:
    Etapa 1: Encoders ALPS EC11 (GPIO 10-17, 26) + Botones Kailh (GPIO 2-5)
    + LEDs WS2812B (GPIO 28) → Teensy 4.1
    Etapa 2: Bridge Protocol UART 921600 baud — Teensy pin 0/1 ↔ ESP32 GPIO 44/43
    Verificación: send_frame.py → ESP32 → ENGINE_CHANGED en Serial
    Etapa 3: MIDI Host USB-A → Sketch 21 (básico) o Sketch 24 (Scale Lock)
    Incluye: tabla de cableado exhaustiva con colores, diagramas ASCII del EC11,
    problemas comunes con síntomas y solución, notas de seguridad eléctrica,
    tabla de orden de integración paso a paso con crit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
2026-05-19 docs(filter+arch): corrige control de resonancia y scope del filtro analógico
    - 03-filter-design.md §3.2: elimina resonance pot del BOM (ya eliminado en 01-arch)
    - 03-filter-design.md §6.1: filtro analógico exclusivo de Moog Model D; todos los
    demás engines (Juno-106, Prophet-5, OB-6, DX7, ARP 2600) tienen bypass por default
    - 03-filter-design.md §6.2: resonance controlada por ENC R (digital, pin 14/15),
    no por pot físico — único pot en el panel es el volumen
    - 03-filter-design.md §6.3: simplifica interacción digital↔analógico — solo aplica
    a MoogModelD; bypass digital cuando analógico activo (evita 8-pole 48dB/oct)
    - 01-architecture.md §2.1: corrige "5 engines" →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
2026-05-19 feat(sketch26): agrega feedback visual WS2812B completo al test de UI
    - ENC L giro → LED ring posición Teal proporcional al total
    - ENC R giro → ring brillo Teal proporcional a resonancia
    - ENC NAV → ring sweep Purple por detent
    - ENC L push → flash Blanco 200ms (filter bypass)
    - ENC R push → flash Rojo 200ms + reset total_r (resonance reset)
    - ENC NAV push→ flash Verde 200ms (confirm)
    - B1-B4 press → keycap Naranja 150ms
    - B1-B4 held → keycap Rojo mientras se mantiene
    - Idle → pulso suave Teal ~3.5Hz en el ring
    - Startup → sweep Teal + underglow Naranja para verificar todos los LEDs
    68KB flash / 13KB RAM1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
2026-05-19 fix(encoders): corrige pérdida de pulsos parciales + raw debug en sketch26
    Bug: readAndReset() descartaba pulsos sub-detent entre ciclos (raw=2 → 2/4=0
    perdido para siempre). Fix: tracking de posición absoluta, consume solo
    detents completos, acumula parciales entre loop() cycles.
    Debug: sketch26 imprime totales cada 2s — si no cambian al girar es problema
    de cableado (pin COM/GND del encoder no conectado a GND).
2026-05-19 fix(sketch26): ring solo para ENC NAV, idle tenue estático
    - ENC L / ENC R: sin feedback en ring (knob físico es el feedback)
    - ENC NAV: ring sweep Purple en posición del detent; resto tenue Teal
    - Idle: glow estático ~8% brillo Teal (modo Synth), no pulsante
    - Ring "despierta" a brillo completo al girar ENC NAV
    - SW pushes de cualquier encoder sí hacen flash en ring (Blanco/Rojo/Verde)
    - Elimina función ring_brightness_from_total (ya no usada)
2026-05-19 feat(bridge): implementa BridgeMaster Teensy + sketch27 UART test
    BridgeMaster (bridge_master.h/.cpp):
    - State machine RxState idéntica a BridgeSlave — simetría de parsing
    - send_and_wait(): loop tight con yield() hasta ACK o timeout 100ms
    - send_async(): fire-and-forget para HEARTBEAT y ENGINE_CHANGED
    - Handler interno GF_CMD_ACK actualiza _esp32_alive + _last_hb_ack_ms
    - Watchdog poll(): >3s sin ACK → _esp32_alive=false + log [master] ESP32 DOWN
    - Serial1 pins 0/1 fijos en Teensy (921600 8N1)
    sketch27 (UART bridge test):
    - IntervalTimer 1s → send_heartbeat() via flag volatile (safe desde ISR)
    - ENC NAV gira → ENGINE_CHANGED(id=0-5, nombre del engine)
    - ENC NAV push → send_and_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
    [bridge_master.cpp]
2026-05-19 fix(esp32-bridge): activa USB CDC para liberar GPIO43/44 al bridge UART
    Raíz del problema: ARDUINO_USB_CDC_ON_BOOT=0 hacía que Serial=UART0=GPIO43/44
    (via ESP32-S3 JTAG bridge interno). Serial1.begin() en esos pines conflictuaba
    silenciosamente → firmware colgado después de "[bridge] handlers registered".
    Fix:
    - platformio.ini: USB_MODE=1 + CDC_ON_BOOT=1 → Serial=USB CDC nativo, GPIO43/44 libres
    - bridge_slave.cpp: Serial1.begin(921600, SERIAL_8N1, 44, 43) ahora funciona
    - Agrega comentario explicativo del requisito CDC en bridge_slave.cpp
    [bridge_slave.cpp]
2026-05-19 fix(esp32-bridge): corrige pines UART a GPIO17(TX)/GPIO18(RX) Waveshare
    GPIO43/44 = UART0/Serial debug — no disponibles para bridge en este módulo.
    GPIO17/18 son los pines UART libres en Waveshare ESP32-S3-Touch-LCD-1.28.
    Revierte USB CDC (no necesario). Actualiza 01-architecture.md §3.3.
    Cableado:
    ESP32 GPIO17 (TX) → Teensy pin 0 (RX)
    ESP32 GPIO18 (RX) ← Teensy pin 1 (TX)
    GND común obligatorio
    [bridge_slave.cpp]
2026-05-19 fix(esp32-bridge): pines UART bridge GPIO16(RX)/GPIO17(TX) Waveshare
    Pines correctos del conector Waveshare ESP32-S3-Touch-LCD-1.28.
    Cableado definitivo:
    ESP32 GPIO16 (RX) ← Teensy pin 1 (TX)
    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
    [bridge_slave.cpp]
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2026-05-27 feat(design): add enclosure 3D scripts + PETG body STEP/STL
    Fusion 360 Python scripts para todas las partes del enclosure (v0.7):
    - 01-petg-body: cuerpo PETG 180×100×38mm rectangular, shell 3mm,
    pedestales, rebajes guadua, ranura Pogo, pies de goma (bugs fijos:
    pedestals multi-body, rebajes via NewBody+Combine, jacks en cheeks)
    - 02-top-panel: aluminio 2mm, cutouts botones/encoders/display/jacks
    - 03-cheek-left: guadua 12mm, jack cutouts TRS IN L/R + AUX
    - 04-cheek-right: guadua 12mm, jack TRS OUT + USB-C data/host
    - 05-display-bracket: bracket PETG pie Ø32mm + flange 40×40mm,
    cavidad ESP32-S3 Waveshare 25.9×25.9mm, ranura cable FPC
    Exports: 01-petg-body.step/.stl para fabricaci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
    [01-petg-body.f3d, 01-petg-body.step, 01-petg-body.stl]
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2026-05-27 fix(esp32-bridge): MODE SWITCH → ENGINE LIST + HOME mode-aware routing
    Bug 1 — 0xFD (FX/SYNTH switch): al entrar a SYNTH mode el handler iba a
    VIEW_IDX_SYNTH_MAIN (arcos cutoff/resonance). Corregido a ENGINE_LIST para
    que el usuario seleccione engine antes de editar parámetros, consistente con
    el handler directo 0x00F4.
    Bug 2 — 0xFA (HOME): siempre iba a FX_SELECT sin revisar s_top_mode.
    Ahora es mode-aware:
    FX mode → VIEW_IDX_FX_SELECT (RMX B.SELECT equivalente)
    SYNTH mode→ VIEW_IDX_ENGINE_LIST (menú principal de SYNTH)
    [bridge_handlers.cpp]
2026-05-27 fix(design): corrige recolección de cuerpos del pedestal PETG
    feat_ped.bodies.item(0) solo recogía 1 de 4 cuerpos del pedestal.
    Ahora itera feat_ped.bodies.count para unir todos los sólidos correctamente
    y eliminar los cilindros flotantes del modelo de enclosure.
2026-05-27 fix(teensy-sk27): SYNTH mode navigation — encoders + buttons
    - Agrega rama SYNTH completa en handle_encoders() con 3 niveles:
    • Nivel 0 (ENGINE_LIST): ENC NAV gira/push navega engines → SUBHOME
    • Nivel 1 (SUBHOME): ENC L/R ajusta cutoff/resonance, NAV push → GROUP_VIEW
    • Nivel 2 (GROUP_VIEW): ENC NAV cicla grupos, ENC L mueve cursor, ENC R edita valor
    - Fix handle_buttons() B2 (MODE TOGGLE): resetea g_synth_level=0 al entrar SYNTH,
    g_fx_view=FX_SELECT al volver a FX
    - Fix handle_buttons() B1 (HOME): mode-aware — en SYNTH resetea a ENGINE_LIST,
    en FX resetea a FX_SELECT
2026-05-27 fix(synth-nav): B2 mode toggle + live value labels en GROUP VIEW OSC
    bridge_handlers:
    - Agrega s_synth_cache[3][4][4] — cache completa de todos los params synth
    (antes solo se guardaba cutoff/resonance de FILTER)
    - Nuevo getter bridge_get_synth_param_cached(engine, group, pidx)
    - Popula la cache en on_param_changed() para byte-alto 0x10-0x12
    view_03_osc:
    - Almacena s_row_val[4] (punteros a value labels, antes se perdían)
    - row_value_str() ahora recibe el valor explícitamente (no lee bridge)
    - Create: inicializa cada fila con bridge_get_synth_param_cached() → valores
    correctos al entrar, no solo el último valor global
    - Timer osc_timer_cb: detecta cambio de bridge_get_last_real_pa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
    [bridge_handlers.cpp]
2026-05-27 fix(sk28): B2 toggle real FX↔SYNTH con g_display_mode
    Agrega g_display_mode (inicia en 1=SYNTH) que cicla con cada press de B2.
    Antes B2 siempre enviaba 0xFD=0 (FX fijo), sin posibilidad de volver a SYNTH.
    Ahora: press→FX, press→SYNTH, press→FX, etc.
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2026-05-27 feat(view-03-osc): engine-aware con VU vertical + viz por param
    view_03 ahora construye sus páginas dinámicamente según el engine activo
    leyendo bridge_get_engine_id(). Cada engine tiene su propio set de OSC params
    con visualizaciones especializadas:
    Engines soportados:
    Moog Model D (0x10): VCO1 WAVE / TRANSPOSE / VCO2 WAVE / DETUNE (4 pages)
    Juno-106 (0x11): VCO WAVE / SUB LEVEL / NOISE (3 pages)
    Prophet-5 (0x12): OSC A WAVE / OSC B WAVE / B INTERVAL / CROSSMOD (4)
    Nuevos tipos de viz (todos respetan el slider hero del sprint anterior):
    VIZ_WAVE — canvas con onda animada (ya existente, refactorizado)
    VIZ_OCT — VU vertical track 16×110 con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
2026-05-27 feat(sketch28): fix AudioMemory bug + add USB device MIDI from computer
    AudioMemory race condition: moog.begin() was calling AudioMemory(20) after
    the sketch had already called AudioMemory(40), overwriting the pool with
    only 20 blocks. Moved ownership to the sketch — begin() no longer allocates.
    USB device MIDI: poll usbMIDI in loop() to accept MIDI from computer/DAW
    via micro-USB (USB_MIDI_AUDIO_SERIAL). Connects to the same midi_note_on/
    off/cc callbacks as the USB-A host path, enabling testing without a
    physical MIDI keyboard.
2026-05-27 feat(display): fix INTERVAL boxes + redesign ENV/LFO with animated slider
    view_03 (OSC): Split INTERVAL label — number in HERO_XL (64px, digits only),
    "ST" suffix in HERO (36px, full ASCII). ibm_plex_mono_64 subset only has 0-9
    A-G #, causing S/T to render as rectangles.
    view_04 (ENV): Full redesign with gf_param_slider (4 pages: A/D/S/R).
    Each page shows the complete ADSR curve with its segment highlighted (teal+,
    width=3) and an animated white dot sweeping through the segment. Cursor speed
    mirrors the actual param value — slow attack = slow cursor. Value labels:
    A/D/R in "250 MS" / "2.5 S" format; S in "75%".
    view_05 (LFO): Full redesign with gf_param_slider + engine-aware layout.
    Mo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
2026-05-28 feat(enclosure): Z-UP unified build script con cheeks proud 2mm sobre panel
    Añade `build-all-zup.py` — script canónico Z-UP que construye los 5 cuerpos
    del enclosure en un único documento Fusion 360 con coordenadas verificadas.
    Decisiones de diseño implementadas:
    - H_CHEEK=42mm (H+0.4): bloques de guadua sobresalen 2mm por encima del panel
    de aluminio (Z=40) — efecto Moog/Elektron, guadua visible como accent
    - Panel aluminio 168mm (X[-8.4,+8.4]): footprint reducido de ±9.0 a ±8.4
    para eliminar overlap X con cheeks de 42mm en X=±8.4..±9.6
    - Puertos de audio/MIDI cortados directamente en la cara de guadua (Option A)
    Fixes técnicos incorporados vs scripts individuales Y-UP:
    -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
2026-05-28 fix(enclosure): encoder shaft+LED ring, cheek cutouts reales, deprecar Y-UP
    build-all-zup.py — 3 fixes:
    1. Top panel encoder: reemplaza ventana Ø32mm por orificio eje Ø7mm +
    anillo de 12 orificios Ø2.5mm a R=12mm (patrón tipo Elektron/Moog).
    La guadua protruye 2mm visible; los LEDs iluminan desde abajo a través
    de los orificios — sin ventana abierta que se vea anti-estética.
    2. Cheeks cutouts: reemplaza patrón NewBody+CombineFeature por
    CutFeatureOperation directo con participantBodies — el patrón
    anterior generaba cuerpos sin intersección y los cortes no aparecían.
    Fix aplica a Part 03 (TRS IN L/R + AUX) y Part 04 (TRS OUT + USB-C).
    3. Heat inserts cheek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
2026-05-29 feat(sprints 38-45): 3 engines + D'Angelo filter + Juno poly + Layer 1 AI completo + AI Mode consolidation
    ## Engines (Sprints 38-41)
    - feat(engines): add OB-6 (6 voices, SVF LP, sub osc, FIFO stealing)
    - feat(engines): add DX7 (6 voices, 2-op FM, AudioSynthWaveformModulated)
    - feat(engines): add ARP 2600 (4 voices, ring modulator AudioEffectMultiply)
    - feat(engines): refactor Juno-106 mono → 6-voice poly, chorus on master bus
    - feat(engines): add VCO3 to Moog Model D (independent waveform + semitone interval)
    - feat(audio): MoogLadder4P — D'Angelo & Välimäki ICASSP 2013 nonlinear ladder filter
    replaces AudioFilterStateVariable in all 6 engines (5 tanh/sample, bilinear integrator)
    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
    [audio_graph.cpp]
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
